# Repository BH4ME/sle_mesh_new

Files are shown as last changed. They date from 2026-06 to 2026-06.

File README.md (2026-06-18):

# sle_mesh_new

WS63 SLE mesh firmware, board Web UI, browser Web UI, flashing tools, debug automation, and CAD STL assets.

Current packaged line: `v4.5.56-minimal`

## What Is Included

| Area | Path | Purpose |
| --- | --- | --- |
| WS63 firmware app | `xc/ws63_team_network/` | Unified leader/member/relay firmware, ST7789/LVGL display task, WS2812 status LED, GPS/location hooks, battery/ADC hooks, and board HTTP service. |
| Shared protocol/core | `include/`, `src/` | Portable SLE team packet, node state machine, CLI, location, relay optimizer, NMEA parser, and Web API code. |
| Web UI | `webui/` | Browser/board Web UI source and API contract tests. |
| Flash tools | `scripts/flash/`, `tools/xf_burn_tools/`, `automation/ws63/tools/ws63_auto_burn.py` | Windows and Python flashing workflows for WS63 `.fwpkg` images. |
| Build tools | `scripts/build/`, `automation/ws63/tools/ws63_remote_build_v4.py` | Local/remote SDK build wrappers and post-build guards. |
| Debug/test automation | `automation/ws63/`, `scripts/sim/`, `examples/` | Serial probes, exact-version audit, relay recovery hardware tests, double-reset tests, simulator and C regressions. |
| Hardware docs | `hardware/`, `docs/` | Board/enclosure documentation, schematics notes, task book, and repository docs. |
| CAD STL models | `cad/stl/` | Only the latest three versioned enclosure STL model sets. |
| Release firmware | `release/firmware/` | Latest known built package for direct flashing. |
| Release evidence | `release/evidence/` | Compact JSON summaries for hardware proof runs. |

## Current Hardware-Proven Status

`v4.5.56-minimal` is the current proof line with same-firmware compatibility fingerprint `SLE_TEAM_FW_COMPAT 0x0556U`.

The exact-version 8-board relay recovery run passed:

- Summary: `release/evidence/v4_5_56_exact8_relay_recovery_summary.json`
- Leader: `COM51`, route `166`, suffix `227F`
- Members: `COM32/175`, `COM40/127`, `COM42/81`, `COM47/181`, `COM50/158`, `COM52/182`, `COM58/37`
- Initial relay: `COM42/81`
- Replacement relay after relay reboot: `COM52/182`
- Old relay `81` returned as a non-relay member under relay `182`
- Final relay set: `[182]`
- No `Oops`, exception, NMI, or runtime reboot markers were found in the proof logs

The same board pool also printed SoftAP, HTTP, LVGL backend, and ST7789 startup logs. AP client visibility scanning was intentionally not performed for this proof pass. WS2812 color/brightness has no readback channel, so final LED appearance still requires physical observation on real boards.

## Flash The Included Firmware

Firmware package:

```text
release/firmware/ws63-liteos-app_v4_unified_all_v4.5.56-minimal.fwpkg
```

Windows multi-port flash:

```powershell
powershell -NoProfile -ExecutionPolicy Bypass -File scripts/flash/ws63_flash_multi.ps1 `
  -Ports COM32,COM40,COM42,COM47,COM50,COM51,COM52,COM58 `
  -Parallel `
  -Firmware release\firmware\ws63-liteos-app_v4_unified_all_v4.5.56-minimal.fwpkg `
  -ExpectedVersion v4.5.56-minimal
```

Single-port Python burn:

```powershell
python automation\ws63\tools\ws63_auto_burn.py `
  -p COM51 `
  -b 115200 `
  --software-reset-only `
  --reset-command reboot `
  release\firmware\ws63-liteos-app_v4_unified_all_v4.5.56-minimal.fwpkg
```

Audit exact versions and idle state:

```powershell
python automation\ws63\tools\ws63_audit_versions_and_idle_bad.py `
  --ports COM32 COM40 COM42 COM47 COM50 COM51 COM52 COM58 `
  --expected-fw v4.5.56-minimal
```

## Run Relay Recovery Hardware Test

```powershell
python automation\ws63\tools\ws63_multi_board_relay_recovery_test.py `
  --leader-port COM51 `
  --member-ports COM32 COM40 COM42 COM47 COM50 COM52 COM58 `
  --expected-fw v4.5.56-minimal `
  --team-id 159 `
  --channel 189 `
  --direct-cap 3 `
  --log-dir logs\hardware\v4_5_56_exact8_relay_recovery
```

## Build Firmware

Remote Ubuntu SDK build:

```powershell
python automation\ws63\tools\ws63_remote_build_v4.py `
  --host <ubuntu-host> `
  --user <ubuntu-user> `
  --password <password>
```

Do not commit local credentials. The build wrapper performs source and package guards for the active proof line.

## Web UI

```powershell
npm --prefix webui install
npm --prefix webui test
npm --prefix webui run build
```

The board HTTP/Web code is in `xc/ws63_team_network/src/ws63_team_http.*` and the browser UI is in `webui/src/`.

## Local Validation

```powershell
python -m unittest discover -s automation/ws63/tests -t .
python -m py_compile automation/ws63/tools/ws63_remote_build_v4.py automation/ws63/tools/ws63_auto_burn.py
bash scripts/sim/simulate_v2.sh --suite=core
git diff --check
```

## Repository Notes

- Full hardware logs, temporary build outputs, local planning files, and large generated CAD formats are intentionally excluded from Git.
- STL files are included under `cad/stl/`; only the latest three versioned model sets are kept.
- LVGL core source needed by the firmware build is vendored under `xc/ws63_team_network/third_party/lvgl/`; demo/media assets are intentionally omitted.
- The repository is intended to be a clean handoff package, not the full local laboratory log archive.

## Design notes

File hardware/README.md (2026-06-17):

# Hardware

这个目录用于存放 SLE 项目的硬件资料和可制造文件。硬件资料与固件源码、自动化脚本分开管理，避免仓库根目录堆放临时模型或草稿文件。

## 目录

- [enclosures/](enclosures/)：3D 打印外壳、STEP/STL、预览图和源模型脚本。
- `boards/`：预留给 PCB、Gerber、BOM、装配图和板卡 3D 模型。
- `schematics/`：预留给原理图、接口定义和硬件审查记录。

## 当前硬件资料

- [boards/sle-main-board/v3.3](boards/sle-main-board/v3.3/)：2026-06-16 SLE 主板 PCB PDF 和板卡预览图。
- [schematics/sle-main-board/v3.3](schematics/sle-main-board/v3.3/)：2026-06-16 SLE 主板原理图 PDF。

## 版本规则

- 每个可制造硬件版本放在独立目录，例如 `hardware/enclosures/sle-pcb-enclosure/v1.1.4/`。
- 每个版本至少包含 `README.md` 和 `MANIFEST.md`。
- STEP/STL/PNG 等二进制或大型制造文件按类型放入 `step/`、`stl/`、`preview/`。
- 草稿、临时预览、审查截图和未确认模型不要直接放仓库根目录，确认可发布后再整理进本目录。

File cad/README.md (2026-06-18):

# CAD Assets

This directory contains the STL files kept for the handoff repository.

- `stl/models/...` contains only the latest three versioned enclosure model sets:
  - `sle_enclosure_v2.1.17_no_screen_top_lock`
  - `sle_enclosure_v2.1.18_no_screen_top_lock_harder`
  - `sle_enclosure_v2.1.19_screen_top_lock`

Large STEP/GLB simulation exports are intentionally excluded from Git. Re-add them through release assets or Git LFS if they become required for mechanical handoff.

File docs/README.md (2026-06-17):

# Documentation Index

这里是 SLE 项目的文档入口。

## 仓库维护

- [repository_layout.md](repository_layout.md)：仓库目录结构和边界。
- [version_management.md](version_management.md)：仓库、固件和硬件版本管理规则。
- [branch_strategy.md](branch_strategy.md)：分支角色和合并策略。
- [../versions/README.md](../versions/README.md)：版本记录索引。
- [../meta/PROJECT_OPERATION_SOP.md](../meta/PROJECT_OPERATION_SOP.md)：项目操作 SOP。

## 阶段文档

- [v0/README.md](v0/README.md)：V0 baseline。
- [v1/README.md](v1/README.md)：V1 manual relay approval。
- [v2/README.md](v2/README.md)：V2 automatic networking。
- [v3/README.md](v3/README.md)：V3 phone location bridge。
- [v4/README.md](v4/README.md)：V4 WS63 module、ST7789 display、offline reporting。

## 硬件资料

- [../hardware/README.md](../hardware/README.md)：硬件资料和制造文件入口。
- [../hardware/enclosures/README.md](../hardware/enclosures/README.md)：3D 打印外壳版本。

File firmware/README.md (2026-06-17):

# Firmware

固件代码按 SDK 工程边界管理。

## 当前固件工程

- [../xc/ws63_team_network/](../xc/ws63_team_network/)：WS63 SLE team network 固件工程，包含板端 WebUI、ST7789 显示、SLE leader/member/relay 运行时配置逻辑。
- [../xc/bearpi_pico_h3863_blinky/](../xc/bearpi_pico_h3863_blinky/)：BearPi Pico H3863 blinky / flash notes 辅助工程。

## 协议共享代码

- [../include/](../include/)：公共头文件。
- [../src/](../src/)：协议、组网状态机、CLI/Web API 序列化。
- [../examples/](../examples/)：本地 C 回归和接入示例。

## 版本边界

- 当前固件版本：`v4.4.129`，定义在 `xc/ws63_team_network/src/ws63_team_network_app.c`。
- 当前仓库整理记录：`v4.4.129`，见 [../versions/v4.4.129/VERSION.md](../versions/v4.4.129/VERSION.md)。
- 构建产物不提交到 Git；远程构建输出默认写入 `output_from_vm/`。

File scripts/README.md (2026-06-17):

# Scripts

脚本按用途隔离，根目录不再直接堆放可执行脚本。

## 分类

- [build/](build/)：固件构建脚本，包括远程 Ubuntu、VM、WSL 构建入口。
- [flash/](flash/)：烧录脚本，包括单板和多串口烧录。
- [serial/](serial/)：串口运行时配置脚本。
- [sim/](sim/)：协议和 relay 行为仿真脚本。
- [test/](test/)：测试总入口和系统级编排入口。
- [review/](review/)：文档/代码审查辅助脚本。

## 常用入口

```sh
scripts/build/ws63_build_v4_ubuntu.sh unified
scripts/sim/simulate_v2.sh --suite=python --stress=1
python -m unittest discover -s automation/ws63/tests -t .
```

```powershell
powershell -ExecutionPolicy Bypass -File scripts/serial/ws63_serial_cfg.ps1 -Port COM16 -Mode status
powershell -NoProfile -ExecutionPolicy Bypass -File scripts/flash/ws63_flash_multi.ps1 -Ports COM16,COM13,COM17,COM18 -Parallel
```

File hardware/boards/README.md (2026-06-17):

# Boards

这里预留给 SLE 硬件板卡资料。

## 当前资料

- [sle-main-board/v3.3](sle-main-board/v3.3/)：2026-06-16 SLE 主板 PCB PDF 和预览图。

建议每块板按版本建目录，例如：

```text
hardware/boards/sle-main-board/v1.0.0/
```

每个版本建议包含：

- `README.md`：板卡用途、版本摘要、接口说明。
- `MANIFEST.md`：Gerber、BOM、装配图、3D 模型和验证记录清单。
- `gerber/`：可制造 Gerber/钻孔文件。
- `bom/`：BOM 和替代料说明。
- `assembly/`：装配图、位号图、生产注意事项。
- `step/`：板卡 3D 模型。

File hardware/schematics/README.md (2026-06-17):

# Schematics

这里预留给原理图、接口定义和硬件审查记录。

## 当前资料

- [sle-main-board/v0.1](sle-main-board/v0.1/)：早期 SLE 主板原理图参考。
- [sle-main-board/v3.3](sle-main-board/v3.3/)：2026-06-16 SLE 主板原理图 PDF。

建议按硬件版本保存，例如：

```text
hardware/schematics/sle-main-board/v1.0.0/
```

原理图 PDF、接口表、已确认的问题记录和修改建议都应放在对应版本目录中，避免散落在仓库根目录。

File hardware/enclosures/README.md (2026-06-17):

# Enclosures

这个目录保存 SLE 设备的 3D 打印外壳版本。

## 当前外壳

- [sle-pcb-enclosure/v1.1.4](sle-pcb-enclosure/v1.1.4/)：一体式外壳 + 电池滑盖，已整理为首个公开制造版本。

## 命名

- 外壳系列目录：`sle-pcb-enclosure`
- 版本目录：`v<major>.<minor>.<patch>`
- 文件名保留版本号，便于单独下载后仍能识别来源。

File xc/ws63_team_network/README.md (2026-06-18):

# WS63 Team Network Firmware

这是当前 WS63 SLE team network 板端固件工程。

## 当前版本

- 固件版本：`v4.4.134`
- 仓库整理记录：`v4.4.134`
- 版本说明：[../../versions/v4.4.134/VERSION.md](../../versions/v4.4.134/VERSION.md)
- 仓库结构说明：[../../docs/repository_layout.md](../../docs/repository_layout.md)

## 功能

- 统一固件包：leader/member 角色运行时配置。
- 板端 SoftAP + HTTP WebUI。
- 串口 `cfg` 命令配置角色、team、channel 和 leader suffix。
- leader/member/relay 自适应连接与中继。
- ST7789 显示在线状态和成员事件。
- WS2812、蜂鸣器、GPS pinmap、HTTP API 等板级能力。

## 串口命令

```text
cfg status
cfg leader now <team> <channel>
cfg member now <leader_suffix_hex> <team> <channel>
cfg apply
cfg clear
cfg reboot
reboot
reset
```

Windows 辅助脚本：

```powershell
powershell -ExecutionPolicy Bypass -File scripts/serial/ws63_serial_cfg.ps1 -Port COM16 -Mode leader -Team 7 -Channel 33
powershell -ExecutionPolicy Bypass -File scripts/serial/ws63_serial_cfg.ps1 -Port COM13 -Mode member -LeaderSuffix 9A2F -Team 7 -Channel 33
powershell -ExecutionPolicy Bypass -File scripts/serial/ws63_serial_cfg.ps1 -Port COM13 -Mode status
```

## 板端 WebUI

```text
SSID: SLE-XXXX
Password: 123456789
URL: http://192.168.43.1/
```

常用 API：

- `GET /api/status`
- `GET /api/power`
- `GET /api/nodes`
- `GET /api/events`
- `GET /api/pending`
- `GET /api/config/status`
- `GET /api/config/leader?team=1&channel=17&now=1`
- `GET /api/config/member?leader=C7E9&team=1&channel=17&now=1`
- `GET /api/config/apply`
- `GET /api/config/clear`
- `GET /api/config/reboot`
- `GET /api/pairing?action=start|stop|approve&id=...&relay=0|1`
- `GET /api/member/select?team=...&leader=...&channel=...`
- `GET /api/member/leave`
- `GET /api/factory-reset`

## 构建

推荐使用仓库根目录的远程构建脚本：

```sh
scripts/build/ws63_build_v4_ubuntu.sh unified
```

输出固件包：

```text
output_from_vm/team_network_v4_unified_runtime_role/ws63-liteos-app_v4_unified_all.fwpkg
```

## 目录

- `src/`：板端应用、显示、LED 等实现。
- `sle_uart_client/`：leader/client/central 侧 SLE UART 适配。
- `sle_uart_server/`：member/server/peripheral 侧 SLE UART 适配。
- `third_party/lvgl-patches/`：WS63 LVGL 适配补丁。
- `CMakeLists.txt`、`Kconfig`：SDK 工程集成入口。

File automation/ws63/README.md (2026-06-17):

# WS63 Automation

`automation/ws63/` 是 WS63 自动化工具链，负责烧录编排、串口预检、角色绑定和多板 relay 测试。它与固件源码、仿真脚本和通用工具分开管理。

## 目录结构

- `tools/`
  - `ws63_auto_burn.py`：自动复位烧录工具，支持串口 `reboot` 和 DTR/RTS 控制序列。
  - `ws63_flash_bind_team.py`：批量烧录并绑定角色。
  - `ws63_four_board_relay_test.py`：四板 leader/member/relay 场景测试。
  - `ws63_link_cycle_test.py`：member 生命周期、重启、leave/rejoin 测试。
  - `ws63_relay_cycle_test.py`：relay 重启和 relay 自举场景测试。
  - `ws63_remote_build_v4.py`：Python/Paramiko 远程构建入口。
  - `ws63_serial_preflight.py`：串口测试前置检查。
- `scripts/`
  - `ws63_test_system.sh`：自动化总入口。
- `tests/`
  - 自动化工具单元测试。

## 与其他目录的边界

- 固件构建脚本：`scripts/build/`
- 烧录脚本：`scripts/flash/`
- 串口配置脚本：`scripts/serial/`
- 仿真脚本：`scripts/sim/`
- 通用仿真工具：`tools/sle_team_python_sim.py`

## 常用命令

```sh
python -m unittest discover -s automation/ws63/tests -t .
bash automation/ws63/scripts/ws63_test_system.sh --with-relay-cycle --ports COM16,COM13,COM17
```

```powershell
python automation/ws63/tools/ws63_auto_burn.py -p COM16 -b 115200 --software-reset-only output_from_vm/team_network_v4_unified_runtime_role/ws63-liteos-app_v4_unified_all.fwpkg
```

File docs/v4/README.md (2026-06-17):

# V4 Documentation

`docs/v4/` 记录 WS63 模块、ST7789 显示、板端 WebUI、运行时角色配置和 relay 组网验证相关内容。

## 当前主线

- 当前固件版本：`v4.4.129`
- 最新仓库整理记录：`v4.4.129`
- 固件工程：[../../xc/ws63_team_network/](../../xc/ws63_team_network/)
- 硬件原理图：[../../hardware/schematics/sle-main-board/v0.1/](../../hardware/schematics/sle-main-board/v0.1/)
- 远程构建脚本：[../../scripts/build/ws63_build_v4_ubuntu.sh](../../scripts/build/ws63_build_v4_ubuntu.sh)
- 烧录脚本：[../../scripts/flash/](../../scripts/flash/)
- 仿真脚本：[../../scripts/sim/](../../scripts/sim/)

## V4 能力边界

- 所有 WS63 节点烧录同一份统一固件包。
- leader/member 角色通过 WebUI 或串口 `cfg` 命令在运行时配置。
- leader 支持 pending/member 管理、配队窗口、allowlist 和成员在线/离线事件。
- member 可直连 leader，也可在 leader 直连容量受限时通过 relay 转发。
- relay 选择由固件根据连接状态、RSSI 和 relay budget 自适应处理。
- ST7789 显示用于角色、在线状态、成员事件和故障提示。

## 常用入口

```sh
scripts/build/ws63_build_v4_ubuntu.sh unified
scripts/sim/simulate_v2.sh --suite=python --stress=1
python -m unittest discover -s automation/ws63/tests -t .
```

```powershell
powershell -ExecutionPolicy Bypass -File scripts/serial/ws63_serial_cfg.ps1 -Port COM16 -Mode status
powershell -NoProfile -ExecutionPolicy Bypass -File scripts/flash/ws63_flash_multi.ps1 -Ports COM16,COM13,COM17,COM18 -Parallel
```

## 历史记录

详细发布历史见 [../../versions/README.md](../../versions/README.md)。当前仓库结构以 [../repository_layout.md](../repository_layout.md) 和根目录 [../../README.md](../../README.md) 为准。

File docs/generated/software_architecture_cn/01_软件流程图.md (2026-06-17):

# 01 软件流程图

本节描述当前 `v4.5.46-minimal` 软件从启动到运行的主流程。系统核心由两个主要任务组成：

- `TeamNetworkTask`：负责组网、SLE 收发、HTTP、CLI、GPS、状态 LED、核心状态机 tick。
- `TeamDisplayTask`：负责 ST7789/LVGL 初始化、状态页面刷新、事件页面刷新。

## 软件启动流程

```mermaid
flowchart TD
    Boot["固件启动"] --> Entry["team_network_entry"]
    Entry --> SpawnDisplay["创建 TeamDisplayTask"]
    Entry --> SpawnNetwork["创建 TeamNetworkTask"]

    SpawnDisplay --> DisplayInit["初始化 ST7789 / LVGL"]
    DisplayInit --> DisplayLoop["显示循环: 读取快照 -> 刷新状态/事件 -> tick"]

    SpawnNetwork --> Bootstrap["team_network_task_bootstrap"]
    Bootstrap --> LedInit["初始化 WS2812 状态灯"]
    Bootstrap --> GpsInit["初始化 GPS/NMEA"]
    Bootstrap --> Identity["读取 MAC 并生成 route_id/self_label"]
    Bootstrap --> HttpStart["启动 SoftAP HTTP 服务"]
    Bootstrap --> UartCli["启动 UART CLI"]
    Bootstrap --> NvRestore["读取 NV 保存的角色配置"]
    NvRestore --> RoleConfigured{"是否已有角色配置?"}

    RoleConfigured -- 否 --> Idle["保持未配置状态, 等待 Web/CLI 配置"]
    RoleConfigured -- 是 --> ConfigureRole["配置 leader 或 member 角色"]
    ConfigureRole --> SleStart["启动 SLE client/server"]
    SleStart --> MainLoop["进入 TeamNetworkTask 主循环"]
    Idle --> MainLoop
```

## 主循环流程

```mermaid
flowchart TD
    Loop["TeamNetworkTask 每 10ms 循环"] --> Cli["处理 CLI 队列"]
    Cli --> ClientTick["SLE client tick"]
    ClientTick --> Configured{"角色已配置?"}

    Configured -- 否 --> Sleep["sleep 10ms"]
    Configured -- 是 --> NodeTick["sle_team_node_tick"]

    NodeTick --> Role{"当前角色"}
    Role -- Leader --> LeaderScan["更新 leader 扫描策略"]
    LeaderScan --> RelayOpt["每 8s 尝试稳定态 relay 优化"]
    RelayOpt --> RelayClient["检查 relay client 是否需要启动/暂停"]

    Role -- Member --> RelayClient

    RelayClient --> GpsTick["GPS 定位上报 tick"]
    GpsTick --> LedTick["WS2812 状态刷新"]
    LedTick --> DisplayPub["发布显示状态快照"]
    DisplayPub --> Sleep
```

## 收包处理流程

```mermaid
flowchart TD
    Rx["SLE 收到数据"] --> DecodeMesh["解码 Mesh Packet"]
    DecodeMesh --> Unwrap["解 GROUP_DATA: channel_hash / cipher_mac / app_payload"]
    Unwrap --> DecodeApp["解码 App Packet"]
    DecodeApp --> Check["校验 team_id / channel_hash / leader_term"]
    Check --> NeedForward{"是否不是发给自己?"}

    NeedForward -- 是 --> Forward["relay 节点转发"]
    NeedForward -- 否 --> Dispatch["按 app_msg_type 分发"]

    Dispatch --> Hello["HELLO: 入网/重入网"]
    Dispatch --> Ack["ACK: 确认策略下发"]
    Dispatch --> Config["CONFIG: 更新心跳/relay 参数"]
    Dispatch --> Route["ROUTE_UPDATE: 更新 parent/next_hop"]
    Dispatch --> Heartbeat["HEARTBEAT: 更新 last_seen/RSSI/在线状态"]
    Dispatch --> Pos["POS_REPORT: 更新位置"]
    Dispatch --> Alert["ALERT: 离队/超时/低电量等告警"]
```

## 发送流程

```mermaid
flowchart TD
    Business["业务消息: HELLO/HEARTBEAT/POS/ALERT/CONFIG/ACK/ROUTE_UPDATE"] --> AppBuild["编码 App Packet"]
    AppBuild --> GroupWrap["封装 GROUP_DATA"]
    GroupWrap --> MeshWrap["封装 Mesh Packet"]
    MeshWrap --> Role{"发送节点角色"}

    Role -- Leader --> FindConn["按 dst_id / next_hop 找 SLE client 连接"]
    Role -- Member --> Upstream["通过 server 连接发给 parent/leader"]
    Role -- Relay --> Downstream["relay 可通过 client 连接发给 child"]

    FindConn --> SleSend["WS63 SLE 发送"]
    Upstream --> SleSend
    Downstream --> SleSend
```

## 状态显示流程

```mermaid
flowchart TD
    NetworkTask["TeamNetworkTask"] --> PublishStatus["发布 role/self/online/offline/event_count"]
    NetworkTask --> PublishEvent["发布 join/rejoin/lost/left 事件"]
    PublishStatus --> Shared["共享显示快照"]
    PublishEvent --> Shared
    Shared --> DisplayTask["TeamDisplayTask"]
    DisplayTask --> ShowStatus["ws63_st7789_show_status"]
    DisplayTask --> ShowEvent["ws63_st7789_show_event"]
    DisplayTask --> Tick["ws63_st7789_tick"]
    Tick --> Panel["ST7789 屏幕"]
```

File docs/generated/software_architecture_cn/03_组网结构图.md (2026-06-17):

# 03 组网结构图

本节描述当前系统的正常组网结构。系统采用 leader 集中式组网，leader 持有成员表并统一分配拓扑。

## 正常拓扑

```mermaid
flowchart TD
    Leader["Leader"] --> Direct1["直连 Member A"]
    Leader --> Direct2["直连 Member B"]
    Leader --> Relay1["Relay Member"]
    Relay1 --> Child1["Relay Child 1"]
    Relay1 --> Child2["Relay Child 2"]
```

## 组网角色

| 角色 | 职责 |
|---|---|
| Leader | 维护成员表、扫描入网、分配 parent/next_hop、下发 CONFIG/ROUTE_UPDATE、处理掉线恢复 |
| Member | 向 leader 发 HELLO/HEARTBEAT/POS，按 leader 指令工作 |
| Relay Member | 既是 member 又是 child 转发节点，承担下游连接 |
| Relay Child | 挂在 relay 下面的普通成员 |

## 组网规则

```mermaid
flowchart TD
    Candidate["节点开始入网"] --> Hello["发送 HELLO"]
    Hello --> LeaderCheck["Leader 检查 team/channel/fw_compat"]
    LeaderCheck --> Allowed{"是否允许入队?"}

    Allowed -- 否 --> Reject["拒绝或进入 pending"]
    Allowed -- 是 --> Decide["决定 parent"]

    Decide --> DirectFree{"leader 直连是否未满?"}
    DirectFree -- 是 --> ParentLeader["parent = leader"]
    DirectFree -- 否 --> PickRelay["选择在线 relay"]
    PickRelay --> ParentRelay["parent = relay / next_hop = relay"]

    ParentLeader --> SendPolicy["下发 CONFIG + ROUTE_UPDATE"]
    ParentRelay --> SendPolicy
    SendPolicy --> Ack["收到 ACK 或 live packet 确认"]
    Ack --> Online["节点 ONLINE"]
```

## 直连容量

当前逻辑中 leader 默认直连容量为 7，见 [sle_team_node.c](E:/codex_documents/sle/src/sle_team_node.c:4)。当直连数达到上限时，leader 会优先选择一个在线且允许 relay 的成员升级为 relay，再把后续成员挂到该 relay 下。

## 版本隔离

每个 HELLO 都携带 `fw_compat`，leader 在处理入网时会校验兼容指纹。这样不同 proof line 的固件不会在同一队伍里混连。

## 任务边界

- `TeamNetworkTask` 负责组网决策和成员表更新。
- `TeamDisplayTask` 只负责展示，不参与组网。
- HTTP 和串口只是控制入口，不改变组网原则。

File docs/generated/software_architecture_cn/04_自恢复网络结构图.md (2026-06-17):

# 04 自恢复网络结构图

本节描述节点掉线后的自恢复机制。当前系统不是全网重建，而是局部修复受影响的拓扑分支。

## 自恢复总流程

```mermaid
flowchart TD
    Lost["节点掉线/重启/信号丢失"] --> Detect["检测到断连或心跳超时"]
    Detect --> LeaderMark["Leader 标记成员 offline"]
    LeaderMark --> RelayLost{"掉线的是 relay 吗?"}

    RelayLost -- 否 --> MemberRecover["普通 member 重新 HELLO, leader 重新分配 parent"]
    RelayLost -- 是 --> ChildMark["标记 relay 的 child 为恢复候选"]
    ChildMark --> Choose["选择 replacement relay"]
    Choose --> Grant["给 replacement relay 下发 relay 授权"]
    Grant --> Rewire["重挂 child 到新 relay"]
    Rewire --> Resume["原 relay 回来后降级为普通 child"]
```

## relay 掉线恢复结构

```mermaid
flowchart TD
    OldRelay["旧 Relay 掉线"] --> LeaderOffline["Leader 标记 relay offline"]
    LeaderOffline --> Affected["把 parent=旧 Relay 的节点标记为恢复候选"]
    Affected --> Candidate["选择替代 relay"]
    Candidate --> RelayGrant["下发 relay_allowed=1 / relay_tier=1"]
    RelayGrant --> NewRelay["新 Relay 接管"]
    NewRelay --> Children["旧 relay 的 child 重新挂到新 Relay"]
    Children --> OldReturn["旧 Relay 恢复上线"]
    OldReturn --> Demote["旧 Relay 降级为普通 child"]
```

## 普通 member 掉线恢复

```mermaid
flowchart TD
    MemberLost["普通 member 掉线"] --> LeaderOffline["Leader 标记 offline"]
    LeaderOffline --> Scan["恢复扫描/重新发现"]
    Scan --> Hello["member 重启后重新发 HELLO"]
    Hello --> Parent["Leader 重新分配 parent / next_hop"]
    Parent --> Config["下发 CONFIG + ROUTE_UPDATE"]
    Config --> Ack["ACK / HEARTBEAT 确认"]
    Ack --> Online["重新 ONLINE"]
```

## 代码中的关键机制

| 机制 | 作用 |
|---|---|
| `sle_team_mark_member_offline()` | 将成员标记为离线，并处理 relay 相关的下游恢复 |
| `sle_team_mark_relay_children_offline()` | relay 掉线时把它的 child 转成恢复候选 |
| `sle_team_assign_parent()` | 决定 member 当前应该挂到 leader 还是 relay |
| `sle_team_handle_hello()` | 节点回来后重新入网和重新下发策略 |
| `sle_team_handle_heartbeat()` | 用心跳更新在线状态并完成恢复确认 |
| `team_leader_drop_stale_direct_conn()` | 清理旧直连残留，防止恢复中拓扑污染 |

## 自恢复原则

1. 只修复受影响分支，不全网重组。
2. 以 leader 为唯一拓扑裁决点。
3. 新策略优先生效，旧连接必须被清理。
4. relay 恢复后默认先降级为普通 child，避免重复抢占拓扑。
5. 通过 ACK、HEARTBEAT、位置包共同确认在线，而不是只靠单一事件。

## 适合文档中的一句话

> 本系统的自恢复组网采用 leader 集中式局部修复策略：当普通 member 掉线时重新分配 parent，当 relay 掉线时只重构其下游分支，并通过 `ROUTE_UPDATE`、`CONFIG`、`ACK` 和心跳包共同完成恢复确认。

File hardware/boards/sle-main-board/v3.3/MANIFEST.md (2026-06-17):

# Manifest: SLE Main Board PCB v3.3

## Files

- `README.md`
- `MANIFEST.md`
- `PCB_PCB1_3_2026-06-16.pdf`
- `preview/layout_render_1.png`
- `preview/layout_render_2.png`

## Source Files

- `/Users/bh4me_macair/Documents/研电赛/v3.3硬件/PCB_PCB1_3_2026-06-16.pdf`
- `/Users/bh4me_macair/Documents/研电赛/v3.3硬件/60443e9e08896b85dec1826dff4f5deb.png`
- `/Users/bh4me_macair/Documents/研电赛/v3.3硬件/acd43c83f5d05ca2e75e8261679cb1cf.png`

## Notes

- Imported into `hardware/boards/sle-main-board/v3.3/` as the SLE main board v3.3 hardware architecture package.
- File names were normalized for stable repository links while keeping source paths above for traceability.

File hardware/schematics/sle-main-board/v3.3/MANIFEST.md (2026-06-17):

# Manifest: SLE Main Board Schematic v3.3

## Files

- `README.md`
- `MANIFEST.md`
- `SCH_Schematic1_3_2026-06-16.pdf`

## Source Files

- `/Users/bh4me_macair/Documents/研电赛/v3.3硬件/SCH_Schematic1_3_2026-06-16(MacBook-Air-4.local的冲突副本1_2026-06-16 10-58-29).pdf`

## Notes

- Imported into `hardware/schematics/sle-main-board/v3.3/` as the SLE main board v3.3 schematic package.
- The source filename was normalized to remove the local conflict-copy suffix while preserving source traceability here.

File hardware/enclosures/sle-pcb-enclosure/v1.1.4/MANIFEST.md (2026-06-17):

# Manifest: SLE PCB Enclosure v1.1.4

## Files

- `README.md`
- `MANIFEST.md`
- `source/sle_enclosure_v1.1.4_source.py`
- `step/sle_enclosure_v1.1.4_one_piece_shell.step`
- `step/sle_enclosure_v1.1.4_battery_slide_cover.step`
- `step/sle_enclosure_v1.1.4_preview.step`
- `stl/sle_enclosure_v1.1.4_one_piece_shell.stl`
- `stl/sle_enclosure_v1.1.4_battery_slide_cover.stl`
- `preview/sle_enclosure_v1.1.4_preview_bottom.png`
- `preview/sle_enclosure_v1.1.4_preview_iso.png`
- `preview/sle_enclosure_v1.1.4_preview_top.png`
- `preview/sle_enclosure_v1.1.4_slide_cover_iso.png`

## Validation

- Source model: copied from the local v1.1.4 enclosure source.
- Printable STL geometry: recorded as watertight, winding consistent, one component for both shell and slide cover.
- STEP files: preview assembly, one-piece shell, and battery slide cover inspection passed before publication.

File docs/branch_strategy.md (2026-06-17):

# Branch Strategy

This repository keeps multiple WS63/SLE directions alive without forcing them
into one mainline.

## Long-lived Branches

| Branch | Purpose | Merge policy |
| --- | --- | --- |
| `main` | Stable repository index, shared docs, and known-good public entry points. | Keep clean. Do not merge lab or direction-specific experiments by default. |
| `line/v1-manual-relay` | V1 manual relay approval flow. | Maintain independently. Cherry-pick only small shared fixes when useful. |
| `line/v2-auto-networking` | V2 automatic networking and relay failover line. | Maintain independently and tag releasable alpha/beta points. |
| `line/v3-phone-location` | V3 phone geolocation bridge and SLE position distribution. | Branch from a suitable V2 point and evolve independently. |
| `lab/ws63-st7789-display` | WS63 ST7789 135x240 TFT display experiments. | Lab-only. Do not merge into V1/V2/V3 unless display becomes a product feature. |

Older temporary development branches may remain only as local history. The
`line/...`, `release/...` and `lab/...` names are the canonical working branches
going forward.

## Release Markers

Use tags to freeze points that are known to build or demonstrate a feature:

- `v1.x.y` for the V1 line.
- `v2.0.0-alphaN` for V2 automatic networking.
- `v3.0.0-alphaN` for V3 phone location work.
- `display-st7789-alphaN` for display-only lab checkpoints.

Each tagged point should document:

- What the branch demonstrates.
- How to build or flash it.
- Which validation command or board test was run.

## Daily Workflow

1. Choose the branch that matches the goal before editing.
2. Keep feature commits on that branch.
3. Push the branch directly to GitHub for backup and review.
4. Use PRs only when intentionally moving changes between branches.
5. Prefer cherry-picking small shared fixes over merging whole experimental lines.

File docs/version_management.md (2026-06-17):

# Version Management

## 版本类型

- 仓库记录版本：记录目录整理、脚本布局、文档和硬件资料等仓库层面的变化。
- 固件版本：记录会影响 WS63 固件行为或烧录包的变化。
- 硬件版本：记录 PCB、外壳、装配资料和可制造文件的变化。

## 当前状态

- 最新仓库记录：`v4.4.129`
- 当前固件版本：`v4.4.129`
- 当前外壳版本：`hardware/enclosures/sle-pcb-enclosure/v1.1.4`

## 发布规则

- 固件行为变化时，同步更新固件源码中的版本字符串、`versions/<version>/VERSION.md` 和 `MANIFEST.md`。
- 仅目录、文档、脚本布局变化时，可以更新仓库记录版本，但不要冒充固件升级。
- 硬件资料发布时，在 `hardware/<category>/<name>/<version>/` 下放置 `README.md` 和 `MANIFEST.md`。
- 每次提交前执行与变更范围匹配的校验，例如脚本单测、WebUI 测试、仿真或远程构建。

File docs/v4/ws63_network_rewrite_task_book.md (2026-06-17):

# WS63 Minimal Networking Rewrite Task Book

## Decision

Stop patching the existing staged/frozen topology networking code. Delete the old networking strategy layer and rewrite the smallest usable leader/member/relay logic from a blank design.

This task book replaces the previous staged rewrite plan. The old plan is no longer the target.

## What "Delete All Networking" Means

Delete the old group-networking algorithm and its patch chain:

- staged leader states such as `DISCOVERING`, `FREEZING`, `PROVISIONING`, and `STABLE`;
- frozen topology planning;
- topology policy queues;
- stable rejoin leases;
- failover windows;
- route hint caches;
- provisional physical peer authorization tricks;
- relay auto-promote/rebalance/swap logic;
- special HELLO/JOINED/temporary-direct patch paths.

Keep only the non-negotiable firmware base needed to build and test:

- SLE UART client/server transport drivers;
- packet encode/decode helpers;
- UART CLI, status output, build, flash, and readback tools;
- board identity, version, and anti-pollution cleanup.

If a retained file still contains old networking decisions, remove those decisions from that file.

## Minimal Target

The first rewrite target is not clever. It is a small deterministic network:

1. Leader discovers members.
2. Leader assigns each member exactly one parent:
   - parent is the leader while stable direct slots are available;
   - otherwise parent is one currently online leader-direct relay.
3. Member accepts only the latest leader policy.
4. Relay forwards packets between its children and the leader. It does not choose topology.
5. Heartbeat timeout marks a member offline.
6. A rejoining member is treated as fresh and receives a new parent assignment.

Stable-state rule: no global regrouping, no periodic rebalance, and no parent movement just to improve topology.

Loss-handling rule: real natural loss is not stable-state rebalance. Single-member loss, double-member loss, and relay loss must recover through fresh leader policy without shrinking the intended member count.

No stale parent or relay role may be reused unless the leader sends it again.

## Hard Limits

- Leader stable direct capacity is `direct_cap=7`.
- WS63 physical max is 8 links; one physical slot may be used as a temporary admission link.
- Do not reduce the desired member count to make tests pass.
- Natural loss means reboot, power loss, or distance/signal loss, not active `leave`.
- Failed-burn, wrong-version, or no-status boards must not join validation. They must be idle/unconfigured or excluded.
- Single-member and double-member natural loss must recover without shrinking the intended member set.
- Every fresh connection or reconnection must be treated as a policy event: the leader recalculates whether that node should be direct or relayed and sends a fresh assignment.
- In stable state, do not rebalance, regroup, or change an online member's parent just to improve topology. Parent changes are driven only by fresh join/rejoin or a real loss event.
- A relay that naturally disappears is no longer trusted as a relay when it comes back. On rejoin it is handled as a normal member and can receive whatever fresh leader policy currently fits.
- When a relay naturally disappears and its children still need service, the group must recover by admitting/selecting one replacement relay from affected children or available members under leader policy, using the spare physical slot when needed.
- When the original relay later comes back, it should first rejoin as a normal child/member under the replacement relay if that is the current valid topology. It must not automatically reclaim relay status just because it used to be a relay.
- Relay soft reboot, relay natural loss, and stable-state rebalance are three different cases. Soft reboot may restore the original relay quickly; natural relay loss must prove children recover while the original relay is absent.

## Minimal State

### Leader member table

Each member has only the fields needed for fresh policy, liveness, forwarding, and relay-loss recovery:

- `id`;
- `online`;
- `policy_pending`;
- `pending_ack_seq`;
- `parent_id`;
- `relay_allowed`;
- `last_seen_s`;
- `conn_id` if direct to leader;
- `child_count` if it is a relay.
- `relay_recovery_candidate` when the member was affected by a relay loss and may be selected as replacement.

The leader also keeps a small relay-loss recovery marker:

- `relay_recovery_pending`;
- `relay_recovery_lost_relay_id`;
- `relay_recovery_selected_id`.

### Member state

Each member has only:

- `leader_id`;
- `parent_id`;
- `joined`;
- `last_leader_seen_s`;
- `upstream_conn_id`;
- `relay_allowed`.
- `relay_discovery_only` only if needed to keep recovery discovery active without treating the node as fully joined.

### Route state

Route state is not a topology engine. It is only a forwarding table:

- direct member id to leader connection;
- child member id to relay connection;
- relay upstream connection to leader.

No inferred route may change parent policy. Only leader policy changes parent policy.

## Messages

Keep the packet vocabulary small:

- `HELLO`: member announces itself.
- `POLICY`: leader assigns `parent_id` and `relay_allowed`. In the current packet set this may be represented by `ROUTE_UPDATE` plus `CONFIG`.
- `ACK`: member confirms policy.
- `HEARTBEAT`: liveness.
- `DATA`: optional payload/position/status after join.

Existing packet structs may be reused if that keeps the build small, but old message semantics must not carry hidden topology behavior.

## Leader Algorithm

On `HELLO` or rejoin:

1. Update or create the member row.
2. Clear stale role assumptions from the previous incarnation of that member unless the fresh policy explicitly grants them again.
3. If direct leader slots are available, assign parent `leader`.
4. Else choose the best online leader-direct relay that still has child capacity.
5. "Best relay" is evaluated first by usable capacity, then by link quality evidence when available, then by lowest child count as the deterministic tie breaker.
6. Send `POLICY`.
7. Do not mark the member fully online until `ACK` or valid heartbeat arrives through the assigned path.

On heartbeat timeout:

1. Mark member offline.
2. If the lost member was not a relay, do not move healthy online members. The lost member rejoins later through fresh policy.
3. If the lost member was a relay, mark the relay and its children offline, then open a relay-loss recovery window.
4. During relay-loss recovery, admit or select exactly one replacement relay candidate through the spare physical slot. Prefer an affected child with recent liveness/RSSI evidence; otherwise use deterministic lowest child count / lowest id tie-breakers.
5. The replacement relay is not fully online until ACK or heartbeat confirms the fresh policy.
6. After replacement relay confirmation, affected children rejoin through fresh leader policy and attach under the replacement relay when direct capacity is full.
7. The original relay, if it returns after replacement, is handled as a normal member/child first. It must not reclaim relay status unless the leader later grants a fresh relay policy.

On stable online members:

1. Keep sending heartbeat/config only as needed for liveness.
2. Do not move a member between direct and relay parents while it remains healthy.
3. Do not promote/demote relays except when satisfying explicit relay target, handling a join/rejoin, or handling a real loss event.

## Member Algorithm

On boot/config:

1. Start unjoined.
2. Send `HELLO` until a leader `POLICY` arrives.
3. Connect to the assigned parent.
4. Send `ACK`.
5. Send heartbeat only through that parent.

On parent loss:

1. Clear `joined`.
2. Clear local parent connection.
3. Return to `HELLO` loop and wait for fresh leader policy.
4. Keep recovery discovery active so the node can hear leader/relay policy and, if selected, become the replacement relay. Do not pause scanning in a way that prevents recovery.

## Relay Algorithm

A relay is just a member with `relay_allowed=1`:

1. Maintain upstream connection to leader.
2. Accept children only when `relay_allowed=1` and child count is below capacity.
3. Forward child packets upstream.
4. Forward leader packets to known children.
5. Never assign another member's parent.
6. Never promote itself or another node.

## Code Rewrite Boundary

### Delete or replace

- Old networking code in `xc/ws63_team_network/src/ws63_team_network_app.c`.
- Old topology/rejoin/failover tests that assert the old staged design.
- Build guards that require old staged/frozen strings.
- Version notes that describe the staged rewrite as current target.

### Keep or simplify

- `src/sle_team_packet.c` and `include/sle_team_packet.h`, unless a smaller packet set is easier.
- `src/sle_team_node.c` only if it is reduced to the minimal leader/member state machine above.
- SLE UART client/server drivers as transport, with old policy decisions removed from the app layer.
- Flash/readback/cleanup automation.

## Implementation Phases

### Phase 1 - Strip old strategy

- Remove old staged/frozen topology requirements from docs and tests.
- Add tests that fail if old topology symbols remain in the active app source.
- Reduce the active app source to transport, CLI/status, identity, and one minimal networking loop.

### Phase 2 - Direct-only bring-up

- Leader plus up to `direct_cap=7` direct members.
- Validate join, heartbeat, natural reboot rejoin.
- No relay required in this phase.

### Phase 3 - Minimal relay

- Assign overflow members to existing leader-direct relays.
- Relay forwards only.
- Validate full member count can join without direct-cap overrun.

### Phase 4 - Natural loss

- Single member reboot recovery.
- Two member reboot recovery, sequenced through the spare physical link if needed.
- Rejoining members must receive a new direct/relay policy from the leader.

### Phase 5 - Relay natural-loss recovery

- Relay loss marks the relay and affected children offline, then opens a recovery window.
- One replacement relay is selected/admitted under leader policy through the spare physical slot.
- Affected children recover by fresh rejoin policy through the replacement relay.
- A recovered former relay rejoins as a normal member/child unless the leader explicitly grants relay again.
- Do not solve relay-loss recovery by reducing the number of intended members.

## Acceptance Criteria

- Source no longer contains the old staged/frozen topology strategy.
- Firmware builds with the minimal network logic.
- Burn/readback confirms the expected version.
- Direct-only join/reboot works first.
- Then relay overflow join works.
- Then single and double natural member reboot recovery work.
- Then relay natural loss recovers children through a replacement relay while the original relay is absent.
- The task is not complete until a hardware or strong simulation record proves single natural loss and double natural loss recover with the intended member count preserved.
- The task is not complete until relay natural loss recovery is proven separately from relay soft reboot.
- The task is not complete until wrong-version/no-status/burn-failed boards are shown idle or excluded before networking validation.
- Relay soft reboot, relay natural loss, and stable-state rebalancing are distinct tests and must not be treated as one proof.

Do not claim "networking is normal" until hardware logs prove the relevant phase.

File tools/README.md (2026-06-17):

# Tools

这个目录只保留通用开发工具。

- `sle_team_python_sim.py`：SLE team 网络 Python 仿真器。
- `test_sle_team_python_sim.py`：仿真器单元测试。
- `gen_ws63_console_header.mjs`：根据 WebUI/console 页面数据生成 WS63 端头文件。

WS63 烧录、角色绑定、串口预检和链路循环测试工具统一放在 [../automation/ws63/tools/](../automation/ws63/tools/)。

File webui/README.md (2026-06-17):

# SLE Team WebUI

这是 `sle_mesh` 的第一版 Web 控制台，参考 Meshtastic Web 和 MeshCore Web App 的产品形态，但数据模型和接口按本项目协议实现。

## 目标

- 域名上位机使用 Vite/TypeScript，可部署到 `sleweb.mecho.top`。
- WS63 板端使用 C 端 SSR，不运行前端 JS，保留 `Content-Length` 完整响应。
- 两端共享 `shared/console-pages.json` 里的产品名、入口、标签、空状态文案和配色。
- UI 通过 HTTP API 读取节点、消息和状态，不直接绑定某一种传输方式。

## 页面

- 总览：队伍状态、角色/配队控制、路由/中继指标、节点列表、消息流
- 数据包：输入十六进制包，按 `Mesh Packet -> GROUP_DATA -> App Packet` 解码
- 设置：连接方式、成员准入、板端部署和域名部署的接口说明

## 构建

```sh
npm install
npm run build
```

构建产物在：

```text
webui/dist/
```

当前产物很小，适合作为域名上位机或后续静态资源候选：

- JS gzip 约 12 KB
- CSS gzip 约 2.3 KB

注意：当前 WS63 烧录固件里的板端控制台不是直接烧录这份 Vite `dist`。为了省 RAM 并兼容 iOS/微信浏览器，板端继续使用 `xc/ws63_team_network/src/ws63_team_network_app.c` 的无 JS SSR 页面。共享内容由下面命令生成到 C 头文件：

```sh
node ../tools/gen_ws63_console_header.mjs
```

生成文件：

```text
xc/ws63_team_network/src/ws63_console_pages.h
```

## 运行

本地运行：

```sh
npm run dev
```

打开：

```text
https://localhost:5173/
```

默认不会显示假数据。进入“连接/设置”页或总览顶部可以切换：

- WiFi：填写任意一块带 HTTP API 的 WS63 地址，如 `http://192.168.43.1`
- 串口：选择 WebSerial 串口，默认 `115200`

域名上位机模式：

```text
https://sleweb.mecho.top/
https://sleweb.mecho.top/?api=http://192.168.43.1
```

如果页面和 API 同源，直接打开页面即可，不需要 `api` 参数。

注意：`https://sleweb.mecho.top` 是 HTTPS 页面。浏览器可能默认拦截它直接访问 `http://192.168.43.1` 这种私网 HTTP API。需要 WiFi 直连板端时，优先使用板端页面 `http://192.168.43.1/`；域名上位机更适合串口/WebSerial、后续 HTTPS 代理，或允许本地 HTTP 访问的浏览器环境。

部署提示（非隔离网络）：

- 外部门户 URL（例如 `sleweb.mecho.top`）应在发布后按运维策略轮换；
- 轮换后同步更新本 README、发布说明和控制台入口配置，避免旧链接长期暴露。

WiFi 入口不限定 leader。两种方式都可以落地：

- leader 开 WiFi：WebUI 能看到 leader 汇总后的全队信息。
- member 开 WiFi：WebUI 连接这个 member，能看这个 member 自身状态；如果固件把收到的配置、ACK、最近 leader 信息也缓存出来，也可以显示它看到的网络视角。

手机定位入口说明（`v4.2.2`）：

- `send location / use phone gps / start auto` 在板端 `http://192.168.43.1/pairing` 页面，不在这个 Vite 域名 WebUI 页面里。
- 域名 WebUI 的 WiFi 模式当前主要用于状态查看与控制接口调用，不提供 `POST /api/send` 和 phone GPS 采集控件。

## 当前 WS63 HTTP API

### GET /api/status

未配置时：

```json
{
  "configured": false,
  "selfLabel": "WS63-7B2C",
  "routeId": 44,
  "macReady": true,
  "macSuffix": "7B2C",
  "ssid": "SLE-7B2C",
  "transport": "ws63-softap"
}
```

已配置时：

```json
{
  "configured": true,
  "teamId": 1,
  "selfId": 1,
  "leaderId": 1,
  "macReady": true,
  "mac": "AA:BB:CC:DD:12:34",
  "macSuffix": "1234",
  "role": "leader",
  "state": "online",
  "joined": true,
  "relayAllowed": true,
  "relayEnabled": true,
  "relayTier": 0,
  "maxDownstream": 4,
  "upstreamParentId": 0,
  "upstreamParentState": "idle",
  "nextSeq": 67,
  "uptimeS": 205,
  "transport": "ws63-softap",
  "pairingEnabled": true,
  "memberFilterEnabled": false,
  "allowedMemberCount": 0,
  "allowedMembers": []
}
```

### GET /api/nodes

```json
[
  {
    "id": 2,
    "role": "member",
    "online": true,
    "batteryPercent": 88,
    "fixStatus": 1,
    "macReady": true,
    "macSuffix": "7B2C",
    "lastRssiDbm": -43,
    "relayAllowed": true,
    "relayTier": 1,
    "maxDownstream": 2,
    "parentId": 1,
    "nextHopId": 1,
    "childCount": 1,
    "lastSeq": 57,
    "lastSeenS": 205
  }
]
```

### GET /api/events

```json
[
  {
    "id": "evt-57",
    "time": "205",
    "direction": "rx",
    "type": "POS_REPORT",
    "srcId": 2,
    "dstId": 1,
    "seq": 57,
    "summary": "pos lat=39.908456 lon=116.397128 battery=88 fix=1 sat=9"
  }
]
```

`time` 是固件启动后的秒数，域名 WebUI 会显示为 `205s`。

### POST /api/send

当前 WS63 固件没有落地 HTTP `POST /api/send`；域名 WebUI 在 WiFi 模式会优先使用板端已有的 GET 控制接口，在串口模式可通过 CLI 发送测试包。`POST /api/send` 仍是后续代理/上位机接口候选。

```json
{
  "type": "position",
  "dstId": 1,
  "latitudeE6": 39908456,
  "longitudeE6": 116397128,
  "speedCms": 100,
  "headingDeg": 90,
  "batteryPercent": 88,
  "fixStatus": 1,
  "satCount": 9
}
```

后续如果上位机代理实现这个接口，建议响应返回刚产生的事件：

```json
{
  "id": "evt-tx-68",
  "time": "207",
  "direction": "tx",
  "type": "POS_REPORT",
  "srcId": 1,
  "dstId": 1,
  "seq": 68,
  "summary": "position sent to 1"
}
```

## 成员准入配置

域名 WebUI 的“成员准入”面板当前是落地功能，但写入路径限定为串口模式：

- `allow all`：leader 接收所有 member。
- `allow only 2`：leader 只接收 member 2。
- `allow add 3` / `allow del 3`：运行时增删白名单。

WiFi HTTP 当前能在 `/api/status` 里查看 `memberFilterEnabled`、`allowedMemberCount`、`allowedMembers`，成员准入写入仍走串口 CLI。角色选择、配队、member 选 leader、leave、factory reset 已同步到板端 GET 控制接口。

## 当前 WS63 HTTP 控制接口

```text
GET /api/status
GET /api/nodes
GET /api/events
GET /api/pending
GET /api/location?lat=...&lon=...&dst=255&speed=...&heading=...&battery=...&fix=...&sat=...
GET /api/config/status
GET /api/config/leader?team=1&channel=17&now=1
GET /api/config/member?leader=C7E9&team=1&channel=17&now=1
GET /api/config/apply
GET /api/config/clear
GET /api/config/reboot
GET /api/role?role=leader
GET /api/role?role=member&leader=C7E9&team=1&channel=17
GET /api/pairing?action=start|stop|approve&id=2&relay=1
GET /api/member/select?team=1&leader=C7E9&channel=17
GET /api/member/leave
GET /api/factory-reset
```

## 下一步

- 给 WS63 HTTP 增加 `POST /api/send` 和轻量配置接口。
- 把成员准入、team/channel/self/leader 配置持久化到板端存储。
- 后续用 `cipher_mac` 或 pairing key 做真实队伍认证。

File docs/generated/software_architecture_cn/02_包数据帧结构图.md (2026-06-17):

# 02 包数据帧结构图

当前系统实际传输的数据不是直接裸发业务字段，而是采用三层封装：

```text
Mesh Packet 外层
  -> GROUP_DATA wrapper
      -> App Packet 内层
          -> 业务 Body
```

当前物理传输层是 WS63 SLE。该结构可以理解为类 MeshCore/MeshLoRa 风格的数据包分层，但本工程当前不是 LoRa 空口。

## 总体数据帧结构

```mermaid
flowchart LR
    SLE["WS63 SLE Payload"] --> Mesh["Mesh Packet"]
    Mesh --> Header["Header<br/>version / payload_type / route_type"]
    Mesh --> Transport["Transport Codes<br/>可选 4 字节"]
    Mesh --> PathLen["PathLength<br/>path_hash_size / hop_count"]
    Mesh --> Path["Path<br/>当前通常为空"]
    Mesh --> Payload["Payload"]
    Payload --> Group["GROUP_DATA"]
    Group --> Channel["channel_hash"]
    Group --> Cipher["cipher_mac[2]<br/>当前预留 00 00"]
    Group --> App["App Packet"]
    App --> AppHeader["App Header"]
    App --> Body["业务 Body"]
```

## 线性字节布局

```text
+------------------+-------------------------+------------------+--------------------+
| Mesh Header      | Transport Codes 可选     | PathLength       | Path               |
| 1 byte           | 0 或 4 bytes             | 1 byte           | N bytes            |
+------------------+-------------------------+------------------+--------------------+
| GROUP_DATA.channel_hash | GROUP_DATA.cipher_mac[2] | App Header | App Body        |
| 1 byte                 | 2 bytes                  | 12 bytes   | body_len bytes  |
+-------------------------+--------------------------+------------+-----------------+
```

当前常见情况下：

- `payload_type = GROUP_DATA`
- `route_type = DIRECT` 或 `FLOOD`
- `hop_count = 0`
- `Path` 通常为空
- `cipher_mac = 00 00`

因此常见实际包可简化理解为：

```text
[MeshHeader][PathLength][channel_hash][cipher_mac0][cipher_mac1][AppHeader][Body]
```

## Mesh Header 位结构

```text
Byte0: Mesh Header

bit7 bit6 | bit5 bit4 bit3 bit2 | bit1 bit0
--------- | ------------------- | ---------
version   | payload_type        | route_type
```

字段说明：

| 字段 | 长度 | 说明 |
|---|---:|---|
| `version` | 2 bit | 当前为 `SLE_TEAM_PAYLOAD_V1` |
| `payload_type` | 4 bit | 当前主要使用 `GROUP_DATA = 0x06` |
| `route_type` | 2 bit | 区分 flood/direct/transport flood/transport direct |

## route_type 类型

| 值 | 名称 | 说明 |
|---:|---|---|
| `0x00` | `TRANSPORT_FLOOD` | 带 transport code 的泛洪 |
| `0x01` | `FLOOD` | 普通泛洪 |
| `0x02` | `DIRECT` | 直达目标或下一跳 |
| `0x03` | `TRANSPORT_DIRECT` | 带 transport code 的直达 |

## payload_type 类型

| 值 | 名称 | 说明 |
|---:|---|---|
| `0x00` | `REQ` | 请求 |
| `0x01` | `RESPONSE` | 响应 |
| `0x02` | `TEXT` | 文本 |
| `0x03` | `ACK` | 外层确认 |
| `0x04` | `ADVERT` | 广播 |
| `0x05` | `GROUP_TEXT` | 组文本 |
| `0x06` | `GROUP_DATA` | 当前业务数据主要使用 |
| `0x07` | `ANON_REQ` | 匿名请求 |
| `0x08` | `PATH` | 路径 |
| `0x09` | `TRACE` | 跟踪 |
| `0x0A` | `MULTIPART` | 分片 |
| `0x0B` | `CONTROL` | 控制 |
| `0x0F` | `RAW_CUSTOM` | 自定义 |

## GROUP_DATA wrapper

```text
+-------------+---------------+----------------+
| channel_hash| cipher_mac[2] | App Packet     |
| 1 byte      | 2 bytes       | 12 + body_len  |
+-------------+---------------+----------------+
```

字段说明：

| 字段 | 长度 | 说明 |
|---|---:|---|
| `channel_hash` | 1 byte | 队伍/频道隔离，收包时必须匹配当前配置 |
| `cipher_mac` | 2 bytes | 认证/加密预留字段，当前通常为 `00 00` |
| `App Packet` | 可变 | 组网业务消息 |

## App Packet 结构

```text
+--------------+-------+-----+---------+--------+--------+-----+-------------+----------+------+
| app_msg_type | flags | seq | team_id | src_id | dst_id | ttl | leader_term | body_len | body |
| 1 byte       |1 byte |2 LE | 1 byte  | 1 byte | 1 byte |1    | 2 LE        | 2 LE     | N    |
+--------------+-------+-----+---------+--------+--------+-----+-------------+----------+------+
```

字段说明：

| 字段 | 长度 | 说明 |
|---|---:|---|
| `app_msg_type` | 1 byte | 业务消息类型 |
| `flags` | 1 byte | 业务标志位，当前大多为 0 |
| `seq` | 2 bytes LE | 发送序号 |
| `team_id` | 1 byte | 队伍 ID |
| `src_id` | 1 byte | 源节点 route id |
| `dst_id` | 1 byte | 目标节点 route id，`0xFF` 表示广播 |
| `ttl` | 1 byte | 转发跳数限制 |
| `leader_term` | 2 bytes LE | leader 代次，避免旧 leader/旧策略污染 |
| `body_len` | 2 bytes LE | Body 长度 |
| `body` | 可变 | 业务消息体 |

## App 消息类型

| 值 | 名称 | 用途 |
|---:|---|---|
| `0x01` | `HELLO` | member 入网、重入网、身份上报 |
| `0x02` | `HEARTBEAT` | 在线心跳、电量、RSSI、定位状态 |
| `0x03` | `POS_REPORT` | 经纬度、速度、航向、卫星数 |
| `0x04` | `ALERT` | 离队、超时、距离、电量等告警 |
| `0x05` | `CONFIG` | leader 下发心跳、距离、relay 参数 |
| `0x06` | `ACK` | 确认 HELLO/CONFIG/ROUTE_UPDATE |
| `0x07` | `ROUTE_UPDATE` | leader 下发 parent/next_hop/relay 策略 |

## 业务 Body 结构

### HELLO Body

```text
+-----------+------+---------+--------+-----------+----------------+
| device_id | role | battery | mac[6] | mac_ready | fw_compat[2]   |
| 1 byte    |1 byte| 1 byte  |6 bytes | 1 byte    | low, high      |
+-----------+------+---------+--------+-----------+----------------+
```

用途：

- member 告诉 leader 自己是谁。
- 携带固件兼容指纹 `fw_compat`。
- leader 用它判断是否允许入队。

### HEARTBEAT Body

```text
+---------+----------+------------+----------+
| battery | rssi_dbm | fix_status | reserved |
| 1 byte  | 1 byte   | 1 byte     | 1 byte   |
+---------+----------+------------+----------+
```

用途：

- 周期证明节点在线。
- 更新 leader 成员表中的 `last_seen_s`、RSSI、定位状态。

### POS_REPORT Body

```text
+-------------+--------------+-----------+-------------+---------+------------+-----------+----------+
| latitude_e6 | longitude_e6 | speed_cms | heading_deg | battery | fix_status | sat_count | reserved |
| int32 LE    | int32 LE     | uint16 LE | uint16 LE   | 1 byte  | 1 byte     | 1 byte    | 1 byte   |
+-------------+--------------+-----------+-------------+---------+------------+-----------+----------+
```

用途：

- 上报 GPS 或手机位置。
- leader 更新成员位置表。

### ALERT Body

```text
+----------------+--------+----------+------------------+-------------------+---------------+
| lost_member_id | reason | reserved | last_latitude_e6 | last_longitude_e6 | last_report_s |
| 1 byte         |1 byte  | uint16   | int32 LE         | int32 LE          | uint32 LE     |
+----------------+--------+----------+------------------+-------------------+---------------+
```

用途：

- 上报离队、超时、低电量、距离告警。
- 显式 leave 时使用 `SLE_TEAM_ALERT_LEAVE`。

### CONFIG Body

```text
+-------------------+-----------------+-----------------+---------------------+
| report_interval_s | warn_distance_m | lost_distance_m | heartbeat_timeout_s |
| uint16 LE         | uint16 LE       | uint16 LE       | uint16 LE           |
+-------------------+-----------------+-----------------+---------------------+
| relay_allowed     | relay_tier      | max_downstream  | reserved            |
| 1 byte            | 1 byte          | 1 byte          | 1 byte              |
+-------------------+-----------------+-----------------+---------------------+
```

用途：

- leader 给 member 下发心跳、位置上报、距离阈值和 relay 能力。

### ACK Body

```text
+---------+----------------+-------------+
| ack_seq | acked_msg_type | status_code |
| 2 LE    | 1 byte         | 1 byte      |
+---------+----------------+-------------+
```

用途：

- member 确认收到 `ROUTE_UPDATE`、`CONFIG` 或 `HELLO` 相关策略。
- leader 用 ACK 把 `policy_pending` 清掉并确认 member online。

### ROUTE_UPDATE Body

```text
+-----------+-------------+--------------+----------+
| parent_id | next_hop_id | parent_state | reserved |
| 1 byte    | 1 byte      | 1 byte       | 1 byte   |
+-----------+-------------+--------------+----------+
```

用途：

- leader 告诉 member 当前应该挂在哪个 parent 下。
- `next_hop_id` 指明实际下一跳。
- `reserved bit0` 表示 relay 授权同步。

## 典型 HEARTBEAT 包示例

```text
Mesh Packet
  version      = 0
  payload_type = GROUP_DATA
  route_type   = DIRECT
  hop_count    = 0

GROUP_DATA
  channel_hash = 当前队伍频道
  cipher_mac   = 00 00

App Packet
  app_msg_type = HEARTBEAT
  seq          = 当前序号
  team_id      = 队伍 ID
  src_id       = member route id
  dst_id       = leader route id
  ttl          = 4
  leader_term  = 当前 leader 代次
  body_len     = 4

Body
  battery_percent
  rssi_dbm
  fix_status
  reserved
```

## 设计意义

该数据帧结构把传输层和业务层分开：

- Mesh Packet 负责外层路由类型和路径扩展。
- GROUP_DATA 负责频道隔离和后续安全字段预留。
- App Packet 负责组网业务语义。
- Body 只关心具体业务内容。

因此后续如果从 WS63 SLE 迁移到 LoRa，只需要替换底层收发驱动，上层 App Packet 和大部分组网状态机可以复用。

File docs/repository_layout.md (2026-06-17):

# Repository Layout

本仓库按“固件、脚本、自动化、硬件、版本记录”分区。

| 路径 | 用途 |
| --- | --- |
| `firmware/` | 固件工程索引和版本边界说明。实际 SDK 工程仍在 `xc/` 下。 |
| `xc/ws63_team_network/` | 当前 WS63 SLE team network 板端固件。 |
| `include/`, `src/` | 可在本地测试和固件中复用的协议/状态机代码。 |
| `examples/` | C 侧回归和演示程序。 |
| `scripts/build/` | 构建脚本。 |
| `scripts/flash/` | 烧录脚本。 |
| `scripts/serial/` | 串口配置脚本。 |
| `scripts/sim/` | 仿真脚本。 |
| `scripts/test/` | 测试总入口。 |
| `automation/ws63/` | WS63 自动化工具、测试和系统编排。 |
| `webui/` | 浏览器 WebUI。 |
| `hardware/` | PCB、原理图、3D 打印外壳等硬件资料。 |
| `versions/` | 仓库/固件/硬件发布记录和验证记录。 |
| `docs/` | 阶段文档和维护说明。 |
| `meta/` | 项目操作 SOP 和维护规则。生成型审查输出不提交。 |

## 本地草稿

`.planning/`、`models/`、`3D/`、`_schem_review/`、`v3.pdf`、`vm-preseed/`、`meta/review_feedback.md` 等本地草稿或生成输出已加入 `.gitignore`。确认要公开的硬件资料应整理进 `hardware/` 后再提交。

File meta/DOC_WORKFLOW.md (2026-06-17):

# Documentation Workflow

这份文件定义文档维护规则：写在哪里、什么时候更新、如何避免仓库再次变乱。

## 分层

- 根目录 [../README.md](../README.md)：项目入口、目录结构、构建、烧录、测试和硬件入口。
- [../docs/README.md](../docs/README.md)：文档索引。
- [PROJECT_OPERATION_SOP.md](PROJECT_OPERATION_SOP.md)：项目操作 SOP。
- [../versions/README.md](../versions/README.md)：版本记录索引。
- [../hardware/README.md](../hardware/README.md)：硬件资料入口。

## 写作规则

- 新功能优先更新已有文档，不为同一主题新建重复 README。
- 仓库结构变化先更新 `README.md`、`docs/repository_layout.md` 和 `docs/version_management.md`。
- 固件行为变化必须更新对应 `versions/<version>/VERSION.md` 和 `MANIFEST.md`。
- 硬件资料确认可发布后放入 `hardware/<category>/<name>/<version>/`，不要直接堆在仓库根目录。
- 临时计划、审查截图、模型草稿和本地日志不提交到 GitHub。

## 审查脚本

审查辅助入口：

```sh
scripts/review/run_review_with_service.sh --dry-run
```

审查输出固定写入本地 `meta/review_feedback.md`，该文件已加入 `.gitignore`，不提交到 GitHub。

## 修改后检查

```sh
git diff --check
npm --prefix webui test
python -m unittest discover -s automation/ws63/tests -t .
```

按变更范围选择必要检查；硬件资料变化至少检查 MANIFEST、README 和文件路径是否一致。

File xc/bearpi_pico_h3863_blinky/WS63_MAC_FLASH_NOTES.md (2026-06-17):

# WS63 Mac 编译烧录踩坑记录

本文记录一次在 Apple Silicon Mac 上，把小熊派 `BearPi-Pico H3863 / WS63` 的 LiteOS blinky 固件编译、烧录并点灯成功的过程。

这不是官方最短流程，而是实测可跑通流程，重点记录踩坑点。

## 本次结果

- 主机：Mac，Apple Silicon
- 板子：小熊派 `BearPi-Pico H3863 / WS63`
- 系统：LiteOS
- 示例：`peripheral/blinky`
- 点灯引脚：`GPIO_2`
- 翻转周期：`500 ms`
- 编译目标：`ws63-liteos-app`
- 烧录包：`ws63-liteos-app_all.fwpkg`
- 烧录串口：`/dev/tty.usbserial-10`
- 烧录波特率：`115200`

最终现象：

- 烧录工具输出 `Done. Reseting device...`
- 串口能看到 `APP|[SYS INFO] ...`
- 板载 LED 按约 `500 ms` 周期闪烁

## 整体流程

```text
Mac
  |
  | QEMU 启动 x86_64 Debian VM
  v
Debian VM 编译 WS63 SDK
  |
  | 生成 .fwpkg
  v
Mac 拷回固件包
  |
  | /dev/tty.usbserial-10 串口烧录
  v
WS63 LiteOS blinky 运行
```
## 为什么要用 x86_64 Debian VM

WS63 SDK 里的工具链和构建脚本更适合 Linux x86_64 环境。

Mac 直接编译容易遇到：

- 工具链架构不匹配
- Python 版本兼容问题
- 旧 `output` 缓存路径污染
- HiSpark 插件在 Mac 上不可用或不完整

所以本次采用：

- Mac 负责 QEMU、串口、烧录
- Debian x86_64 VM 负责编译

## VM 连接信息

本次 VM 通过 QEMU user network 暴露 SSH：

```sh
ssh -p 2222 builder@127.0.0.1
```

VM 用户：

```text
user: builder
password: builder
```

## VM 安装依赖

在 Debian VM 内安装：

```sh
sudo apt update
sudo apt install -y rsync file build-essential cmake ninja-build python3-pip python3-venv git make
```

安装 SDK Python 依赖：

```sh
python3 -m pip install --user -r requirements.txt
```

如果提示用户脚本目录不在 `PATH`，加上：

```sh
export PATH="$HOME/.local/bin:$PATH"
```

## Python 3.13 的 distutils 坑

如果 Debian/Python 版本较新，`build.py` 里可能有：

```python
from distutils.spawn import find_executable
```

Python 3.12+ 后 `distutils` 被移除，构建会失败。

本次修法：

```python
from shutil import which
```

并把：

```python
find_executable(...)
```

替换为：

```python
which(...)
```

## output 缓存路径污染坑

第一次把 Mac 上的 SDK 整目录同步到 VM 后，原有 `output/` 里残留了 Mac 路径，例如：

```text
<sdk-root>/output/...
```

VM 构建时会报类似 CMakeCache 路径不一致的问题。

正确做法是同步源码时排除仓库根目录的 `output`：

```sh
rsync -a --exclude=/output \
  /home/builder/workspace/bearpi-pico_h3863/ \
  /home/builder/workspace/bearpi-pico_h3863_fresh/
```

注意只排除根目录 `output`，不要排除所有叫 `output` 的目录。

错误做法：

```sh
rsync -a --exclude=output ...
```

这个会把 SDK 内部必要文件也排掉，例如：

```text
drivers/chips/ws63/rom_config/acore/output/rom_callback_wrap.cmake
```

结果 LiteOS app 配置阶段会失败。

## 编译命令

在 VM 的干净 SDK 目录中执行：

```sh
export PATH="$HOME/.local/bin:$PATH"
cd /home/builder/workspace/bearpi-pico_h3863_fresh
python3 build.py ws63-liteos-app -j4
```

成功标志：

```text
######### Build target:ws63_liteos_app success
packet success!
```

本次编译耗时约 20 分钟。

## 生成的关键文件

完整烧录包：

```text
/home/builder/workspace/bearpi-pico_h3863_fresh/output/ws63/fwpkg/ws63-liteos-app/ws63-liteos-app_all.fwpkg
```

只更新应用的包：

```text
/home/builder/workspace/bearpi-pico_h3863_fresh/output/ws63/fwpkg/ws63-liteos-app/ws63-liteos-app_load_only.fwpkg
```

第一次上板建议使用完整包 `ws63-liteos-app_all.fwpkg`，避免 bootloader、分区、NV 状态不一致。

## 拷回 Mac

```sh
mkdir -p <sdk-root>/output_from_vm

scp -P 2222 \
  builder@127.0.0.1:/home/builder/workspace/bearpi-pico_h3863_fresh/output/ws63/fwpkg/ws63-liteos-app/ws63-liteos-app_all.fwpkg \
  <sdk-root>/output_from_vm/
```

## Mac 串口识别

查看串口：

```sh
find /dev -maxdepth 1 \( -name 'cu.*' -o -name 'tty.*' \) 2>/dev/null | sort
```

本次识别到：

```text
/dev/cu.usbserial-10
/dev/tty.usbserial-10
```

USB 信息显示是 CH340/CH341 类串口：

```text
Vendor ID: 0x1a86
Product ID: 0x7523
```

## 安装烧录工具

本次使用社区 Python 工具 `xf-burn-tools`：

```sh
python3 -m pip install --user xf-burn-tools rich
```

工具命令路径：

```text
<python-user-bin>/burn
```

查看帮助：

```sh
<python-user-bin>/burn --help
```

查看固件包内容：

```sh
<python-user-bin>/burn -s \
  <sdk-root>/output_from_vm/ws63-liteos-app_all.fwpkg
```

## 烧录命令

`sle_mesh` 工程当前推荐走项目脚本，它会先尝试自动复位：

```sh
printf 'flash leader\n' | \
  <repo-root>/scripts/flash/ws63_flash_team.sh \
  leader /dev/tty.usbserial-10
```

自动复位机制：

- 新版 `xc/ws63_team_network` 固件支持串口 CLI `reboot/reset`，烧录脚本会先发 `reboot`。
- 脚本也会尝试 DTR/RTS 脉冲；是否有效取决于当前 USB 转串口/烧录器是否把控制线接到板子的复位控制脚。
- 第一次从老固件升级时，老固件没有 `reboot` 命令，仍可能需要手按一次 `RESET/RST`。小熊派 WS63 没有 BOOT 键时按 RESET 即可；带 BOOT 下载键的板子才需要按住 BOOT 再点 RESET。
- 关闭自动复位可用：`AUTO_RESET=0 scripts/flash/ws63_flash_team.sh leader /dev/tty.usbserial-10`。

底层 `xf-burn-tools` 命令仍是：

最终成功命令：

```sh
<python-user-bin>/burn \
  -p /dev/tty.usbserial-10 \
  -b 115200 \
  <sdk-root>/output_from_vm/ws63-liteos-app_all.fwpkg
```

烧录过程中如果工具停在：

```text
Waiting for device reset...
```

需要按一下板子的 `RESET/RST`。

如果板子有 `BOOT` 下载键，操作方式通常是：

```text
按住 BOOT -> 点一下 RESET -> 松开 BOOT
```

本次实际操作中，按复位后工具进入：

```text
Establishing ymodem session...
Transferring root_loaderboot_sign.bin...
```

## /dev/cu 和 /dev/tty 的坑

Mac 下同一个 USB 串口会有两个设备：

```text
/dev/cu.usbserial-10
/dev/tty.usbserial-10
```

本次实测：

- `/dev/cu.usbserial-10`：能打开，但烧录等待复位超时
- `/dev/tty.usbserial-10`：可以成功握手并烧录

所以 WS63 烧录时优先用：

```text
/dev/tty.usbserial-10
```

## 921600 波特率的坑

SDK 配置里默认 upload 波特率是 `921600`：

```json
"baud": "921600"
```

本次实测在 Mac + CH340 串口链路上：

- `921600` 能握手
- 但 YModem 传 `root_loaderboot_sign.bin` 会失败

失败现象：

```text
Establishing ymodem session...
Transferring root_loaderboot_sign.bin...
ERROR Error transferring root_loaderboot_sign.bin
```

改为 `115200` 后成功烧录完整包。

结论：

- 稳定优先：用 `115200`
- 速度优先：可以再试 `460800` 或 `921600`
- 第一次上板点灯：不要和高速串口较劲

## 等待复位超时的坑

`xf-burn-tools` 默认等待复位时间较短。

如果你来不及按复位，可以临时把安装包里的：

```text
<python-site-packages>/xf_burn_tools/ws63flash.py
```

从：

```python
RESET_TIMEOUT = 10
```

改成：

```python
RESET_TIMEOUT = 60
```

这只是本机工具修改，不是项目源码修改。

## 烧录成功标志

烧录工具末尾输出：

```text
Done. Reseting device...
```

串口读取能看到：

```text
APP|[SYS INFO] mem: used:..., free:...
```

读取串口示例：

```sh
python3 - <<'PY'
import serial, time
p = '/dev/tty.usbserial-10'
ser = serial.Serial(p, 115200, timeout=0.2)
ser.reset_input_buffer()
t = time.time()
while time.time() - t < 12:
    data = ser.read(512)
    if data:
        print(data.decode('utf-8', 'replace'), end='')
ser.close()
PY
```

## 点灯配置确认

本次编译的 blinky 配置来自：

```text
build/config/target_config/ws63/menuconfig/acore/ws63_liteos_app.config
```

关键配置：

```text
CONFIG_SAMPLE_ENABLE=y
CONFIG_ENABLE_PERIPHERAL_SAMPLE=y
CONFIG_SAMPLE_SUPPORT_BLINKY=y
CONFIG_BLINKY_PIN=2
CONFIG_BLINKY_DURATION_MS=500
```

代码逻辑：

```c
uapi_pin_set_mode(CONFIG_BLINKY_PIN, PIN_MODE_0);
uapi_gpio_set_dir(CONFIG_BLINKY_PIN, GPIO_DIRECTION_OUTPUT);
uapi_gpio_set_val(CONFIG_BLINKY_PIN, GPIO_LEVEL_LOW);

while (1) {
    osal_msleep(CONFIG_BLINKY_DURATION_MS);
    uapi_gpio_toggle(CONFIG_BLINKY_PIN);
}
```

板级头文件里：

```c
#define BSP_LED_1  GPIO_02
```

所以当前点的是 `GPIO_2 / BSP_LED_1`。

## 常见问题速查

### 编译报 CMakeCache 路径不一致

原因：从 Mac 同步过去的根目录 `output/` 带了旧绝对路径。

解决：重新同步，排除根目录 `output`。

```sh
rsync -a --exclude=/output source/ fresh/
```

### 报 `distutils` 不存在

原因：Python 3.12+ 移除了 `distutils`。

解决：把 `find_executable` 改为 `shutil.which`。

### 找不到 `rom_callback_wrap.cmake`

原因：错误使用 `--exclude=output`，把 SDK 内部必要 output 目录也排除了。

解决：只排除根目录 output。

```sh
--exclude=/output
```

### `/dev/cu.usbserial-10` 烧录超时

解决：换 `/dev/tty.usbserial-10`。

### 921600 传输失败

解决：换 `115200`。

### 工具一直等待 reset

优先解决：升级到支持串口 CLI `reboot/reset` 的 `xc/ws63_team_network` 固件，然后用 `scripts/flash/ws63_flash_team.sh` 默认自动复位烧录。

如果是第一次从老固件升级，或当前烧录器没有接复位控制线，按板子复位；如果有 BOOT 键，按住 BOOT 再点 RESET。

### 烧录成功但灯不闪

检查：

- 当前是否真的编译了 `CONFIG_SAMPLE_SUPPORT_BLINKY=y`
- LED 是否接在 `GPIO_2`
- LED 是否低电平点亮
- 是否烧了完整包 `ws63-liteos-app_all.fwpkg`

## 本次推荐固定命令

编译：

```sh
cd /home/builder/workspace/bearpi-pico_h3863_fresh
export PATH="$HOME/.local/bin:$PATH"
python3 build.py ws63-liteos-app -j4
```

烧录：

```sh
<python-user-bin>/burn \
  -p /dev/tty.usbserial-10 \
  -b 115200 \
  <sdk-root>/output_from_vm/ws63-liteos-app_all.fwpkg
```

串口查看：

```sh
python3 - <<'PY'
import serial, time
p = '/dev/tty.usbserial-10'
ser = serial.Serial(p, 115200, timeout=0.2)
t = time.time()
while time.time() - t < 12:
    data = ser.read(512)
    if data:
        print(data.decode('utf-8', 'replace'), end='')
ser.close()
PY
```

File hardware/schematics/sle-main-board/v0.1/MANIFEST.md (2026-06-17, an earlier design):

# Manifest: SLE Main Board Schematic v0.1

## Files

- `README.md`
- `MANIFEST.md`
- `SCH_Schematic1_2026-05-19.pdf`

## Notes

- Moved from `docs/v4/reference/` during the v4.4.97 repository cleanup.
- Used as hardware reference for WS63, ST7789, WS2812, GPS and UART pin mapping.

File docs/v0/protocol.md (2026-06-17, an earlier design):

# V0 协议说明（1vs2 / 1vs8）

## 分层结构

```text
Mesh Packet
  -> GROUP_DATA Payload
    -> App Packet
      -> App Body
```

## App 消息类型

- `HELLO`
- `HEARTBEAT`
- `POS_REPORT`
- `ALERT`
- `CONFIG`
- `ACK`

## 行为口径

- V0 以单跳稳定为优先，不做自动 relay 选举。
- `cipher_mac` 为预留字段，当前应用层仍为明文。
- 入网以 `HELLO -> ACK -> CONFIG` 为主流程。

## CLI

常用命令：`hello`、`hb`、`pos`、`alert`、`config`、`ack`、`members`、`state`。

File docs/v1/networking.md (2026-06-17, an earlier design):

# V1 组网流程（手动 relay）

## 目标

在 1vs8 单跳物理限制下，先实现可控的一对多逻辑组网，并引入 relay 但保持人工可控。

## 角色职责

- leader：配对窗口控制、成员 approve、relay 权限授予。
- relay member：被授权后可连接下游 leaf 并转发。
- leaf member：普通业务节点，不承担中继。

## 操作流程

1. leader 打开 pairing window。
2. member 发 `HELLO` 进入 pending。
3. leader 在 `/pairing` 手动 approve。
4. leader 可对指定 member 显式设 `relay=1`。
5. relay 主动吸纳 leaf，形成分层链路。

## 路由规则

- 发包优先走 `next_hop` 定向转发。
- next-hop 不可达时直接 `NO_ROUTE`，避免不受控泛洪。

## 与 V2 的区别

- V1：relay 授权与拓扑形成是人工主导。
- V2：relay 选举、选父、掉线自愈转向自动策略。

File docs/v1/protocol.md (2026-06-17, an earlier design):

# V1 协议说明（手动 relay）

## 与 V0 的差异

- 增加 relay 相关能力，但授权仍由 leader 手动控制。
- 路由由 `member_id -> next_hop` 记录驱动定向转发。

## 主要消息

- 保留 V0 的 `HELLO/HEARTBEAT/POS_REPORT/ALERT/CONFIG/ACK`
- 增加 `ROUTE_UPDATE`（用于上报父节点与路径变化）

## 路由策略

- 有 next-hop 时只走 next-hop。
- next-hop 不可达时直接 `NO_ROUTE`，避免 fallback 泛洪。

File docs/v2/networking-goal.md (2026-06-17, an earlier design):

/goal
V2组网目标：从“V1手动relay授权 + relay主动找leaf”升级为“自动relay选举 + member自动选父 + relay失效自愈”的1vs20逻辑组网。

一、核心约束
1. 物理连接上限仍是单跳8（SDK限制），但逻辑成员目标20。
2. leader仍是唯一准入控制者（approve authority不变）。
3. 不合并到主分支，在v2分支独立迭代。

二、问题1目标（pairing window看到全部member）
1. 目标：leader在pairing window中展示尽可能完整的member列表（>=20逻辑容量），而不是只看到8个直连。
2. 结论：仅靠leader直连不可能长期同时>8；要看到更多成员必须“时间复用连接”或“经中继转发HELLO”。
3. V2方案：
- 方案A（优先）：pairing window期间启用“发现模式轮询连接”（leader循环连接候选、拉取HELLO、写入pending缓存后释放连接槽）。
- 方案B（增强）：引入“临时隐藏relay（仅转发HELLO/ROUTE_UPDATE，不转发业务）”以覆盖leader直连不到的节点。
- pending成员表与UI展示按逻辑成员容量20设计，带last_seen和来源路径。

三、问题2目标（自动relay授权与member选relay）
1. 目标：不再手动relay授权；pairing window关闭后自动产生relay集合。
2. 自动relay选举（leader侧）：
- 输入：RSSI到leader、在线稳定时长、电量、历史掉线率、当前负载。
- 输出：relay_allowed集合（限制数量与层级），下发CONFIG。
3. member自动选父（不是手工选）：
- 候选：leader或approved relay。
- 评分：RSSI、relay负载、链路稳定度、hop成本。
- 切换策略：滞回阈值 + 冷却时间，避免频繁抖动。

四、问题3目标（relay掉线自愈）
1. 触发：parent断连或heartbeat timeout。
2. 行为：member进入reselecting，重新扫描候选父节点并上报ROUTE_UPDATE。
3. leader行为：对已approved成员fast rejoin（不要求人工再approve），更新member_id->next_hop路由。
4. 组内若relay不足：自动重新选举新relay并下发授权。

五、验收标准
1. pairing window内可看到20个逻辑member（直连+轮询+临时中继路径）。
2. 关闭pairing window后自动形成relay拓扑，无需手动点relay=1。
3. 任一relay掉线后，组内leaf可在超时窗口内自动恢复上报（无人工干预）。
4. 业务路由保持next-hop定向转发，不回退为不受控泛洪。

---

当前进度（V2 Phase-1，已实现）
1. 已实现 pairing window 分时轮询连接：
- leader 在 pairing window 期间按周期轮换断开“未进入 pending/online 的连接”，释放连接槽继续扫描新候选。
- 目标是突破“同时8直连”限制，逐批发现更多 member 并写入 pending。
2. 已实现 pairing stop 自动审批：
- 关闭 pairing window 时，leader 自动审批当前 pending 列表。
- 自动 relay 授权采用首批配额策略（当前默认最多3个 relay）。
3. 已补齐 client 连接管理接口：
- 读取 active conn 列表；
- 查询 conn 绑定 member；
- 按 conn 主动断开。

---

下一版本目标（v2.0.0-alpha4）

目标定位：
- 在 alpha3 的基础上，补齐 V2 验收剩余缺口：leader 侧 relay 自动重选与授权下发。

一、要实现的能力
1. leader 侧 relay 池管理：
- leader 维护“当前 relay 集合 + 候选集合 + 最低保底数量”。
- 当 relay 数量低于阈值时，自动从在线 approved member 中补选新 relay。

2. relay 自动授权与回收：
- 对新选中的 relay 自动下发 `relay_allowed=1`（CONFIG）。
- 对长期不稳定或离线 relay 执行回收，必要时降级为普通 member。

3. relay 失效后的路由自愈闭环：
- parent 断连/超时后，leaf 自动重选父并上报 `ROUTE_UPDATE`。
- leader 收到后更新 `member_id -> next_hop`，并触发拓扑收敛检查。

4. 已审批成员 fast rejoin：
- 对已 approved member 保持免人工再次 approve；
- 重连后直接恢复组网角色与路由状态。

二、策略约束（避免抖动）
1. 选举冷却：
- relay 角色切换需要冷却窗口，避免频繁升降级。
2. 最小驻留：
- 新 relay 在最小驻留时间内不主动回收，除非硬故障。
3. 滞回阈值：
- 选举评分切换使用滞回阈值，避免边界抖动反复切换。

三、验收标准（alpha4）
1. 当任一 relay 掉线后，leader 能在窗口期内自动补齐 relay 配额（无需人工点击）。
2. 受影响 leaf 能自动重选父并恢复上报，leader 路由表收敛到新 next-hop。
3. 全流程保持“leader 唯一准入控制者”不变，且不回退为泛洪转发。
4. WebUI/日志可观察到 relay 选举、授权下发、路由收敛关键事件。

当前进度（V2 Phase-3，alpha4 进行中）
1. 已实现 leader 周期性 relay rebalance（关闭 pairing 后生效）：
- 按在线成员数计算 relay target（0/2/3 档）；
- relay 不足时自动从在线 approved 成员中按 RSSI 提升 relay，并下发 CONFIG。

2. 已实现 relay 回收与路由清理：
- offline relay 自动撤销 relay 权限；
- stale relay（超时窗口）自动下发 relay=0；
- 回收时清理依赖该 next-hop 的路由缓存，促使后续收敛。

3. 可观测性已补齐：
- 状态页新增 `Relay Target` / `Relay Online`；
- 日志新增 `relay set` / `relay rebalance` / `relay revoke` 事件。

4. 仍待补齐（下一步）：
- leader 触发后的补选闭环在复杂多跳实机场景继续校验。

---

下一版本目标（v2.0.0-alpha5）

目标定位：
- 在 alpha4 功能闭环基础上，增强 leader 侧“路由收敛可观测性”，让调试与实机定位有量化指标。

一、要实现的能力
1. 路由收敛指标：
- 统计 active/direct/relayed/unreachable/stale；
- 提供 converged 布尔态、epoch 版本、last_change/last_converged 时间戳。

2. 输出与提示：
- `GET /api/status` 暴露 `routeMetrics`；
- status 页面展示关键收敛字段；
- 指标变化写 system event，便于回放拓扑变化。

二、验收标准（alpha5）
1. status JSON 可稳定返回 `routeMetrics` 且字段完整。
2. 路由波动（不可达、陈旧、收敛恢复）可在 events 页面看到对应 system event。
3. 不改协议包结构，不影响现有 member/relay/leader 互通。

当前进度（V2 Phase-4，alpha5 收敛）
1. 已补齐 routeMetrics 字段闭环：
- `GET /api/status` 返回 `active/direct/relayed/unreachable/stale/converged/relayTarget/relayOnline/epoch/lastChangeS/lastConvergedS`。
2. status 页面已补齐路由收敛关键字段展示：
- 新增 `Route Direct`、`Route Last Change`、`Route Last Converged`；
- 与既有 `Route Converged/Active/Relayed/Unreachable/Stale/Epoch` 形成完整观测面。
3. events 页面可直接观察收敛变化：
- system event 展示方向与收敛 summary，便于回放拓扑变化；
- `last_converged` 仅在“未收敛 -> 收敛”转变时更新，避免被周期刷新覆盖。
4. 本地回归验证通过：
- `SLE_TEAM_NETWORK_TEST` / `SLE_TEAM_PACKET_TEST` 均通过。

当前进度（V2 Phase-5，alpha6 稳定性增强）
1. 已补齐时间窗口回绕安全：
- route metrics、parent switch cooldown、leader rescan、pairing rotate、relay rebalance 等周期比较统一改为回绕安全比较；
- route stale 与 relay stale/timeout 判定统一使用回绕安全路径。
2. 已提升地址派生 route id 稳定性：
- 对缺少显式 route 字节的旧广告，route id fallback 从单字节推导升级为全地址混合推导；
- 降低不同设备 route id 冲突概率，减小临时路由误识别风险。
3. 已完成验证与版本归档：
- `SLE_TEAM_NETWORK_TEST` / `SLE_TEAM_PACKET_TEST` 通过；
- 已新增 `versions/v2.0.0-alpha6` 版本记录。

当前进度（V2 Phase-6，alpha7 收敛提示闭环）
1. 已实现 leader 主动 ROUTE_UPDATE 收敛提示：
- routeMetrics 发生变化时，leader 按在线成员当前路由状态推导建议 parent 并主动下发 ROUTE_UPDATE；
- direct member 提示 parent=leader；已存在 next-hop 路由的 member 提示 parent=next_hop。
2. 可观测性已补齐：
- 新增 system event：`route hint sent=<n> fail=<n> st=<n> un=<n>`；
- 日志可观察到 route hint 聚合结果与失败项。
3. 已完成验证与版本归档：
- `SLE_TEAM_NETWORK_TEST` / `SLE_TEAM_PACKET_TEST` 通过；
- 已新增 `versions/v2.0.0-alpha7` 版本记录。

当前进度（V2 Phase-7，alpha8 提示降噪）
1. 已补齐 leader 主动 ROUTE_UPDATE 的 per-member 冷却：
- 对“同成员 + 同 parent”提示增加冷却窗口，避免 flapping 时每个 metrics 周期重复下发；
- parent 变化时可立即发送，不阻断收敛切换。
2. 可读性与行为一致性优化：
- `hint_parent_id` 下沉为循环内局部变量；
- 成功/失败路径均更新 hint 缓存时间，减少失败重试刷屏。
3. 已完成验证与版本归档：
- `SLE_TEAM_NETWORK_TEST` / `SLE_TEAM_PACKET_TEST` 通过；
- 已新增 `versions/v2.0.0-alpha8` 版本记录。

当前进度（V2 Phase-8，alpha9 指标细化）
1. 已补齐 leader 主动 ROUTE_UPDATE 的细粒度指标：
- 新增累计指标：`routeHintSentTotal`、`routeHintFailedTotal`、`routeHintCooldownSkippedTotal`；
- 新增最近活动时间：`routeHintLastActivityS`。
2. status 可观测性增强：
- `GET /api/status` 的 `routeMetrics` 已输出上述字段；
- 状态页新增 Route Hint 四项指标展示（Last Activity=0 显示 N/A）。
3. 已完成测试与版本归档：
- `examples/team_network_demo.c` 新增 JSON 字段断言；
- `SLE_TEAM_NETWORK_TEST` / `SLE_TEAM_PACKET_TEST` 通过；
- 已新增 `versions/v2.0.0-alpha9` 版本记录。

当前进度（V2 Phase-9，alpha10 多跳自愈观测增强）
1. 已补齐 leader 对 `ROUTE_UPDATE` 的累计观测：
- 新增累计指标：`routeUpdateRxTotal`（收到的 ROUTE_UPDATE 总数）；
- 新增重挂载指标：`routeReparentTotal`（next-hop 发生切换次数）；
- 新增最近重挂载时间：`routeReparentLastS`。
2. status 可观测性继续增强：
- `GET /api/status` 的 `routeMetrics` 新增上述 3 个字段；
- 状态页新增 `Route Update RX Total`、`Route Reparent Total`、`Route Reparent Last`（0 显示 N/A）。
3. 已完成测试与版本归档：
- `examples/team_network_demo.c` 新增 JSON 字段断言覆盖；
- `SLE_TEAM_NETWORK_TEST` / `SLE_TEAM_PACKET_TEST` 通过；
- 已新增 `versions/v2.0.0-alpha10` 版本记录。

当前进度（V2 Phase-10，alpha11 隐藏 relay 闭环）
1. 已落地 pairing window 的“临时隐藏 relay”模式：
- 复用 `CONFIG.reserved` 标志位下发隐藏 relay 意图（`SLE_TEAM_CONFIG_FLAG_RELAY_DISCOVERY_ONLY`）；
- member 侧新增 `relay_discovery_only` 状态并解析 CONFIG 标志；
- 当 `relay_discovery_only=1` 时，relay 仅转发 `HELLO/ROUTE_UPDATE`，不转发业务包。
2. 窗口切换自动收敛已补齐：
- leader 在 `pairing start/stop` 时主动刷新在线 relay 的 CONFIG；
- pairing 打开后进入“隐藏 relay”；pairing 关闭后自动恢复常规业务转发。
3. 测试与版本归档：
- `examples/team_network_demo.c` 新增隐藏 relay 行为断言（窗口开关标志、消息白名单转发）；
- `SLE_TEAM_NETWORK_TEST` / `SLE_TEAM_PACKET_TEST` 通过；
- 已新增 `versions/v2.0.0-alpha11` 版本记录。
4. 验收口径状态（截至 alpha11）：
- 问题1中的方案B（临时隐藏 relay）已具备实现闭环；
- V2 四条总体验收标准在能力侧均已覆盖，后续重点转向复杂多跳实机压测与参数调优。

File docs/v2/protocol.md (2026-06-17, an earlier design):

# V2 协议说明（自动组网）

## 目标

在单跳 8 连接限制下，通过 relay 与路由策略实现 1vs20 逻辑成员组网。

## 分层结构

```text
Mesh Packet
  -> GROUP_DATA Payload
    -> App Packet
      -> App Body
```

## 关键消息

- `HELLO`：入网发现
- `CONFIG`：leader 下发能力/参数（含 relay 许可）
- `ACK`：关键消息确认
- `ROUTE_UPDATE`：父节点与路径更新
- `HEARTBEAT/POS_REPORT/ALERT`：业务与健康状态

## V2 路由口径

- leader 维护 `member_id -> next_hop`。
- 发包前验证 next-hop 可达性。
- 不可达时返回 `NO_ROUTE`，不做无控制泛洪。

## 安全口径

- 当前应用层仍无端到端加密；`cipher_mac` 是预留字段。
- 链路加密能力取决于 SLE 底层配对与安全配置。

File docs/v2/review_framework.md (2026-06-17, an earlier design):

# Code Review Framework — Automated Review Instructions

> ⚠️ 本文档是给 自动化审查服务执行用的操作手册，不是给开发者看的。
>
> **每次执行代码审查前**，先读本文档，严格按各 Stage 执行。
> **审查完成后**，将结果写入本地 `meta/review_feedback.md`。该文件是生成输出，不提交到 GitHub。

---

## 0. 必需头信息

每次审查报告必须以如下格式开头：

```markdown
# Code Review Feedback

**Reviewer:** Review Service (configured-provider)
**Date:** YYYY-MM-DD
**Version:** vX.Y.Z（从 versions/README.md 读取最新版本号）
**Branch:** <branch-name>
**Scope:** <本次审查的范围，如：新代码逻辑 / V2 Phase-2 / PR #xxx>
```

版本号读取规则：

1. 打开 `versions/README.md`，找到顶部 `当前版本：` 下列出的最新版本（列表第一项）。
2. 如果同时存在多个版本线（如 v1.2.x 和 v2.0.x），以最高主版本号为准。
3. 将版本号填入 `Version:` 字段。

---

## 1. 审查流程

### Stage 1 — README 声明验证

目的：确保 `README.md` 描述的功能与代码一致，避免文档落后于实现。

步骤：

1. 读取 `README.md`，提取所有功能声明（bullet points、列举的特性）。
2. 逐条与源码对照验证：
   - 检查对应的宏/函数/状态机是否存在。
   - 检查行为是否符合描述（如 "next-hop 不可达时报 NO_ROUTE"）。
3. 输出格式：

```markdown
### README 声明验证

| # | README 声明 | 源码验证 | 状态 |
|---|------------|----------|------|
| 1 | 描述的功能 | 对应代码位置/逻辑 | ✅ 一致 / ❌ 不一致 / ⚠️ 部分一致 |
```

### Stage 2 — 历史反馈追踪

目的：跟踪之前审查中提出的问题是否已修复，避免重复报告。

步骤：

1. 如本地存在 `meta/review_feedback.md`，读取其中的 **汇总** 或 **历史反馈追踪** 章节；不存在时跳过历史反馈追踪。
2. 逐条验证：
   - 标记为 "Resolved" 的：确认代码是否仍保持修复状态。
   - 标记为 "Open / Warning" 的：重新验证是否已修复。
3. 输出格式：

```markdown
### 历史反馈追踪

| # | 之前的问题 | 状态 | 当前证据 |
|---|-----------|------|----------|
| 1 | 问题描述 | ✅ Resolved / ❌ Still Open | 代码位置或说明 |
```

### Stage 3 — 新代码逻辑审查

目的：深入审查新增/变更代码的逻辑正确性。

审查清单（逐条检查）：

- [ ] **状态机完备性**：枚举值是否覆盖所有状态；状态转换是否有遗漏分支。
- [ ] **竞态条件**：全局变量在多处写入时是否有锁保护或原子操作；中断/回调中修改的数据是否被主循环重复入。
- [ ] **缓冲区安全**：`memcpy_s` / `memset_s` / `snprintf_s` 的长度参数是否正确；是否存在栈上大缓冲区。
- [ ] **空指针与边界**：函数入口是否检查指针参数；数组访问是否检查下标范围。
- [ ] **资源泄漏**：连接断开时是否清理对应的内存/定时器/状态。
- [ ] **整数与类型**：`uint8_t` 溢出场景（循环计数、ID 分配）；有符号/无符号比较混用。
- [ ] **魔法数字**：硬编码数值是否应提取为宏。
- [ ] **协议兼容性**：新增字段是否考虑旧版本解析；包长度是否匹配。

对发现的每个问题，输出格式：

```markdown
- **类型**: Blocker / Warning / Note
- **文件**: `path/file.c:line`
- **问题**: 描述
- **建议**: 修复方案
```

### Stage 4 — 特性验证（如有目标文档）

目的：当审查针对某个版本目标（如 `docs/v2/networking-goal.md`）时，验证实现是否满足文档要求。

步骤：

1. 读取目标文档（如 `docs/v2/networking-goal.md`）。
2. 提取验收标准（通常位于 `验收标准` 或 `目标` 章节）。
3. 逐条对照代码实现。
4. 输出格式：

```markdown
### 特性验证：<文档名>

| # | 验收标准 | 实现位置 | 状态 |
|---|---------|----------|------|
| 1 | 标准描述 | 代码位置/逻辑说明 | ✅ 已实现 / ❌ 未实现 / ⚠️ 部分实现 |
```

### Stage 5 — 汇总

输出本次审查的总结：

```markdown
### 汇总

- **Blocker**: N 个（必须修复）
- **Warning**: N 个（建议修复）
- **Note**: N 个（观察项）
- **Info**: N 个（一般说明）
- **README 声明验证**: N/N 通过
- **特性验证**: N/N 通过

**结论**: ✅ 通过 / ⚠️ 有条件通过 / ❌ 拒绝
```

---

## 2. 反馈分类定义

| 分类 | 含义 | 处理要求 |
|---|---|---|
| **Blocker** | 逻辑错误、安全漏洞、协议不兼容，会导致功能失败或数据损坏 | 必须修复后才能合并 |
| **Warning** | 潜在问题：边界条件未覆盖、资源泄漏路径、竞态可能 | 建议修复 |
| **Note** | 设计观察：代码可读性、可维护性、命名建议 | 自行决定 |
| **Info** | 一般性说明：已验证的行为、已确认的设计选择 | 无需操作 |
| **Resolved** | 之前报告的问题现已确认修复 | 无需操作 |

---

## 3. 反馈文件格式

每次审查结果统一写入本地 `meta/review_feedback.md`，格式：

```markdown
# Code Review Feedback

**Reviewer:** Review Service
**Date:** YYYY-MM-DD
**Version:** vX.Y.Z
**Branch:** <branch-name>
**Scope:** <review-scope>

---

## 1. README 声明验证

...

## 2. 历史反馈追踪

...

## 3. 新代码逻辑审查

...

## 4. 特性验证

...

## 5. 汇总

...
```

写入规则：

- 每次审查**覆盖写入**本地 `meta/review_feedback.md`，只保留本次结果。
- `meta/review_feedback.md` 是生成输出，已加入 `.gitignore`，不作为公开仓库文件保存。

---

## 4. 审查范围决策

每次审查前，根据 Scope 决定执行哪些 Stage：

| Scope | 执行 Stage |
|---|---|
| 全量审查（新仓库/大版本） | 1 + 2 + 3 + 5 |
| 特性验证（针对某个 goal/milestone，如 `docs/v2/networking-goal.md`） | 1 + 4 + 5 |
| Bugfix / PR 审查 | 2 + 3 + 5 |
| 增量/小修改 | 3 + 5 |
| README 同步审查 | 1 + 5 |

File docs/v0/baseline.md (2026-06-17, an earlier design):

# V0 基线说明（1vs2 / 1vs8）

## 基线目标

1. 统一固件运行时可切 `leader/member`。
2. 在 SLE 单跳连接限制内稳定收发业务包。
3. leader 能维护基础成员表并展示到 WebUI。

## 关键实现点

- leader 采用官方 1vs8 方向的连接模型管理多连接表。
- `conn_id=0` 被视为合法连接，不能当作无效值。
- member 未被批准前进入 pending；批准后才进入 joined。
- 双 member 同时 pending/approved 与 heartbeat 已在 `v1.2.10` 现场验证。

## 典型流程

```text
member -> HELLO -> leader
leader -> pending
leader approve -> CONFIG + ACK
member -> joined + HEARTBEAT
```

## 限制

- 单跳连接仍受 SDK 物理上限约束（按 8 连接设计）。
- 当前应用层明文，`cipher_mac` 仍为预留字段。

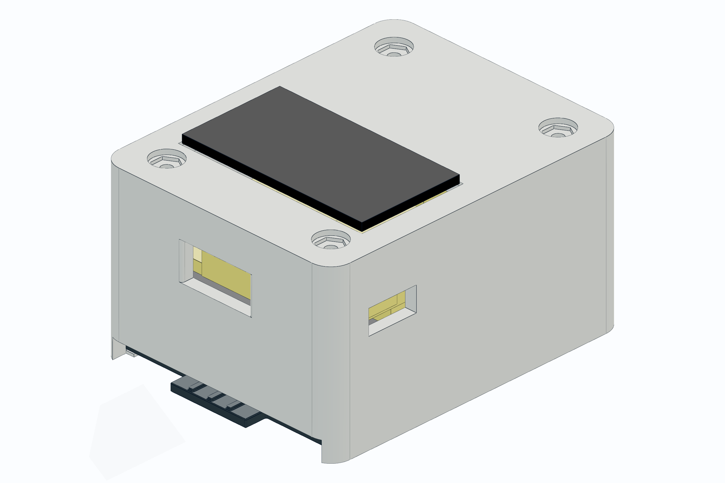
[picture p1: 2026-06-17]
hardware/enclosures/sle-pcb-enclosure/v1.1.4/preview/sle_enclosure_v1.1.4_preview_iso.png

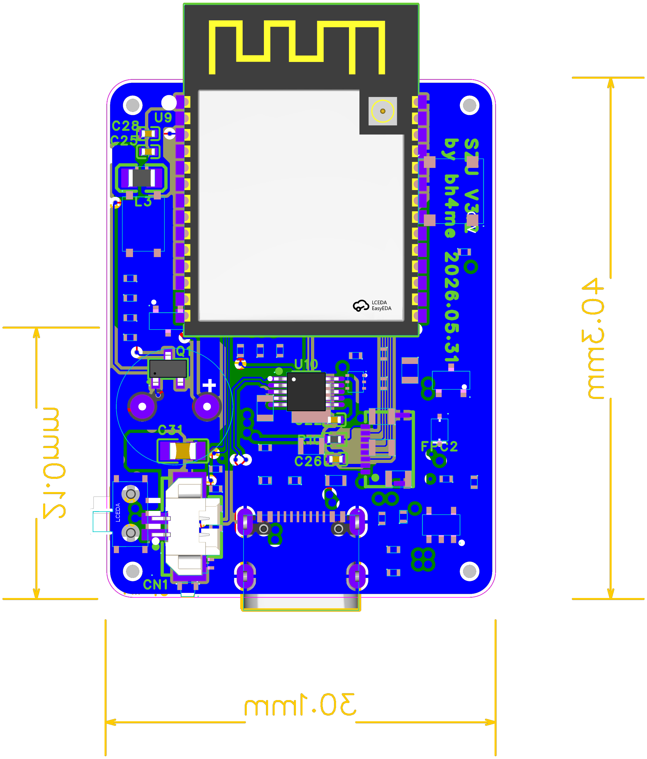
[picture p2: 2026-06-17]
hardware/boards/sle-main-board/v3.3/preview/layout_render_2.png

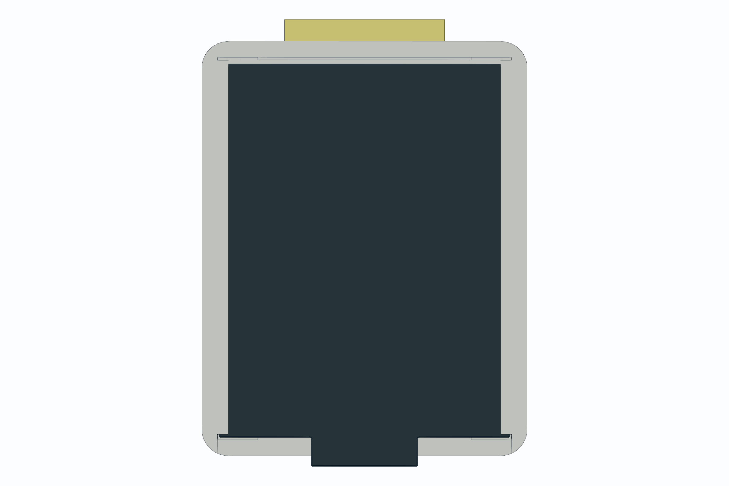
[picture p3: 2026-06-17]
hardware/enclosures/sle-pcb-enclosure/v1.1.4/preview/sle_enclosure_v1.1.4_preview_bottom.png

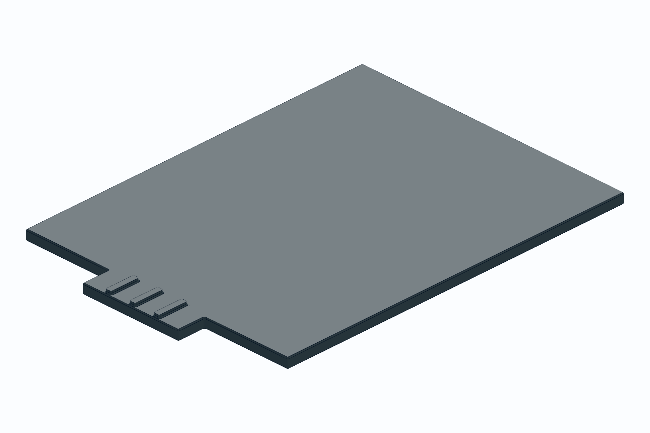
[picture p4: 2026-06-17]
hardware/enclosures/sle-pcb-enclosure/v1.1.4/preview/sle_enclosure_v1.1.4_slide_cover_iso.png

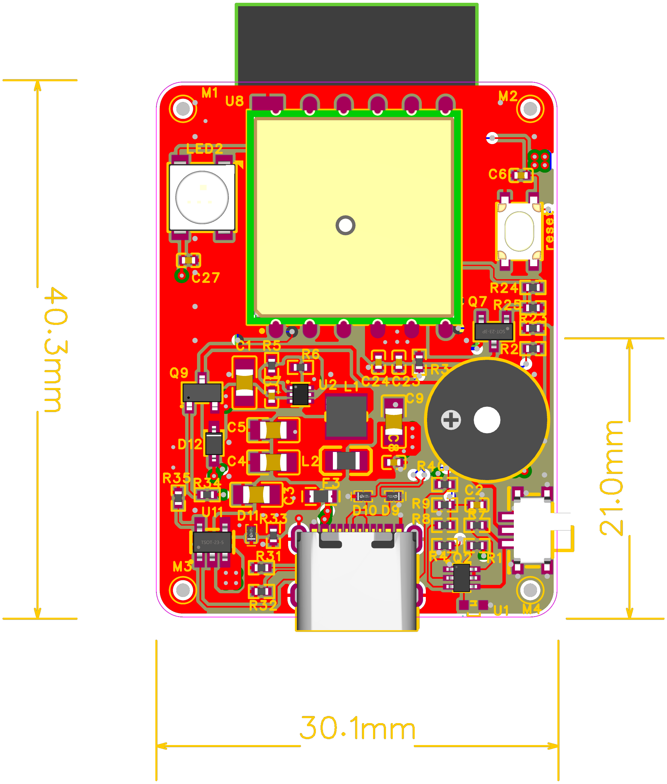
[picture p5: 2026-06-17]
hardware/boards/sle-main-board/v3.3/preview/layout_render_1.png

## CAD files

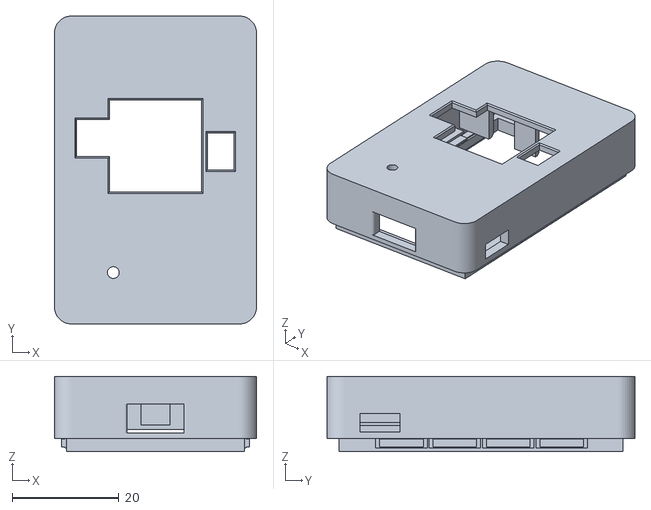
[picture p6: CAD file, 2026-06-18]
cad/stl/models/sle_enclosure_v2.1.17_no_screen_top_lock/sle_enclosure_v2_1_17_no_screen_top_lock_top_cover.stl
37.8 x 57.6 x 14.1

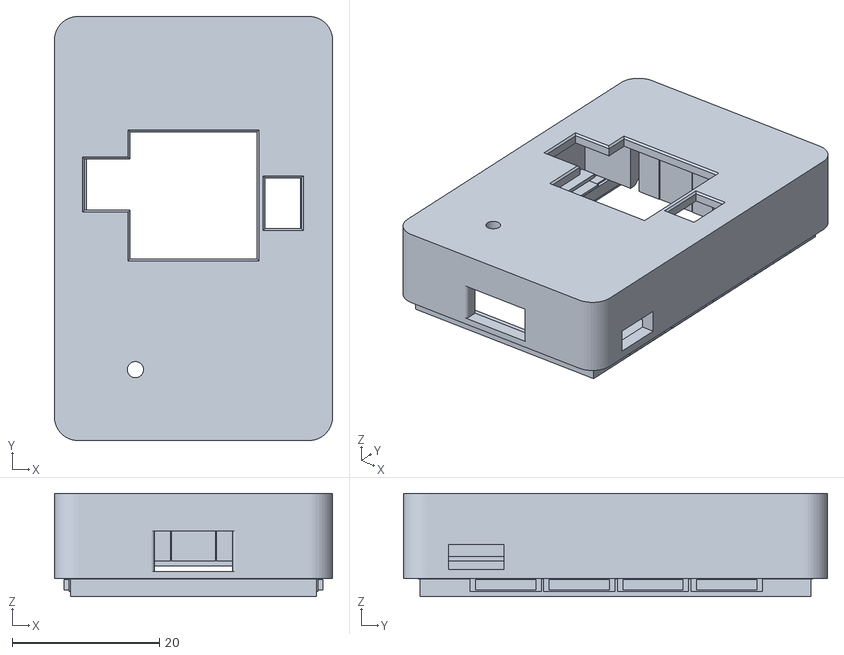
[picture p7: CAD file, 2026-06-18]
cad/stl/models/sle_enclosure_v2.1.18_no_screen_top_lock_harder/sle_enclosure_v2_1_18_no_screen_top_lock_harder_top_cover.stl
37.8 x 57.6 x 14.1

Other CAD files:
cad/stl/models/sle_enclosure_v2.1.19_screen_top_lock/sle_enclosure_v2_1_19_screen_top_lock_top_cover.stl

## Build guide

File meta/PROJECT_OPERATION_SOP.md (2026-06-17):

# Project Operation SOP

## v4.5.0-Minimal Networking Rewrite

Current code work is tracked in:

```text
docs/v4/ws63_network_rewrite_task_book.md
```

This rewrite removes the old staged/frozen topology contract and keeps only the minimal direct/member/relay flow. Use the current minimal status fields and do not treat the retired route-metrics contract as active guidance.

## v4.4.94 Relay Swap Hysteresis Entry Point

Current code work is tracked in:

```text
versions\v4.4.94\VERSION.md
```

This version keeps the dynamic relay budget and adds stable relay optimization: a non-relay node can replace the worst active relay only when its RSSI is at least 8 dB stronger for 30 seconds while the topology is otherwise stable.

For v4.4.94 in this session, remote compile was later run after the user explicitly re-enabled compile work. Hardware flash/burn is still skipped unless the user explicitly asks for it.

## v4.4.93 Dynamic Relay Historical Entry Point

The previous dynamic relay sizing work is tracked in:

```text
versions\v4.4.93\VERSION.md
```

This version changes relay sizing policy. Treat `cfg direct 1` as a small-board relay-forcing test setup, not as the normal 30-member deployment profile. Normal scaling analysis should start from the default leader direct capacity and the dynamic relay-sizing status fields.

For v4.4.93 in its session, firmware build and hardware burn were intentionally skipped because only four boards were available.

## v4.4.92 Four-Board Historical Entry Point

For the completed v4.4.92 four-board validation objective, do not rediscover commands.
Use the version runbook first:

```text
versions\v4.4.92\FLASH_AND_FOUR_BOARD_TEST.md
```

That runbook records:

- Firmware package path and expected `v4.4.92` package guard.
- Parallel flash command for `COM16,COM13,COM17,COM18`.
- COM16 leader, COM13 relay candidate, COM17/COM18 member role assignment.
- Leader `cfg direct 1` setup for one direct member and two relayed members.
- Required member reboot, relay reboot, child relay self-election, and recovery-policy checks.
- Required live logs under `logs\live\v4.4.92_four_board_com16_leader_<timestamp>`.

Current policy: do not flash blindly. Flash only when explicitly continuing the
hardware validation run, and always keep the burn/test logs as proof.

## Current Flash Flow Template

For WS63 v4 work, use `scripts/flash/ws63_flash_multi.ps1` instead of rebuilding burn commands by hand.

This section records the standard flash command shape only. It does not mean v4.4.94 has been flashed; v4.4.94 burn was intentionally not run in the relay swap hysteresis session.

Sequential flash:

```powershell
powershell -NoProfile -ExecutionPolicy Bypass -File .\scripts\flash\ws63_flash_multi.ps1 `
  -Ports COM16 `
  -ExpectedVersion v4.4.94 `
  -WaitTimeout 45 `
  -ManualRetryTimeout 0
```

Parallel flash:

```powershell
powershell -NoProfile -ExecutionPolicy Bypass -File .\scripts\flash\ws63_flash_multi.ps1 `
  -Ports COM16,COM13,COM17,COM18 `
  -ExpectedVersion v4.4.94 `
  -Parallel `
  -ParallelStartDelayMs 1200 `
  -WaitTimeout 45 `
  -ManualRetryTimeout 0
```

The verified burn flow is:

```text
software-reset-only + single reboot command + post-package handshake
```

Success must be proven by burn output and version guard:

```text
Establishing ymodem session...
Done. Reseting device...
expected: v4.4.94
```

Do not ask for manual reset during normal v4.4.94 flashing. The current boards can enter the loader through the serial `reboot` command. Use `ManualRetryTimeout=0` so failures are real evidence instead of hidden manual intervention.

Do not treat a port as flashed only because the package transfer command was attempted. If there is no boot handshake or the expected version is missing from the package, record the port as blocked and continue debugging from logs.

For multi-board flashing, prefer `-ParallelStartDelayMs 1200` or higher. This keeps the flash jobs parallel but staggers reset/handshake startup so multiple CH340 boards do not all enter the boot handshake at exactly the same moment.

Four-board validation after flashing:

```powershell
$ts = Get-Date -Format 'yyyyMMdd_HHmmss'
$logDir = "<repo-root>\logs\live\v4.4.92_four_board_com16_leader_$ts"
python .\automation\ws63\tools\ws63_four_board_relay_test.py `
  --leader-port COM16 `
  --relay-port COM13 `
  --child1-port COM17 `
  --child2-port COM18 `
  --expected-fw v4.4.92 `
  --team-id 1 `
  --channel 17 `
  --direct-cap 1 `
  --initial-drain-s 2 `
  --cmd-timeout-s 25 `
  --state-timeout-s 90 `
  --route-timeout-s 120 `
  --offline-timeout-s 20 `
  --boot-timeout-s 75 `
  --failover-timeout-s 120 `
  --poll-interval-s 1 `
  --log-dir $logDir
```

The four-board tool defaults to clean-start: it sends `cfg clear`, reboots each board, verifies `runtimeConfigured=false`, then configures COM16 as leader and COM13/COM17/COM18 as members. Use `--no-clean-start` only for a deliberate diagnostic replay.

这份文档是 `sle_mesh` 工程的强制作业入口。以后每次改代码、改脚本、改 WebUI、改固件参数、远程编译或烧录前，都先读这里；如果流程变化，必须同步更新这里和本次版本记录。

## 1. 每次开工前

1. 先读本文件，再读当前最新版本目录的 `VERSION.md` 和 `MANIFEST.md`。
2. 执行 `git status --short --branch`，确认当前分支、脏文件和未跟踪产物。
3. 确认最新版本号：优先看 `README.md` 的“当前版本”和 `versions/README.md` 顶部。
4. 不要回退别人或上一次调试留下的改动；如果改动冲突，先停下来确认。
5. 新工作默认在 `line/` 前缀分支上完成，除非用户明确要求别的分支。

## 2. 版本管理硬规则

每次代码行为变化都必须升版本，不能继续停在旧版本号。

默认规则：

1. 小修、文档流程、参数同步、bugfix：补丁号加一，例如 `v4.4` -> `v4.4.1`。
2. 新功能或跨模块同步：小版本加一，例如 `v4.4.1` -> `v4.5`。
3. 重大架构变化或不可兼容协议：主版本加一。
4. 不覆盖旧版本目录；新增 `versions/<new-version>/`。
5. 固件代码变更时，必须同步更新固件版本字符串、启动日志可见版本、屏幕可见版本。

每次版本记录至少包含：

1. `versions/<version>/VERSION.md`：本版定位、解决了什么、已知限制。
2. `versions/<version>/MANIFEST.md`：改了哪些文件、如何验证、构建产物路径、包大小、时间。
3. `versions/README.md`：新版本放到顶部。
4. `README.md`：当前版本和关键入口同步更新。
5. 如果烧录或硬件问题流程变化，更新本 SOP。

## 3. 远程 Ubuntu 编译

WS63 固件优先使用局域网 Ubuntu 编译机，不使用本地虚拟机作为默认路径。

当前默认编译机：

```text
Host: 192.168.6.5
User: owen
SDK: /home/owen/workspace/bearpi-pico_h3863
Project app: /home/owen/workspace/bearpi-pico_h3863/application/samples/products/sle_team_network
Protocol copy: /home/owen/workspace/bearpi-pico_h3863/third_party/sle_mesh
```

标准编译命令：

```sh
UBUNTU_HOST=192.168.6.5 \
UBUNTU_USER=owen \
UBUNTU_PASS='<set locally, do not commit secrets>' \
UBUNTU_SDK=/home/owen/workspace/bearpi-pico_h3863 \
BUILD_JOBS=4 \
scripts/build/ws63_build_v4_ubuntu.sh unified
```

输出固件固定记录为：

```text
<repo-root>\output_from_vm\team_network_v4_unified_runtime_role\ws63-liteos-app_v4_unified_all.fwpkg
```

如果本机缺少 `sshpass` 或 `rsync`，允许用 Python `paramiko` 做同等步骤，但版本记录里必须写清楚使用了 fallback。

## 4. 自动烧录

COM16 成功路径：

```powershell
python <repo-root>\automation\ws63\tools\ws63_auto_burn.py `
  -p COM16 `
  -b 115200 `
  --software-reset-only `
  --reset-command reboot `
  --reset-command-fallback reset `
  --reset-command-delay 0.3 `
  --reset-command-retries 2 `
  --reset-command-retry-gap 0.2 `
  <repo-root>\output_from_vm\team_network_v4_unified_runtime_role\ws63-liteos-app_v4_unified_all.fwpkg
```

注意事项：

1. 这块板子不能假设有 RTS/DTR 自动复位硬件。
2. `--software-reset-only` 依赖旧固件串口能响应 `reboot` 或 `reset`。
3. 如果旧固件无响应，需要用户手动按 `RESET/RST` 配合进入烧录。
4. 烧录成功后必须在版本记录写清楚端口、命令、是否手动 reset、固件包路径。

## 5. 屏幕和硬件固定结论

当前确认的 ST7789 1.14 寸屏参数：

```text
SCLK/SCL: GPIO6
CS: GPIO7
MOSI/SDA: GPIO8
DC/RS: GPIO9
RESET: GPIO13
BLK/backlight: 硬件默认开启，固件不要控制 GPIO11
Logical size: 240x135
X offset: 40
Y offset: 53
MADCTL: 0x60
SPI: software SPI mode 0
```

历史坑：

1. `135x240 + offset 52,40` 会出现局部变色、周围花屏。
2. BLK/GPIO11 不再写固件控制逻辑，避免误判背光。
3. 屏幕问题完整记录见 `versions/v4.4/ST7789_DISPLAY_FIX.md`。

## 6. 批量串口配置

30 个节点批量部署时，优先使用串口或 WebSerial 一键配置，不要逐个连接 WiFi。

串口参数：

```text
115200 8N1
```

常用命令：

```text
cfg status
cfg leader now <team> <channel>
cfg member now <leader_suffix_hex> <team> <channel>
cfg apply
cfg clear
cfg reboot
```

Windows helper：

```powershell
powershell -ExecutionPolicy Bypass -File scripts/serial/ws63_serial_cfg.ps1 -Port COM7 -Mode leader -Team 7 -Channel 33
powershell -ExecutionPolicy Bypass -File scripts/serial/ws63_serial_cfg.ps1 -Port COM8 -Mode member -LeaderSuffix 9A2F -Team 7 -Channel 33
powershell -ExecutionPolicy Bypass -File scripts/serial/ws63_serial_cfg.ps1 -Port COM8 -Mode status
```

域名 WebUI 的 `Settings -> One-click node config` 使用 WebSerial 读取 `[cfg-json]` 并显示串口日志。

## 7. 必跑验证

按影响范围执行，能多跑就多跑。

文档和通用检查：

```sh
git diff --check
```

外部 WebUI 改动：

```sh
npm --prefix webui test
npm --prefix webui run build
```

固件业务代码、Kconfig、显示、串口、SLE、WiFi 改动：

```sh
UBUNTU_HOST=192.168.6.5 \
UBUNTU_USER=owen \
UBUNTU_PASS='<set locally, do not commit secrets>' \
UBUNTU_SDK=/home/owen/workspace/bearpi-pico_h3863 \
BUILD_JOBS=4 \
scripts/build/ws63_build_v4_ubuntu.sh unified
```

如果修改协议核心，补跑对应 C 侧或 Python 仿真测试，并把命令写入 `MANIFEST.md`。

## 8. 回退方法

1. 先查 `versions/README.md`，找到目标版本。
2. 读目标版本的 `VERSION.md` 和 `MANIFEST.md`，确认它对应的固件包、提交和验证记录。
3. 如果只是恢复板子，优先烧录旧 `.fwpkg`。
4. 如果要恢复代码，使用 Git 分支/提交回退，不要手动覆盖多个文件。
5. 回退后仍要记录一次新版本，说明为什么回退、回退到哪个版本、验证结果是什么。

## 9. 本文件维护规则

1. 任何人发现自动烧录、远程编译、版本管理、屏幕参数、串口配置流程和本文件不一致，必须马上更新本文件。
2. 本文件是长期 SOP，不写临时草稿；临时过程写入对应 `versions/<version>/`。
3. 如果下一次任务只改文档，也要遵守版本记录规则，因为文档会影响后续烧录和回退判断。

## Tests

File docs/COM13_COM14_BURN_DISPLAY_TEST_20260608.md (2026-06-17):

# COM13/COM14 烧录与实体屏幕检测记录

记录时间：2026-06-08 00:52 CST

## 结论

- `COM13` 烧录测试通过，`v4.4.99` 完整包所有分区传输到 100%，最后输出 `Done. Reseting device...`。
- `COM14` 按要求使用硬件 RTS 复位烧录，硬件复位流程确实执行，但该路径未通过：一次进入 ROM 后在 `root_loaderboot_sign.bin` 传输 77% 失败，另外两次等待 ROM handshake timeout。
- `COM13` 和 `COM14` 的 `disp status` / `disp demo` 都返回 `disp ready=1` 和 demo `ret=0`。
- 当前硬件/固件不能仅靠串口判断哪块没有接入实体 ST7789 屏幕，因为屏幕接口只有 `SCL/SDA/CS/RS/RESET` 写入/控制线，没有 `MISO`、`TE`、`ID`、触摸或其他可读回检测线。

## 烧录证据

`COM13` 成功日志：

```text
logs/burn/v4.4.99_20260608_003332/COM13.log
ROM handshake ACK
Transferring ... 100%
Done. Reseting device...
```

`COM14` 硬件复位失败日志：

```text
logs/burn/v4.4.99_20260608_003809/COM14.log
Auto reset: RTS=1
Auto reset: RTS=0
Download control-line release: RTS=0 DTR=0
ROM handshake ACK
root_loaderboot_sign.bin 77%
Error transferring root_loaderboot_sign.bin
```

```text
logs/burn/v4.4.99_20260608_003935/COM14.log
Auto reset: RTS=1
Auto reset: RTS=0
Auto handshake timeout
```

```text
logs/burn/v4.4.99_20260608_004020/COM14.log
Auto reset: RTS=0
Auto reset: RTS=1
Auto handshake timeout
```

## 屏幕测试证据

`COM13`：

```text
logs/serial/com13_disp_demo_v4.4.99_20260608_005225.log
[cli] disp ready=1 spi=0 sclk=7 sda=9 cs=8 rs=10 rst=13 size=240x135 off=40,53
[display-event] event=LOST label=M63 member=99 ret=0
```

`COM14`：

```text
logs/serial/com14_disp_demo_v4.4.99_20260608_005225.log
[cli] disp ready=1 spi=0 sclk=7 sda=9 cs=8 rs=10 rst=13 size=240x135 off=40,53
[display-event] event=LOST label=M63 member=99 ret=0
```

## 为什么不能判断哪块没接实体屏幕

当前屏幕接口和固件配置只有：

```text
SCL/SCLK -> IO07
SDA/MOSI -> IO09
CS       -> IO08
RS/DC    -> IO10
RESET    -> IO13
```

没有可读回的 `MISO` 或屏幕 ID 线。固件里的 `disp ready=1` 表示 ST7789 驱动初始化流程完成、GPIO/SPI 写出成功；即使屏幕模组物理未接入，这类纯写接口也不会自动返回失败。

## 当前可执行的实体屏幕确认方式

已经对两块板下发 `disp demo`。现场肉眼看屏幕：

- 哪块显示 `LOST / M63` demo 画面，哪块就接了实体屏幕。
- 哪块没有任何显示，哪块就是未接实体屏幕、屏幕供电异常、排线/焊接异常或屏幕损坏。

如果要让固件以后自动判断实体屏幕，需要硬件增加至少一种可读回信号，例如 `MISO` 读 ST7789 ID、屏幕连接检测脚、背光电流检测、TE 脚、触摸控制器 I2C ID，或其他能被 MCU 读取的屏幕在位信号。

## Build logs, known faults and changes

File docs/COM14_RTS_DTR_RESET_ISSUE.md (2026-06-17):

# COM14 CH340 RTS/DTR 复位问题记录与解决方案

记录日期：2026-06-07

## 结论

COM14 是带 CH340E 和 MOS 管硬件复位电路的自制板。这个问题表面看起来像“下载到一半又被 RTS/DTR 复位”，但现有日志验证后，结论更准确地分成两层：

1. COM14 的硬件复位电路确实对 CH340E 的 `RTS#` 状态敏感，因为 `RTS#` 是低有效信号。
2. 这次已经复现并验证的“下载到一半失败”，直接原因不是烧录脚本中途再次切 RTS/DTR，而是 Windows/CH340 在 1029 字节 YMODEM 阻塞写入时发生 timeout。

2026-06-08 最新统一策略：

- COM14 不再把 `-HardwareReset` 作为可用烧录方案。
- `scripts/flash/ws63_flash_multi.ps1` 检测到 `COM14` 后启用 `COM14 safe profile`。
- `COM14 safe profile` 默认直接拒绝 `-HardwareReset`、拒绝 `blocking` 写入、拒绝 `SerialWriteChunkSize` 分包，并把 `WaitTimeout` 提升到 30 秒。
- 以后 COM14 固定使用 `software-reset-only + reboot + RTS=0 DTR=0 + no post-open control assertion + 1024-byte YMODEM + fresh receiver C + nonblocking-drain + full flash-session retry`。
- 不再复用 ROM handshake 读包里混带的 `C`；每个 YMODEM 文件传输前都必须重新等待一个新的接收端 `C`。
- COM14 不做同一 ROM 会话内的 YMODEM 文件级重试；失败后重新打开串口、重新软件复位、重新 handshake，再从头烧录。
- COM14 safe profile 先做 ROM 预探测：如果 ROM handshake 已经 active，就跳过 `reboot` 直接烧录；如果 ROM 不 active，才发送软件 `reboot`。
- 如果 COM14 已经进入“串口可打开，但 `cfg status` 无回复、静默 ROM handshake 也无 ACK”的状态，说明已经没有串口软件控制入口；此时不要继续尝试 RTS 硬件烧录，必须先按一下复位、断电重上电、拔插 USB，或修硬件复位电路，让板子回到 CLI 或 ROM 后再执行 safe profile。

之前“又失败”的原因是后来按要求强制 COM14 使用了硬件 RTS 复位；实测证明这条硬件复位入口本身不稳定，所以新的软件解决方案是脚本层面防止 COM14 再走这条路径。

所以最终软件方案不是分包，而是：

- 不走 RTS 硬件复位进入下载。
- 串口打开前就预置空闲状态：`RTS=0`、`DTR=0`。
- 使用软件复位命令 `reboot` 进入 ROM 下载模式。
- YMODEM 仍保持 1024 字节包。
- 串口写入模式改为 `--serial-write-mode nonblocking-drain`。
- 每个 YMODEM 传输前等待 fresh `C`，不能复用 handshake 读到的 `C`。
- `--ymodem-transfer-retries` 固定为 `1`；COM14 safe profile 使用 `--flash-attempts 2` 做完整会话重试。
- `--skip-reset-if-rom-active` 固定启用；板子已在 ROM 时不再额外发送 CLI `reboot`。
- 当前烧录工具默认就是 `nonblocking-drain`，不需要再用 `--serial-write-chunk-size`。
- 下载期间启用 RTS/DTR guard，后续如果有任何 RTS/DTR 变化，直接报显式错误。

成功验证过的 COM14 烧录没有使用 `--serial-write-chunk-size`，也就是没有走分包方案。

## 板卡区分

- `COM14`：自制 CH340E 板，带 MOS 管硬件复位电路。
- `COM13`：对照板，没有 MOS 管硬件复位电路。
- `COM23`、`COM24`、`COM25`、`COM26`：小熊派后续测试用板，其中 `COM26` 配置为 leader。

当前优先解决对象是 `COM14`。

## 现象

COM14 焊上 MOS 管后：

- 手动复位可以进入下载，但烧录到一半可能失败。
- RTS 复位也可以进入下载，但烧录到一半也可能失败。
- 失败多表现为 YMODEM 写串口时 timeout。
- 典型失败点是一次 1029 字节写入，1024 字节数据包加 YMODEM 头和校验。

COM14 拆掉 MOS 管后：

- 仅手动复位时，不再触发同样的“下载一半失败”问题。

分包后：

- 烧录可以正常。
- 但分包只是降低单次串口写入压力，不是首选方案。

## 为什么 MOS 管会放大这个问题

原理图中的信号是 CH340E `RTS#`，不是普通意义上的高有效 `RTS`。`#` 表示低有效。

当前电路图确实有硬件复位：`SCH_Schematic1_2_2026-06-07.pdf` 第 3 页中，CH340E 的 `RTS#` 网标接到 Q1/MOS 复位电路，Q1 再影响 WS63 模块的 `EN`；旁边还有 SW1 手动把 `EN` 拉到 GND 的复位按键。

但这条硬件复位只能说明“PC 可能通过 CH340 的 RTS# 改变 EN”，不能直接等价为“软件烧录时可以可靠进入 ROM 下载”。原因有三个：

- CH340E 暴露的是 `RTS#` 低有效脚，pyserial 里的 `ser.rts=True/False` 和引脚电平/EN 行为容易被反相误解。
- 这条电路是 RTS# 到 EN 的电平控制路径，不是边沿限宽的一次性复位脉冲；如果空闲态、打开串口瞬间、或下载期间的保持态不对，可能变成保持复位、误复位、或复位时机错误。
- `BOOT` 在图中是 WS63 的 IO3，没有接到 CH340 的 RTS/DTR 控制线；所以软件只能尝试复位并等待 ROM handshake，不能同时保证 BOOT/下载条件。

在 pyserial/Windows 语义里，设置 RTS 的布尔状态和 CH340 实际 `RTS#` 引脚电平之间容易产生误解。结果就是：如果把 `RTS#` 直接接进 MOS 管复位路径，串口打开瞬间、驱动默认状态、复位脉冲极性、或者下载期间保持的控制线状态，都可能影响 EN/RESET。

因此 COM14 不能依赖这种旧流程：

```text
先 open 串口，再 setRTS(False)
```

更安全的流程是：

```text
先创建未打开的 serial.Serial()
预置 ser.rts = 0、ser.dtr = 0
再 open()
```

这样可以减少打开串口瞬间由 RTS/DTR 默认状态造成的误复位风险。

## 已验证的证据

烧录脚本已经加过保护和日志：

- `open_serial_for_burn()`：在打开串口前预置 `RTS=0`、`DTR=0`。
- `ControlLineGuard`：下载阶段拦截 `setRTS()`、`setDTR()`、`ser.rts = ...`、`ser.dtr = ...`。
- 串口写失败时会记录 RTS/DTR/CTS/DSR 和写入队列状态。

关键证据是：

- 阻塞写模式下，日志显示 `RTS=0 DTR=0`，没有 control-line guard violation，但仍可能在 1029 字节写入时 timeout。
- 只把写入模式改为 `nonblocking-drain` 后，COM14 使用 1024 字节 YMODEM 包完整烧录成功。
- 成功命令没有包含 `--serial-write-chunk-size`。
- 2026-06-08 按要求强制 `COM14` 使用 `-HardwareReset` 后，日志证明硬件复位流程确实执行了，但该路径不稳定：
  - `logs/burn/v4.4.99_20260608_003809/COM14.log`：执行 `Auto reset: RTS=1` 后 `Auto reset: RTS=0`，随后 `Download control-line release: RTS=0 DTR=0`，guard 期间保持 `rts=0 dtr=0`，ROM handshake 成功，但 `root_loaderboot_sign.bin` 传输到 77% 后 ACK timeout。
  - `logs/burn/v4.4.99_20260608_003935/COM14.log`：同样硬件 RTS 复位序列后，等待 ROM handshake timeout。
  - `logs/burn/v4.4.99_20260608_004020/COM14.log`：反向 RTS 序列 `rts=0:0.25;rts=1:0.5` 后，等待 ROM handshake timeout。
- 上述硬件复位日志没有出现 `Unexpected RTS change` 或 `Unexpected DTR change`，所以没有证据表明烧录脚本在 YMODEM 中途再次触发 CH340 的 RTS/DTR。
- 2026-06-08 09:38/09:40 的 safe profile 已经使用软件 `reboot`、`RTS=0 DTR=0`、`nonblocking-drain` 进入 ROM，但第一个 `root_loaderboot_sign.bin` 的 YMODEM 失败。
- 这次新的软件原因是烧录器把 ROM handshake 读包中混带的 `C` 记录成 `_ymodem_receiver_ready`，随后跳过 YMODEM 前的 fresh `C` 等待。这个行为和供应商原流程不同，也和 2026-06-07 成功日志不同。
- 最新修正已经改为：handshake 读到 `C` 只记录日志，不作为可复用状态；YMODEM 每次都重新等待 fresh `C`。
- 09:38/09:40 的日志还证明同一 ROM 会话内重试整个 YMODEM 文件不能有效恢复，所以 COM14 safe profile 改为文件级重试 `1` 次、完整 flash session 默认 `2` 次。
- 2026-06-08 10:57 使用最新 safe profile 做真实验证，脚本参数已经正确生效：`ymodem_transfer_retries: 1`、`flash_attempts: 2`、`serial_write_mode: nonblocking-drain`、`RTS=0 DTR=0`。
- 但该次验证两次完整会话都在 ROM handshake timeout：`logs/burn/codex_com14_verify_20260608_105719/v4.4.99_20260608_105720/COM14.log`。
- 验证后，`cfg status` 无回复，静默 ROM handshake 无 ACK，Windows PnP 禁用/启用 COM14 CH340 因权限失败，两种 RTS handshake-only 脉冲也没有 ACK。
- 因此当前 COM14 已处在无串口软件入口状态。软件方案能防止再次走错误的硬件 RTS 烧录路径，也能修复 YMODEM fresh-C 同步问题；但不能在 MCU 完全无 CLI/无 ROM 响应时凭空复位芯片。

成功日志：

```text
logs/burn/com14_software_reset_nonblock_drain_1024_20260607_171545/stdout_stderr.log
logs/burn/com14_software_reset_nonblock_drain_1024_20260607_171545/exit.txt
```

成功日志中的关键行包括：

```text
Serial opened with idle RTS=0 DTR=0
Serial write mode: nonblocking-drain
Download control-line guard active
ROM handshake ACK: ... rts=0 dtr=0 ...
Transferring ... 100%
Done. Reseting device...
exit=0
```

## 根因判断

根因不是单一的“脚本中途又复位了”。

更准确的判断是：

1. 硬件层面：COM14 的 MOS 管复位电路对 CH340E `RTS#` 状态敏感。`RTS#` 是低有效，如果极性、初始状态或打开串口瞬间处理不好，确实可能导致误复位或复位保持。
2. 硬件复位路径：强制 `COM14` 走 RTS 硬件复位时，ROM 入口本身不稳定；即使偶尔进入 ROM，也可能在 loader YMODEM 阶段 ACK timeout。该失败不是由脚本中途再次切 RTS/DTR 造成的。
3. 软件传输层面：已经验证到的中途失败，是 Windows/CH340 在 1029 字节阻塞写入时 timeout。这个 timeout 在带 MOS 管的 COM14 上更容易暴露，但 guard 日志没有证明下载过程中脚本又切了 RTS/DTR。

分包能成功，是因为它把一次 1029 字节写入拆成更小写入，降低了 CH340/Windows 写队列压力。但这改变了串口写入节奏，只适合作为备用 workaround。

首选方案是 `nonblocking-drain`：仍按 1024 字节 YMODEM 包发送，只是不再用一次阻塞写死等，而是非阻塞写入后等待 TX 队列排空。

## 推荐的 COM14 单板烧录命令

推荐使用这个不分包命令：

```powershell
E:\codex_documents\sle\.tooling\py311\python.exe `
  E:\codex_documents\sle\automation\ws63\tools\ws63_auto_burn.py `
  -p COM14 `
  -b 115200 `
  --software-reset-only `
  --reset-command reboot `
  --no-reset-command-fallback `
  --no-compat-reset-command `
  --reset-command-delay 0.05 `
  --reset-command-retries 1 `
  --reset-command-retry-gap 0 `
  --idle-rts 0 `
  --idle-dtr 0 `
  --no-assert-control-after-open `
  --wait-timeout 30 `
  --manual-retry-timeout 0 `
  --ymodem-packet-size 1024 `
  --ymodem-transfer-retries 1 `
  --serial-write-mode nonblocking-drain `
  --serial-write-drain-timeout 3.0 `
  --skip-reset-if-rom-active `
  --rom-preflight-timeout 1.0 `
  --flash-attempts 2 `
  --expected-version v4.4.99 `
  E:\codex_documents\sle\output_from_vm\team_network_v4_unified_runtime_role\ws63-liteos-app_v4_unified_all.fwpkg
```

期望看到：

```text
ROM handshake ACK
Transferring ws63-liteos-app-sign.bin...
Done. Reseting device...
exit=0
```

## 批量脚本用法

`scripts/flash/ws63_flash_multi.ps1` 已经默认使用同样的不分包写入模式。

COM14 推荐：

```powershell
powershell -NoProfile -ExecutionPolicy Bypass `
  -File E:\codex_documents\sle\scripts\flash\ws63_flash_multi.ps1 `
  -Ports COM14 `
  -ExpectedVersion v4.4.99 `
  -WaitTimeout 30 `
  -ManualRetryTimeout 0 `
  -SerialWriteDrainTimeout 3.0 `
  -YmodemPacketSize 1024 `
  -FlashAttempts 2
```

脚本检测到 `COM14` 时会自动启用安全策略，所以上面的命令会生成如下关键参数：

```text
--software-reset-only
--reset-command reboot
--no-reset-command-fallback
--no-compat-reset-command
--idle-rts 0
--idle-dtr 0
--no-assert-control-after-open
--ymodem-packet-size 1024
--ymodem-transfer-retries 1
--serial-write-mode nonblocking-drain
--skip-reset-if-rom-active
--flash-attempts 2
```

正常使用时不要加：

```text
-SerialWriteChunkSize
```

也不要给 COM14 加：

```text
-HardwareReset
```

如果误加，脚本会直接报错并拒绝烧录。只有做诊断时才允许显式加 `-AllowUnsafeCom14HardwareReset`，但这不是常规方案。

## 不推荐作为 COM14 常规方案

不要把下面两个作为 COM14 的常规烧录路径：

```text
-HardwareReset
--control-sequence rts=0:0.25;rts=1:0.5
--serial-write-chunk-size 16 --serial-write-gap 0.001
```

原因：

- `-HardwareReset` 和 `--control-sequence ...` 都依赖 RTS 硬件复位路径，实测 COM14 ROM 入口不稳定。
- 分包只对已经进入 ROM/YMODEM 的传输阶段有意义；2026-06-08 13:48 复测时 COM14 失败在 ROM handshake 之前，分包没有机会生效。

## 硬件修改建议

如果后续仍希望保留 RTS 自动复位，不建议让 CH340E `RTS#` 通过 MOS 管形成一个能长期控制 EN/RESET 的直流通路。

更推荐的硬件行为是：RTS 只能产生一个短复位脉冲，不能长期保持复位，也不能在 YMODEM 传输期间再次触发复位。

可选方向：

- 用 RC/AC 耦合或单稳态电路，把 RTS 转成边沿触发的短脉冲。
- 加跳帽或门控，让烧录时可以断开 RTS 复位路径。
- 给 EN/RESET 做更明确的上拉和滤波，保证 CH340 默认状态或串口打开瞬间不会把板子保持在复位。
- 重新核对 MOS 管方向、上拉/下拉阻值、`RTS#` 极性，确保低有效逻辑被正确反相或隔离。

## 后续验收清单

以后检查 COM14 烧录时，确认这些点：

- 烧录前如果 `cfg status` 无回复且静默 ROM handshake 无 ACK，先物理复位/断电/拔插 USB；不要继续烧录。
- 命令包含 `--ymodem-packet-size 1024`。
- 日志或命令显示 `nonblocking-drain`。
- 日志或命令显示 `--flash-attempts 2` 或 `flash_attempts: 2`。
- 日志或命令显示 `--skip-reset-if-rom-active`。
- 日志显示 `ROM handshake read also contained YMODEM receiver C; waiting for fresh C` 时，后续仍必须正常等待 fresh `C`，不能跳过。
- 命令不包含 `--serial-write-chunk-size`。
- 日志包含 `Serial opened with idle RTS=0 DTR=0`。
- 日志包含 `Download control-line guard active`。
- 日志不包含 `Unexpected RTS change`。
- 日志不包含 `Unexpected DTR change`。
- 日志不包含 `Serial write failed`。
- 日志最后有 `Done. Reseting device...`。
- 进程退出码是 `0`。

## 一句话版

COM14 的 MOS 管复位电路确实让 CH340E `RTS#` 变成高风险控制线；按要求强制硬件复位时，实测 ROM 入口不稳定，且没有证据表明脚本在下载中途又切 RTS/DTR。当前主方案仍是固定 `RTS=0 DTR=0`、软件复位、YMODEM 1024 包不变，并使用 `nonblocking-drain` 写入模式。

最新执行规则：以后 COM14 一律使用 `ws63_flash_multi.ps1` 的 `COM14 safe profile`；不要加 `-HardwareReset`，不要分包。脚本已经把这条规则固化，误用硬件复位会被拒绝。

## 2026-06-08 13:48 强制硬件复位和分包复测

按现场要求，对 COM14 强制绕过 safe profile，启用 `-HardwareReset -AllowUnsafeCom14HardwareReset`，并启用串口写入分包。

- 固件：`output_from_vm/team_network_v4_unified_runtime_role/ws63-liteos-app_v4_unified_all.fwpkg`
- 版本：`v4.4.100`
- 分包参数：`SerialWriteChunkSize=256`、`SerialWriteGap=0.005`、`SerialWriteMode=nonblocking-drain`
- 尝试过的复位/握手组合：RTS 正反向、DTR 单独切换、RTS+DTR 同向/交叉切换、RTS 1s/2s 长脉冲、3 分钟人工复位等待窗口。
- Windows PnP disable/enable COM14 CH340 失败，系统返回“常规故障”。
- 结果：全部失败在 ROM handshake 阶段，未进入 YMODEM 文件传输，所以本轮失败不是分包写入失败。
- 相关日志：
  - `logs/burn/v4.4.100_20260608_134818/COM14.log`
  - `logs/burn/v4.4.100_20260608_135011/COM14.log`
  - `logs/burn/v4.4.100_20260608_135341/COM14.log`

同期同一固件已成功烧录到 `COM13`、`COM23`、`COM24`、`COM25`、`COM26`。COM14 当前阻塞点是板端没有被 PC 侧 RTS/DTR 控制带入 WS63 ROM 下载模式；需要板端实际进入 ROM 后，256B 串口分包参数才会生效。

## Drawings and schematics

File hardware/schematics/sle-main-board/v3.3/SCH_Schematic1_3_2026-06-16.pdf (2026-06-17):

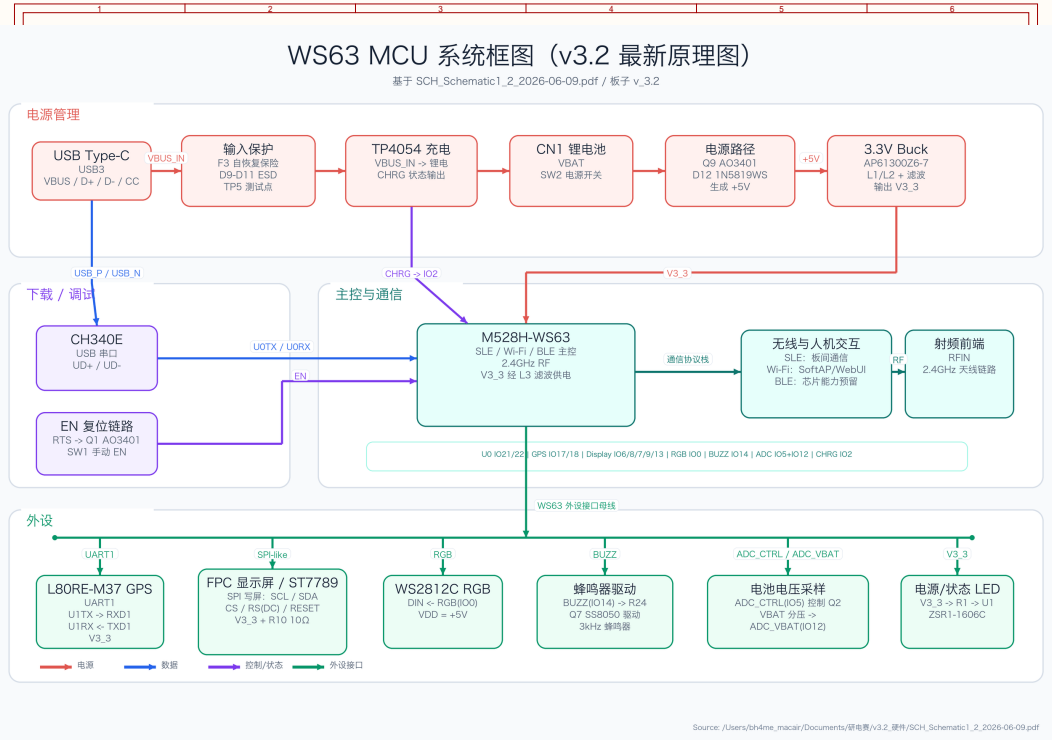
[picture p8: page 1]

原理图 | Schematic1_3 | 创建日期 | 2026-06-09

更新日期 | 2026-06-15

板子 | v_4.2 | 图页 | tree
绘制 | | sle_v3
审阅

V1.0 | A4 | 嘉立创EDA

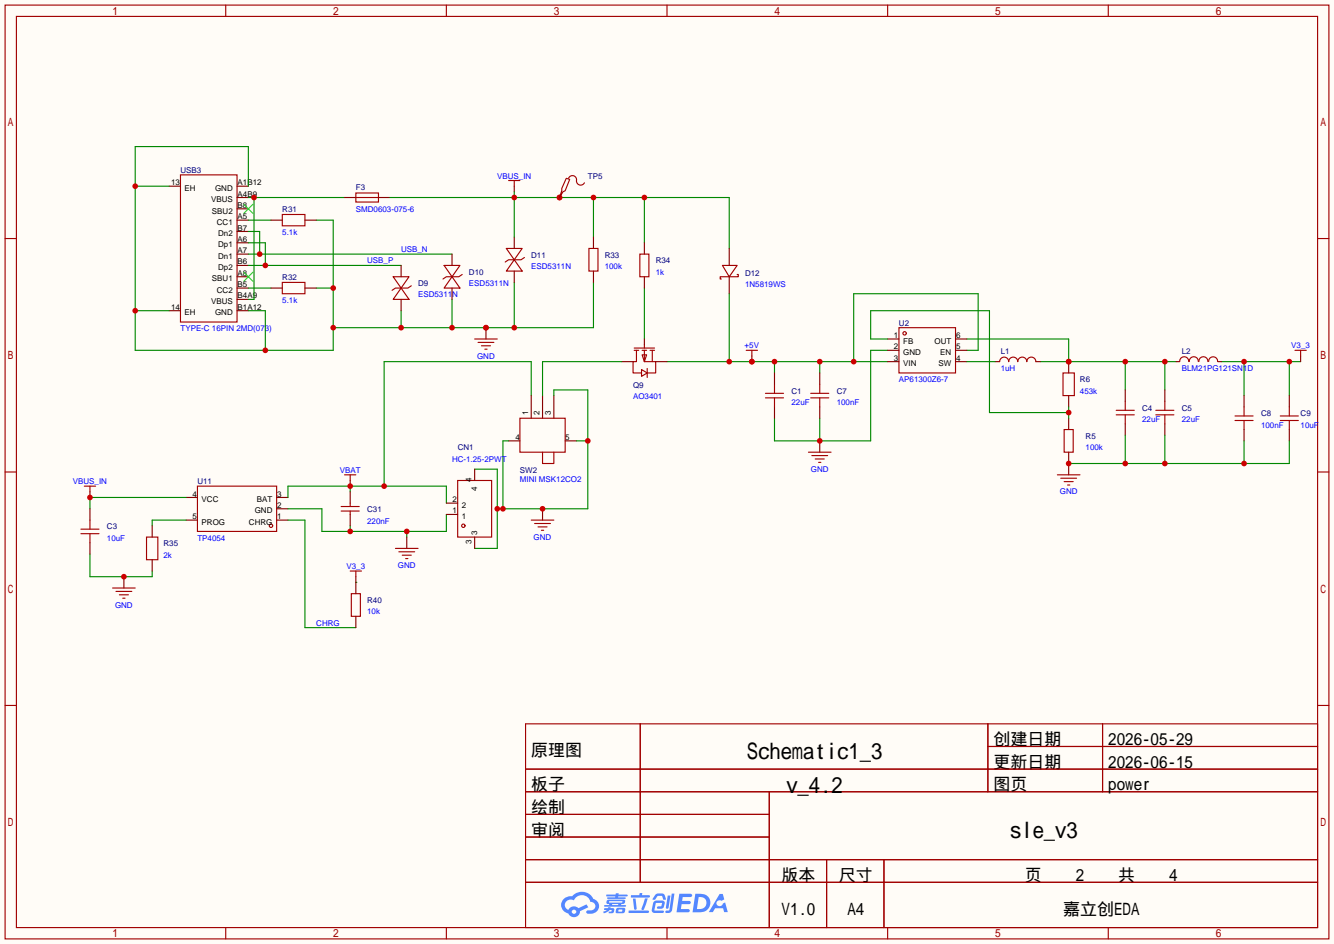
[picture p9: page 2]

原理图 | Schematic1_3 | 创建日期 | 2026-05-29

更新日期 | 2026-06-15

板子 | v_4.2 | 图页 | power
绘制 | | sle_v3
审阅

USB-UART | AUTO-EN | KEY | ADC

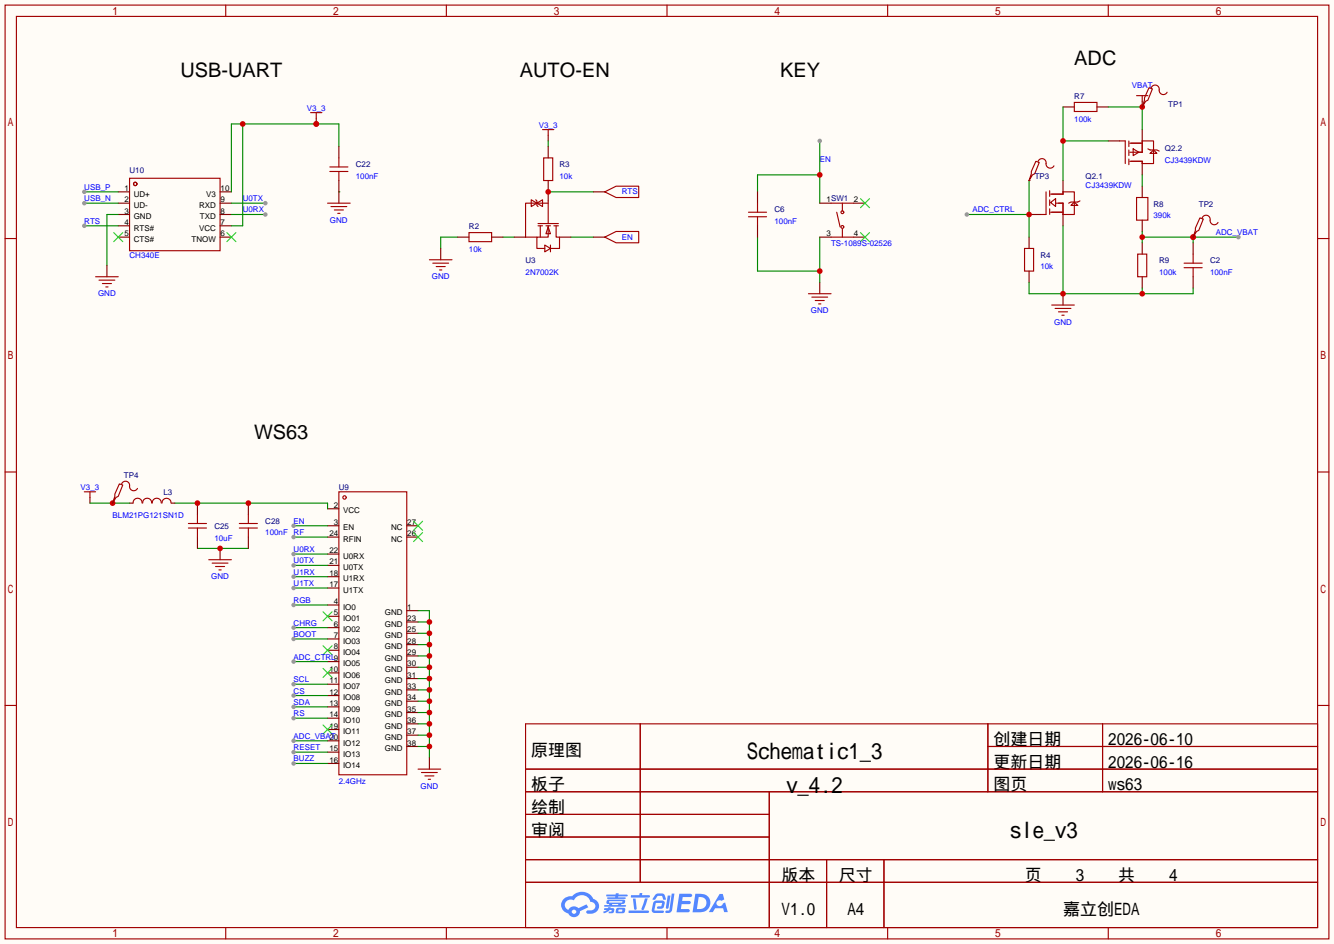
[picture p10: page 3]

原理图 | Schematic1_3 | 创建日期 | 2026-06-10

更新日期 | 2026-06-16

板子 | v_4.2 | 图页 | ws63
绘制 | | sle_v3
审阅

GPS | LCD | LED_S

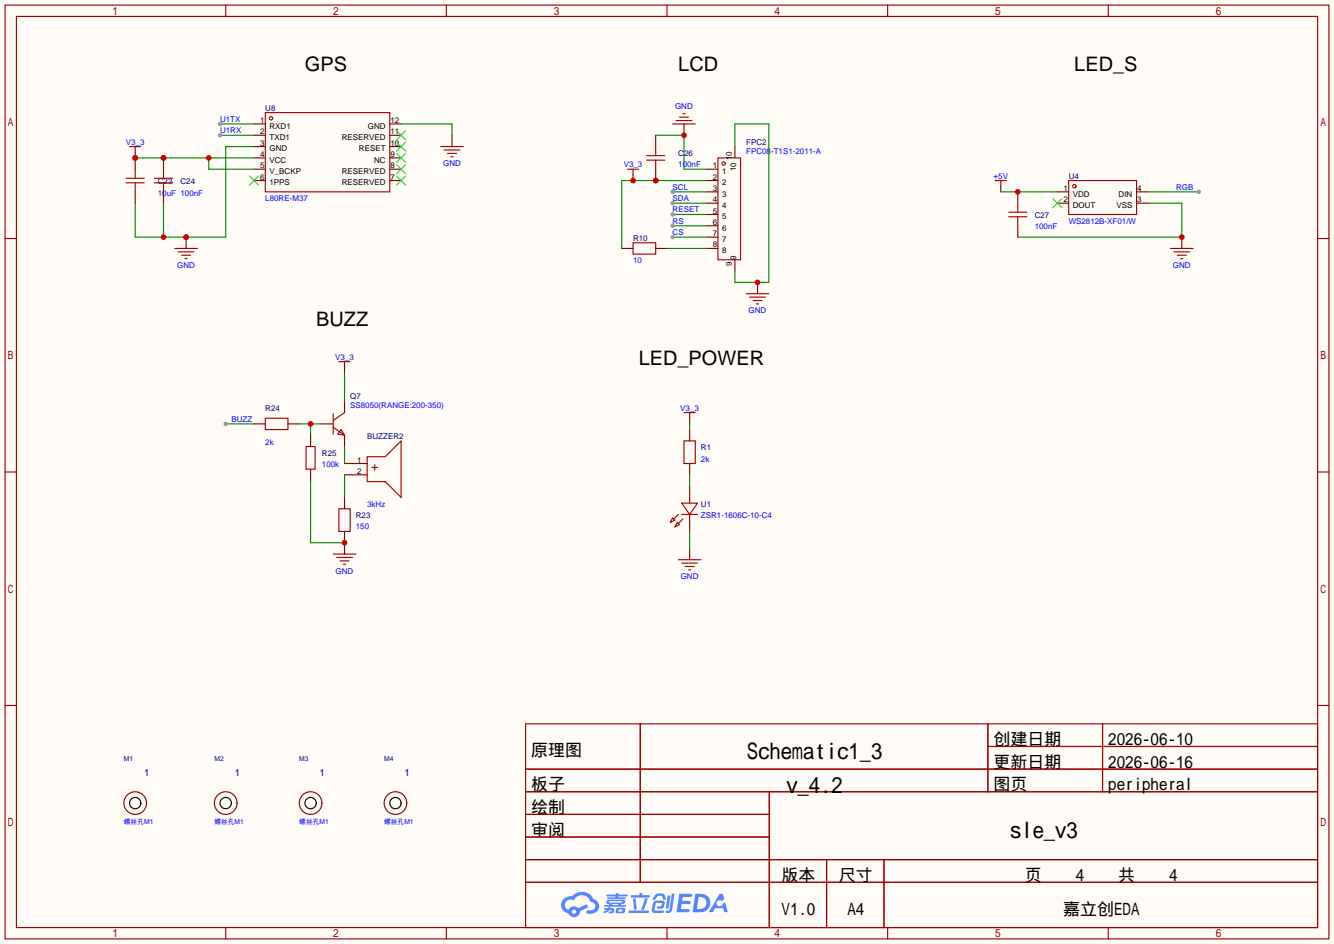
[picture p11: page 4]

原理图 | Schematic1_3 | 创建日期 | 2026-06-10

更新日期 | 2026-06-16

板子 | v_4.2 | 图页 | peripheral
绘制 | | sle_v3
审阅

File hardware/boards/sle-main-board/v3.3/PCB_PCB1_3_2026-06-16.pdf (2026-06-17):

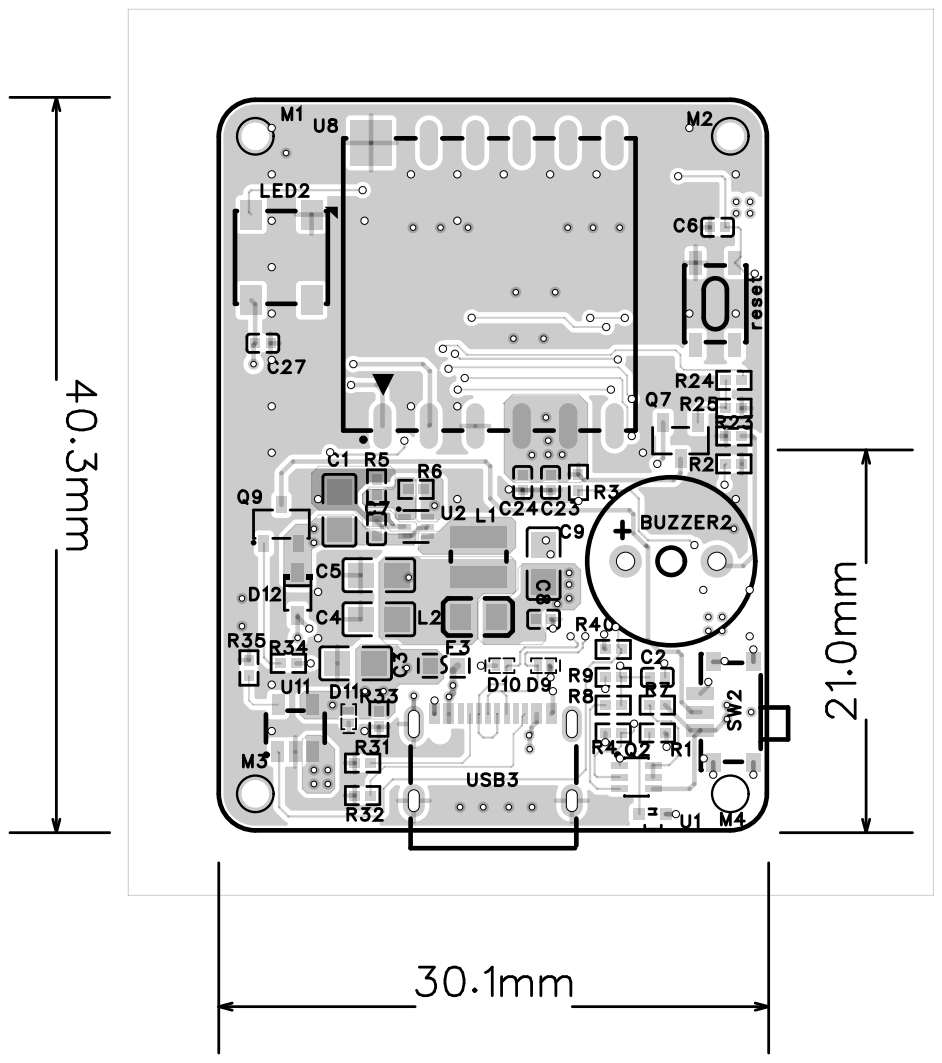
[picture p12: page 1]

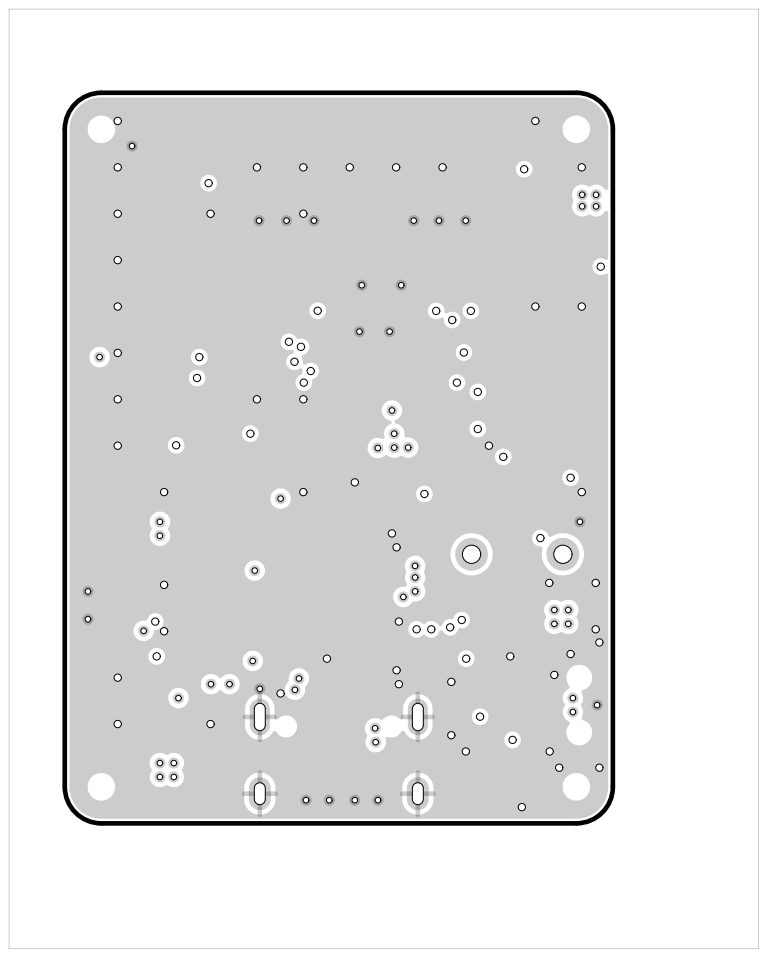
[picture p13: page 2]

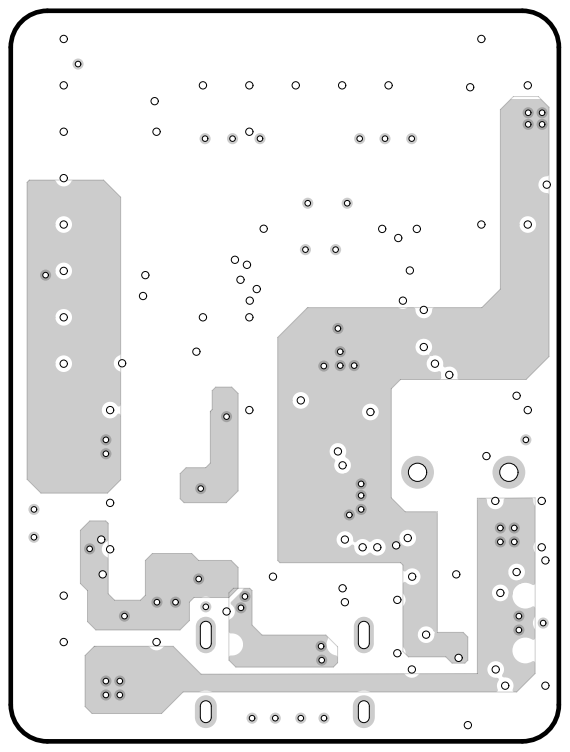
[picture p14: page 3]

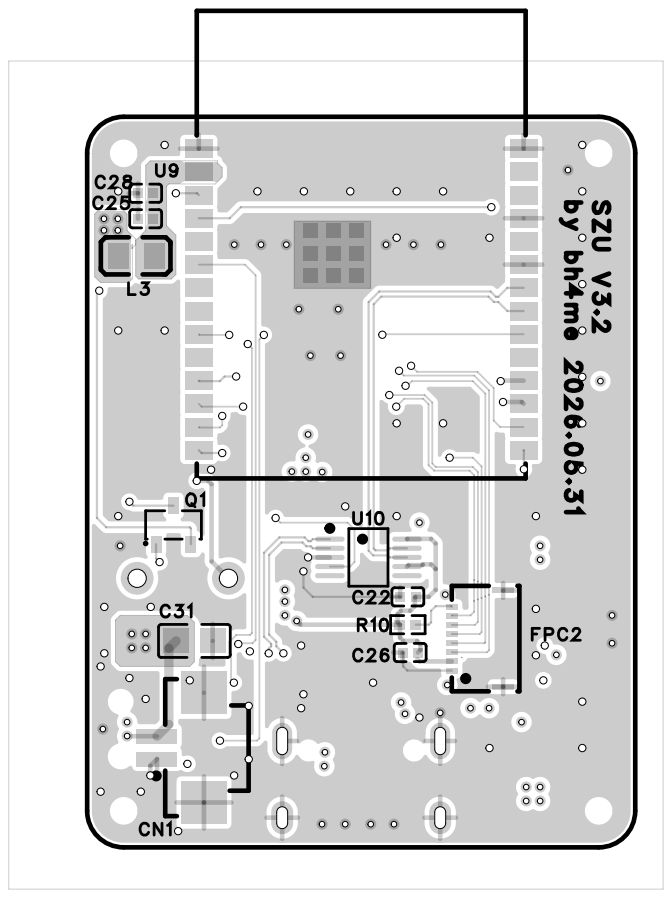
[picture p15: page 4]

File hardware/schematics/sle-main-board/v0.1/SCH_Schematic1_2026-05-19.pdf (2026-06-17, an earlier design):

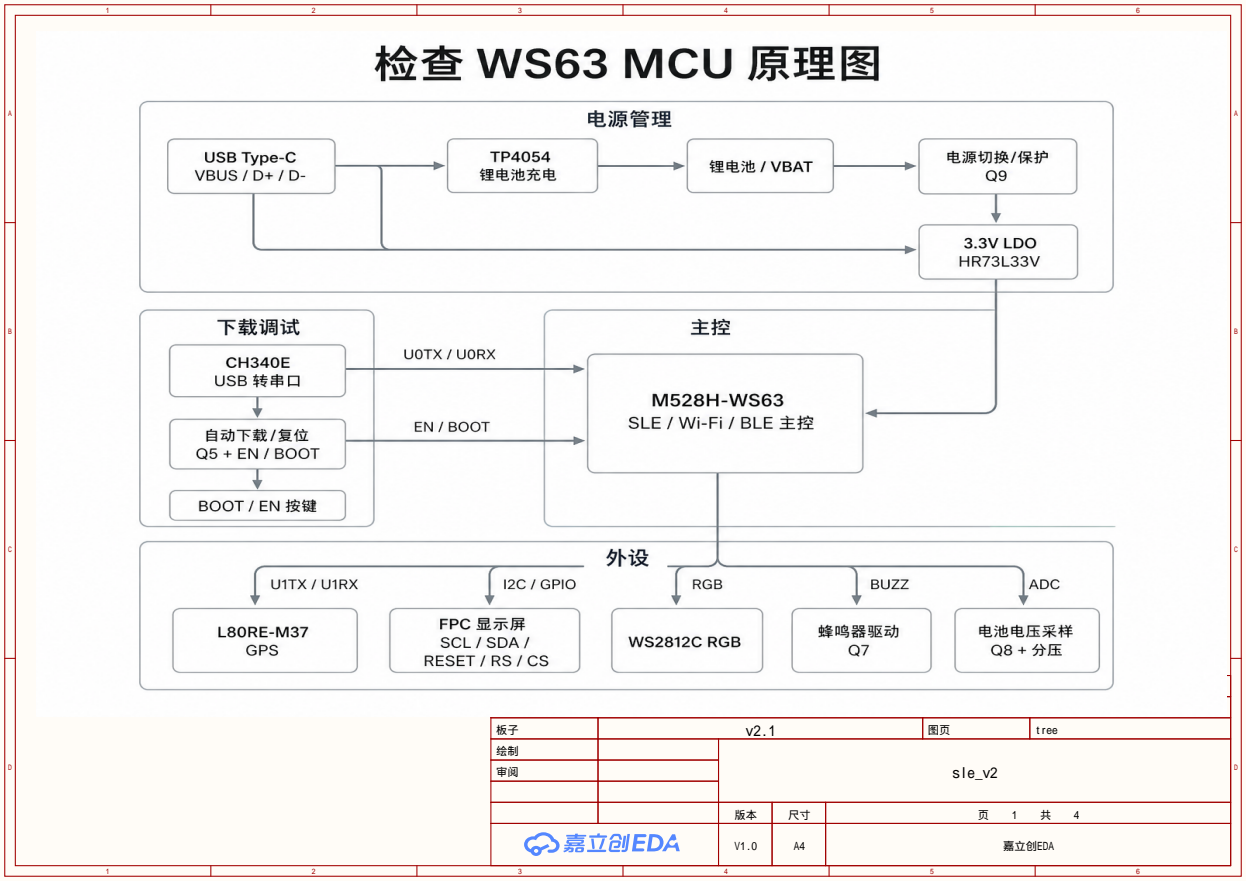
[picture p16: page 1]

原理图 | Schematic1 | 创建日期 | 2026-05-14

更新日期 | 2026-05-19

板子 | v2.1 | 图页 | tree

绘制 | | sle_v2
审阅

V1.0 | A4 | 嘉立创EDA

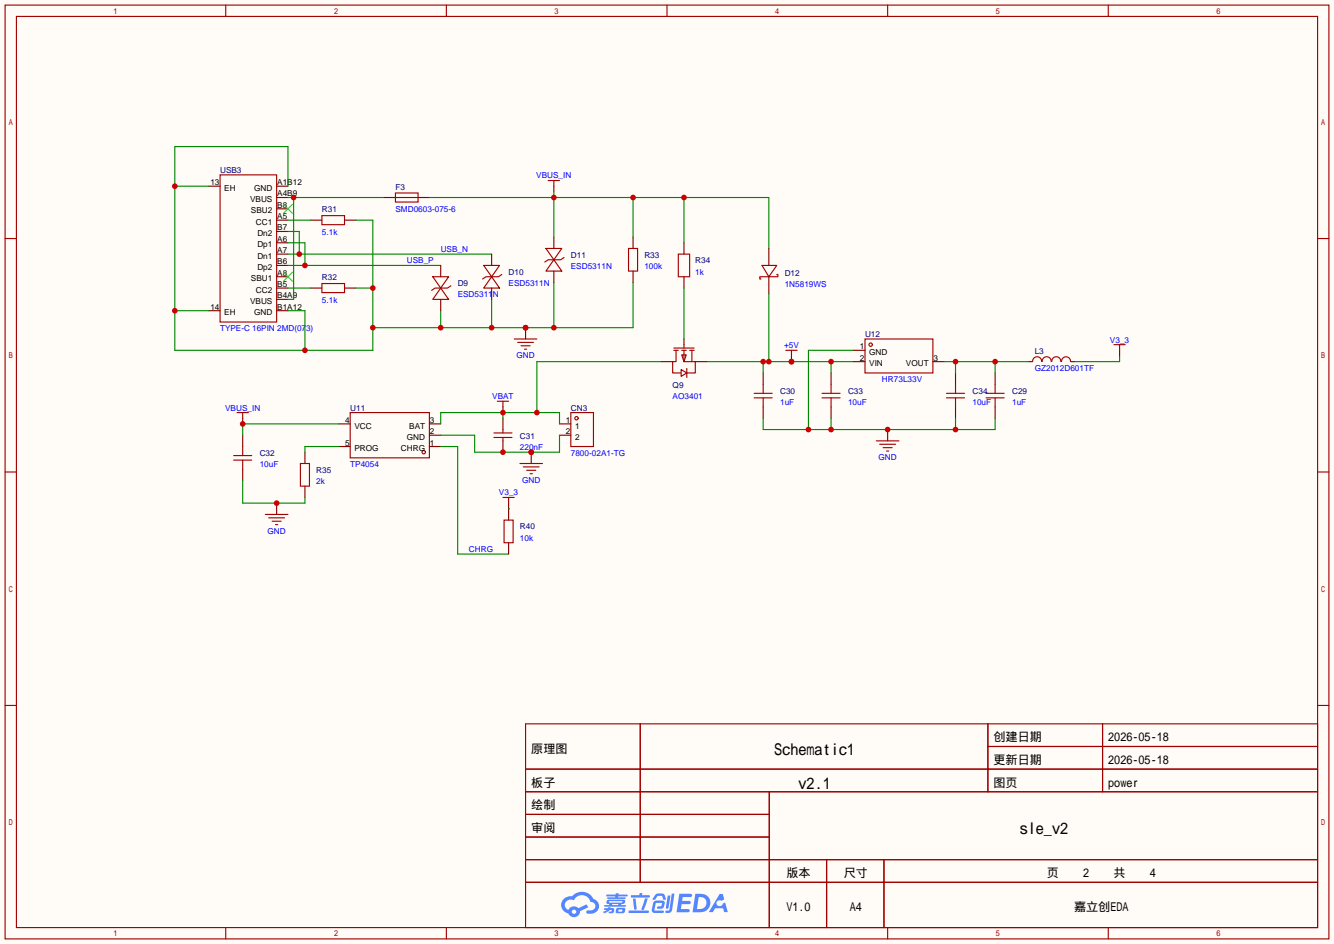
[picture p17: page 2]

原理图 | Schematic1 | 创建日期 | 2026-05-18

更新日期 | 2026-05-18

板子 | v2.1 | 图页 | power

绘制 | | sle_v2
审阅

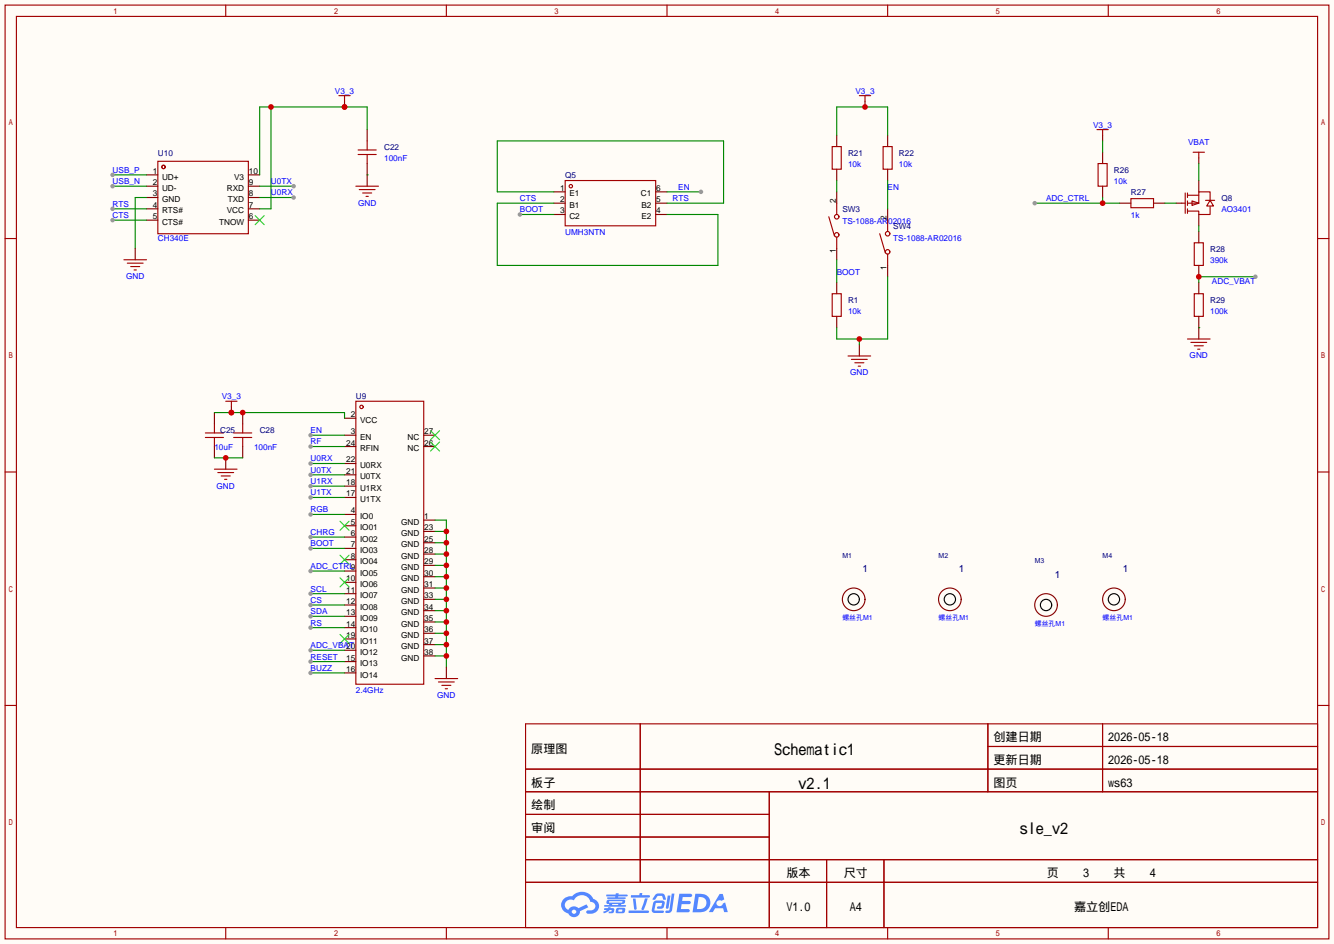
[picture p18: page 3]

原理图 | Schematic1 | 创建日期 | 2026-05-18

更新日期 | 2026-05-18

绘制 | | sle_v2
审阅

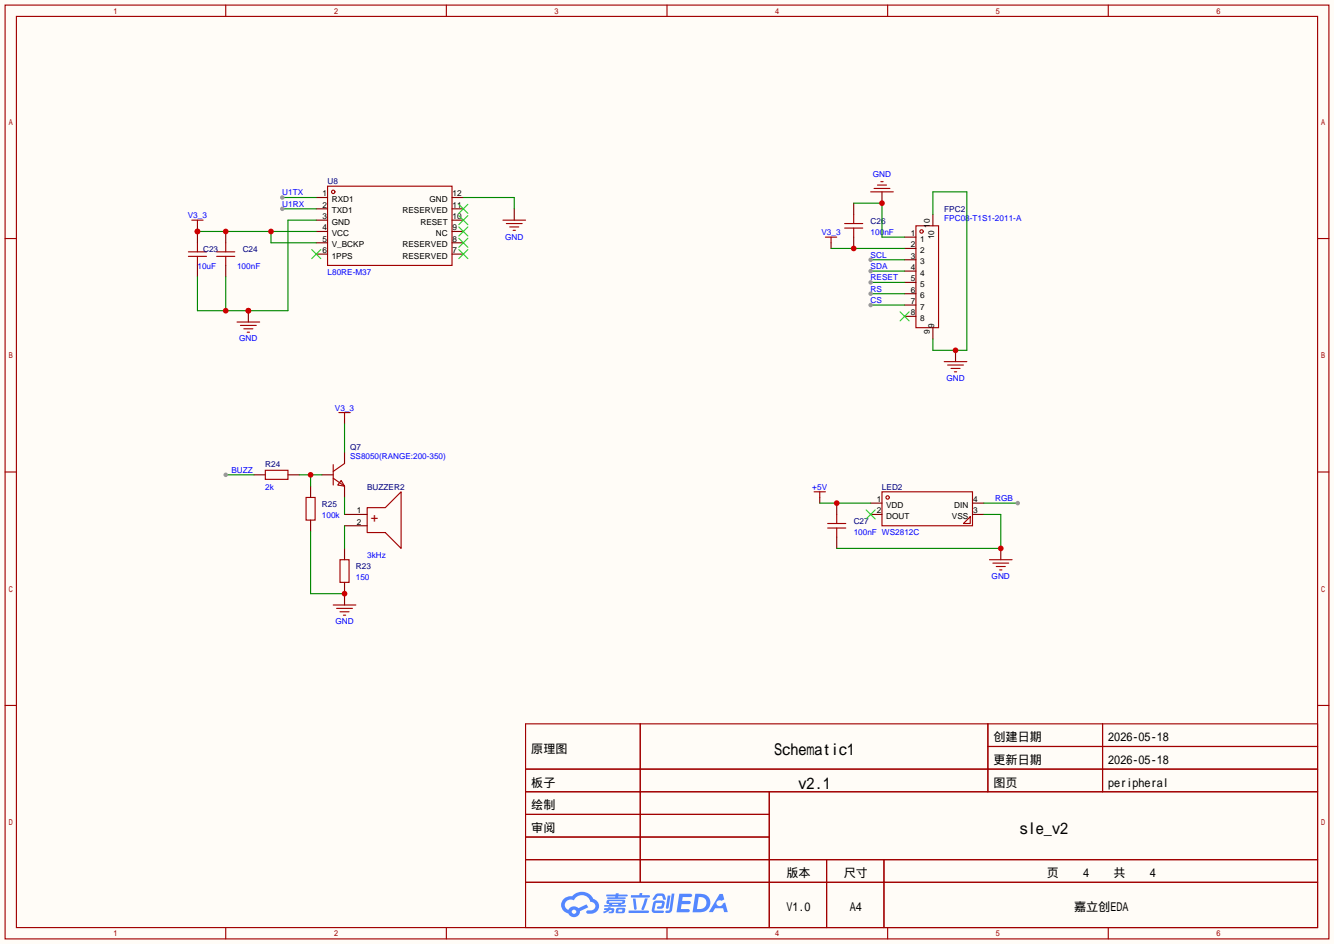
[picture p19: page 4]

原理图 | Schematic1 | 创建日期 | 2026-05-18

更新日期 | 2026-05-18

板子 | v2.1 | 图页 | peripheral

绘制 | | sle_v2
审阅

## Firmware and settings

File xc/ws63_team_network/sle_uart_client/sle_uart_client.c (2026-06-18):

/**
 * Copyright (c) HiSilicon (Shanghai) Technologies Co., Ltd. 2023-2023. All rights reserved.
 *
 * Description: SLE uart sample of client. \n
 *
 * History: \n
 * 2023-04-03, Create file. \n
 */
#include "common_def.h"
#include "soc_osal.h"
#include "securec.h"
#include "product.h"
#include "bts_le_gap.h"
#include "osal_timer.h"
#include "tcxo.h"

#include "sle_errcode.h"
#include "sle_device_discovery.h"
#include "sle_connection_manager.h"
#include "sle_team_packet.h"
#include "sle_uart_client.h"
#include "sle_uart_server_adv.h"
#define SLE_MTU_SIZE_DEFAULT            520
#define SLE_SEEK_INTERVAL_DEFAULT       100
#define SLE_SEEK_WINDOW_DEFAULT         100
#define UUID_16BIT_LEN                  2
#define UUID_128BIT_LEN                 16
#define SLE_UART_TASK_DELAY_MS          1000
#define SLE_UART_RECV_CNT               1000
#define SLE_UART_LOW_LATENCY_2K         2000
#ifndef SLE_UART_SERVER_NAME
#define SLE_UART_SERVER_NAME            "sle_uart_server"
#endif
#define SLE_UART_CLIENT_LOG             "[sle uart client]"
#define SLE_UART_CLIENT_MAX_CON         8
#define SLE_UART_MEMBER_ID_MAX          254U
#define SLE_UART_BROADCAST_ID           0xFFU
#define SLE_UART_DEFAULT_PROPERTY_HANDLE 2U
#define SLE_UART_RSSI_FAIL_RECOVER_THRESHOLD 3U
#define SLE_UART_RSSI_FAIL_ACTIVITY_GRACE_MS 8000U
#define SLE_UART_SCAN_RESTART_MIN_INTERVAL_MS 1200U
#define SLE_UART_FORCE_RESCAN_MIN_INTERVAL_MS 2500U
#define SLE_UART_SEEK_SAMPLE_LOG_INTERVAL_MS 8000U
#define SLE_UART_CONNECT_SEEK_STOP_TIMEOUT_MS 800U
#define SLE_UART_CONNECT_INFLIGHT_TIMEOUT_MS 6000U

static ssapc_find_service_result_t g_sle_uart_find_service_result = { 0 };
static sle_announce_seek_callbacks_t g_sle_uart_seek_cbk = { 0 };
static ssapc_callbacks_t g_sle_uart_ssapc_cbk = { 0 };
static sle_addr_t g_sle_uart_remote_addr = { 0 };
ssapc_write_param_t g_sle_uart_send_param = { 0 };
static sle_uart_client_seek_filter_cb g_sle_uart_seek_filter = NULL;
static void *g_sle_uart_seek_filter_user_ctx = NULL;

/*
 * One physical SLE ACL link as seen by the local client role.
 *
 * The mesh core works with logical route IDs. This table is the bridge between
 * a route/member ID and the SDK connection ID/property handle used for writes.
 */
typedef struct {
    uint8_t active;
    uint16_t conn_id;
    uint8_t member_id;
    int8_t rssi;
    uint8_t rssi_fail_count;
    uint8_t exchange_requested;
    uint8_t ready;
    uint32_t last_activity_ms;
    uint32_t rssi_probe_hold_start_ms;
    sle_addr_t addr;
} sle_uart_client_conn_t;

static sle_uart_client_conn_t g_sle_uart_conns[SLE_UART_CLIENT_MAX_CON];
static uint8_t g_sle_uart_conn_num = 0;
static uint16_t g_sle_uart_last_conn_id = 0;
static uint8_t g_sle_uart_discovery_ready = 0U;
static uint8_t g_sle_uart_enable_inflight = 0U;
static uint8_t g_sle_uart_enabled = 0U;
static uint8_t g_sle_uart_enable_failed = 0U;
static uint32_t g_sle_uart_scan_start_ms = 0U;
static uint8_t g_sle_uart_seek_active = 0U;
static uint8_t g_sle_uart_seek_stop_for_connect = 0U;
static uint8_t g_sle_uart_connect_inflight = 0U;
static uint8_t g_sle_uart_connect_limit = SLE_UART_CLIENT_MAX_CON;

/* Timestamps below bound scan/connect retries so one bad peer cannot stall discovery. */
static uint32_t g_sle_uart_seek_stop_start_ms = 0U;
static uint32_t g_sle_uart_connect_start_ms = 0U;
static uint32_t g_sle_uart_last_force_rescan_ms = 0U;
static uint32_t g_sle_uart_last_seek_sample_log_ms = 0U;
static uint8_t g_sle_uart_force_rescan_pending = 0U;
static volatile uint8_t g_sle_uart_scan_paused = 0U;

static void sle_uart_client_sample_seek_cbk_register(void);
static void sle_uart_client_sample_ssapc_cbk_register(ssapc_notification_callback notification_cb,
    ssapc_notification_callback indication_cb);

static uint32_t sle_uart_client_now_ms(void)
{
    return (uint32_t)uapi_tcxo_get_ms();
}

static uint8_t sle_uart_client_elapsed_ms(uint32_t now_ms, uint32_t start_ms, uint32_t interval_ms)
{
    if (start_ms == 0U) {
        return 1U;
    }
    return (uint8_t)((uint32_t)(now_ms - start_ms) >= interval_ms);
}

static uint8_t sle_uart_client_should_sample_log(uint32_t now_ms, uint32_t *last_ms, uint32_t interval_ms)
{
    if (last_ms == NULL) {
        return 0U;
    }
    if (*last_ms == 0U || sle_uart_client_elapsed_ms(now_ms, *last_ms, interval_ms) != 0U) {
        *last_ms = now_ms;
        return 1U;
    }
    return 0U;
}

static uint8_t sle_uart_client_effective_connect_limit(void)
{
    /* The mesh role can lower the limit, but never above the SDK slot count. */
    if (g_sle_uart_connect_limit == 0U || g_sle_uart_connect_limit > SLE_UART_CLIENT_MAX_CON) {
        return SLE_UART_CLIENT_MAX_CON;
    }
    return g_sle_uart_connect_limit;
}

static uint8_t sle_uart_client_has_connect_capacity(void)
{
    uint8_t used = g_sle_uart_conn_num;

    /* Reserve a slot for the peer that is between "stop seek" and "connected". */
    if (g_sle_uart_connect_inflight != 0U && used < 0xFFU) {
        used++;
    }
    return used < sle_uart_client_effective_connect_limit() ? 1U : 0U;
}

static void sle_uart_client_clear_connect_inflight(void)
{
    /* Clear the transport-level pending-connect latch after success/failure. */
    g_sle_uart_connect_inflight = 0U;
    g_sle_uart_connect_start_ms = 0U;
}

void sle_uart_client_set_connect_limit(uint8_t max_conns)
{
    uint8_t limit = max_conns;

    if (limit == 0U || limit > SLE_UART_CLIENT_MAX_CON) {
        limit = SLE_UART_CLIENT_MAX_CON;
    }
    if (g_sle_uart_connect_limit == limit) {
        return;
    }
    g_sle_uart_connect_limit = limit;
    osal_printk("%s connect limit=%u hw_max=%u\r\n", SLE_UART_CLIENT_LOG,
        g_sle_uart_connect_limit, SLE_UART_CLIENT_MAX_CON);
}

static uint8_t sle_uart_client_conn_has_recent_activity(const sle_uart_client_conn_t *conn, uint32_t now_ms)
{
    if (conn == NULL || conn->last_activity_ms == 0U) {
        return 0U;
    }
    return (uint8_t)(sle_uart_client_elapsed_ms(now_ms, conn->last_activity_ms,
        SLE_UART_RSSI_FAIL_ACTIVITY_GRACE_MS) == 0U);
}

static uint8_t sle_uart_client_conn_rssi_probe_held(const sle_uart_client_conn_t *conn, uint32_t now_ms)
{
    if (conn == NULL || conn->rssi_probe_hold_start_ms == 0U) {
        return 0U;
    }
    return (uint8_t)(sle_uart_client_elapsed_ms(now_ms, conn->rssi_probe_hold_start_ms,
        SLE_UART_RSSI_FAIL_ACTIVITY_GRACE_MS) == 0U);
}

static uint8_t sle_uart_client_buffer_contains(const uint8_t *buf, size_t buf_len,
    const char *needle, size_t needle_len)
{
    size_t i;

    if (buf == NULL || needle == NULL || needle_len == 0U || buf_len < needle_len) {
        return 0U;
    }
    for (i = 0U; i + needle_len <= buf_len; i++) {
        if (memcmp(buf + i, needle, needle_len) == 0) {
            return 1U;
        }
    }
    return 0U;
}
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

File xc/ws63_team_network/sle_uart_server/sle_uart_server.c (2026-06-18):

/**
 * Copyright (c) HiSilicon (Shanghai) Technologies Co., Ltd. 2023-2023. All rights reserved.
 *
 * Description: SLE UART Server Source. \n
 *
 * History: \n
 * 2023-07-17, Create file. \n
 */
#include "common_def.h"
#include "securec.h"
#include "soc_osal.h"
#include "sle_errcode.h"
#include "sle_connection_manager.h"
#include "sle_device_discovery.h"
#include "sle_team_packet.h"
#include "sle_uart_server_adv.h"
#include "sle_uart_server.h"
#define OCTET_BIT_LEN           8
#define UUID_LEN_2              2
#define UUID_INDEX              14
#define BT_INDEX_4              4
#define BT_INDEX_0              0
#define UART_BUFF_LENGTH        0x100
#define SLE_UART_SERVER_MAX_CONNECTIONS 8
#define SLE_UART_MEMBER_ID_MAX 254U
#define SLE_UART_BROADCAST_ID 0xFFU

/* 广播ID */
#define SLE_ADV_HANDLE_DEFAULT  1
/* sle server app uuid for test */
static char g_sle_uuid_app_uuid[UUID_LEN_2] = { 0x12, 0x34 };
/* server notify property uuid for test */
static char g_sle_property_value[OCTET_BIT_LEN] = { 0x0, 0x0, 0x0, 0x0, 0x0, 0x0 };

/*
 * Server-side physical connection table.
 *
 * Leaders and relays accept inbound SLE links here. The mesh app later binds a
 * logical member route ID to each SDK conn_id after it sees a valid packet.
 */
typedef struct {
    uint8_t active;
    uint16_t conn_id;
    uint8_t member_id;
    int8_t rssi;
    sle_addr_t addr;
} sle_uart_server_conn_t;

static sle_uart_server_conn_t g_sle_conns[SLE_UART_SERVER_MAX_CONNECTIONS];
static uint8_t g_sle_conn_count = 0;
/* sle server handle */
static uint8_t g_server_id = 0;
/* sle service handle */
static uint16_t g_service_handle = 0;
/* sle ntf property handle */
static uint16_t g_property_handle = 0;
/* sle pair acb handle */
uint16_t g_sle_pair_hdl;

#define UUID_16BIT_LEN 2
#define UUID_128BIT_LEN 16
#define sample_at_log_print(fmt, args...) osal_printk(fmt, ##args)
#define SLE_UART_SERVER_LOG "[sle uart server]"
#define SLE_SERVER_INIT_DELAY_MS    1000
static sle_uart_server_msg_queue g_sle_uart_server_msg_queue = NULL;
static uint8_t g_sle_uart_base[] = { 0x37, 0xBE, 0xA8, 0x80, 0xFC, 0x70, 0x11, 0xEA, \
    0xB7, 0x20, 0x00, 0x00, 0x00, 0x00, 0x00, 0x00 };

uint16_t get_connect_id(void)
{
    for (uint8_t i = 0; i < SLE_UART_SERVER_MAX_CONNECTIONS; i++) {
        if (g_sle_conns[i].active != 0U) {
            return g_sle_conns[i].conn_id;
        }
    }
    return 0;
}

int8_t sle_uart_server_get_last_rssi(void)
{
    for (uint8_t i = 0; i < SLE_UART_SERVER_MAX_CONNECTIONS; i++) {
        if (g_sle_conns[i].active != 0U) {
            return g_sle_conns[i].rssi;
        }
    }
    return SLE_TEAM_RSSI_UNKNOWN;
}

errcode_t sle_uart_server_read_remote_rssi(void)
{
    uint8_t requested = 0U;

    /* RSSI is sampled for relay optimization; packet liveness remains separate. */
    for (uint8_t i = 0; i < SLE_UART_SERVER_MAX_CONNECTIONS; i++) {
        if (g_sle_conns[i].active == 0U) {
            continue;
        }
        errcode_t ret = sle_read_remote_device_rssi(g_sle_conns[i].conn_id);
        if (ret == ERRCODE_SLE_SUCCESS) {
            requested = 1U;
        }
    }
    if (requested == 0U) {
        return ERRCODE_SLE_FAIL;
    }
    return ERRCODE_SLE_SUCCESS;
}

static sle_uart_server_conn_t *sle_uart_server_find_conn(uint16_t conn_id)
{
    for (uint8_t i = 0; i < SLE_UART_SERVER_MAX_CONNECTIONS; i++) {
        if (g_sle_conns[i].active != 0U && g_sle_conns[i].conn_id == conn_id) {
            return &g_sle_conns[i];
        }
    }
    return NULL;
}

uint8_t sle_uart_server_has_conn(uint16_t conn_id)
{
    return sle_uart_server_find_conn(conn_id) != NULL ? 1U : 0U;
}

static sle_uart_server_conn_t *sle_uart_server_alloc_conn(uint16_t conn_id)
{
    sle_uart_server_conn_t *conn = sle_uart_server_find_conn(conn_id);
    if (conn != NULL) {
        return conn;
    }
    for (uint8_t i = 0; i < SLE_UART_SERVER_MAX_CONNECTIONS; i++) {
        if (g_sle_conns[i].active == 0U) {
            /* Conn is active before it is bound to a route/member ID. */
            g_sle_conns[i].active = 1U;
            g_sle_conns[i].conn_id = conn_id;
            g_sle_conns[i].member_id = 0U;
            g_sle_conns[i].rssi = SLE_TEAM_RSSI_UNKNOWN;
            g_sle_conn_count++;
            return &g_sle_conns[i];
        }
    }
    return NULL;
}

static sle_uart_server_conn_t *sle_uart_server_find_conn_slot_by_member(uint8_t member_id)
{
    if (member_id == 0U || member_id == SLE_UART_BROADCAST_ID) {
        return NULL;
    }
    for (uint8_t i = 0; i < SLE_UART_SERVER_MAX_CONNECTIONS; i++) {
        if (g_sle_conns[i].active != 0U && g_sle_conns[i].member_id == member_id) {
            return &g_sle_conns[i];
        }
    }
    return NULL;
}

uint16_t sle_uart_server_find_conn_by_member(uint8_t member_id)
{
    sle_uart_server_conn_t *conn = sle_uart_server_find_conn_slot_by_member(member_id);
    return conn == NULL ? 0U : conn->conn_id;
}

uint8_t sle_uart_server_find_conn_by_member_ex(uint8_t member_id, uint16_t *conn_id)
{
    sle_uart_server_conn_t *conn;

    if (conn_id == NULL) {
        return 0U;
    }
    conn = sle_uart_server_find_conn_slot_by_member(member_id);
    if (conn == NULL) {
        return 0U;
    }
    *conn_id = conn->conn_id;
    return 1U;
}

uint8_t sle_uart_server_bind_member_conn(uint8_t member_id, uint16_t conn_id)
{
    sle_uart_server_conn_t *conn;

    if (member_id == 0U || member_id > SLE_UART_MEMBER_ID_MAX) {
        return 0U;
    }
    conn = sle_uart_server_find_conn(conn_id);
    if (conn == NULL) {
        conn = sle_uart_server_alloc_conn(conn_id);
        if (conn == NULL) {
            sample_at_log_print("%s bind member:%u conn_id:%x failed: table full\r\n",
                SLE_UART_SERVER_LOG, member_id, conn_id);
            return 0U;
        }
        sample_at_log_print("%s recover conn_id:%x from packet bind member:%u\r\n",
            SLE_UART_SERVER_LOG, conn_id, member_id);
    }
    /* A logical member may only own one server-side connection slot. */
    for (uint8_t i = 0; i < SLE_UART_SERVER_MAX_CONNECTIONS; i++) {
        if (g_sle_conns[i].active != 0U && g_sle_conns[i].conn_id != conn_id &&
            g_sle_conns[i].member_id == member_id) {
            g_sle_conns[i].member_id = 0U;
        }
    }
    conn->member_id = member_id;
    sample_at_log_print("%s bind member:%u conn_id:%x\r\n", SLE_UART_SERVER_LOG, member_id, conn_id);
    return 1U;
}

static void sle_uart_server_remove_conn(uint16_t conn_id)
{
    sle_uart_server_conn_t *conn = sle_uart_server_find_conn(conn_id);
    if (conn == NULL) {
        return;
    }
    (void)memset_s(conn, sizeof(*conn), 0, sizeof(*conn));
    conn->rssi = SLE_TEAM_RSSI_UNKNOWN;
    if (g_sle_conn_count > 0U) {
        g_sle_conn_count--;
    }
}

static void encode2byte_little(uint8_t *_ptr, uint16_t data)
{
    *(uint8_t *)((_ptr) + 1) = (uint8_t)((data) >> 0x8);
    *(uint8_t *)(_ptr) = (uint8_t)(data);
}
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

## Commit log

2026-06-17 Initial sle_mesh_new handoff
    [sle_enclosure_v1.1.4_battery_slide_cover.stl, sle_enclosure_v1.1.4_one_piece_shell.stl]
2026-06-17 Trim CAD STL handoff to latest three versions
    [sle_enclosure_v2_1_13_no_screen_no_battery_bottom_cover.stl, sle_enclosure_v2_1_13_no_screen_no_battery_top_cover.stl, sle_enclosure_v2_1_14_transparent_insert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]
2026-06-17 Remove older STL assets from handoff
    [sle_enclosure_v1.1.4_battery_slide_cover.stl, sle_enclosure_v1.1.4_one_piece_shell.stl]
2026-06-17 Add SLE main board v3.3 hardware docs
2026-06-18 release: publish ws63 v4.5.56 mesh firmware
    [sle_enclosure_v2_1_13_no_screen_no_battery_bottom_cover.stl, sle_enclosure_v2_1_13_no_screen_no_battery_top_cover.stl, sle_enclosure_v2_1_14_transparent_insert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]
